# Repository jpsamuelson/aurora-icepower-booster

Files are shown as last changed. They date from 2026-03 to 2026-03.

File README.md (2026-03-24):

# Aurora DSP ICEpower Booster

   

**6-Channel Balanced Audio Interface** — Aurora FreeDSP → ICEpower Amplifier Modules

This board sits between an **Aurora FreeDSP DSP processor** and six **ICEpower Class-D amplifier modules**. It receives 6 balanced audio signals from the DSP, applies adjustable gain (0–11.3 dB), protects the signals, and outputs them as balanced XLR signals.

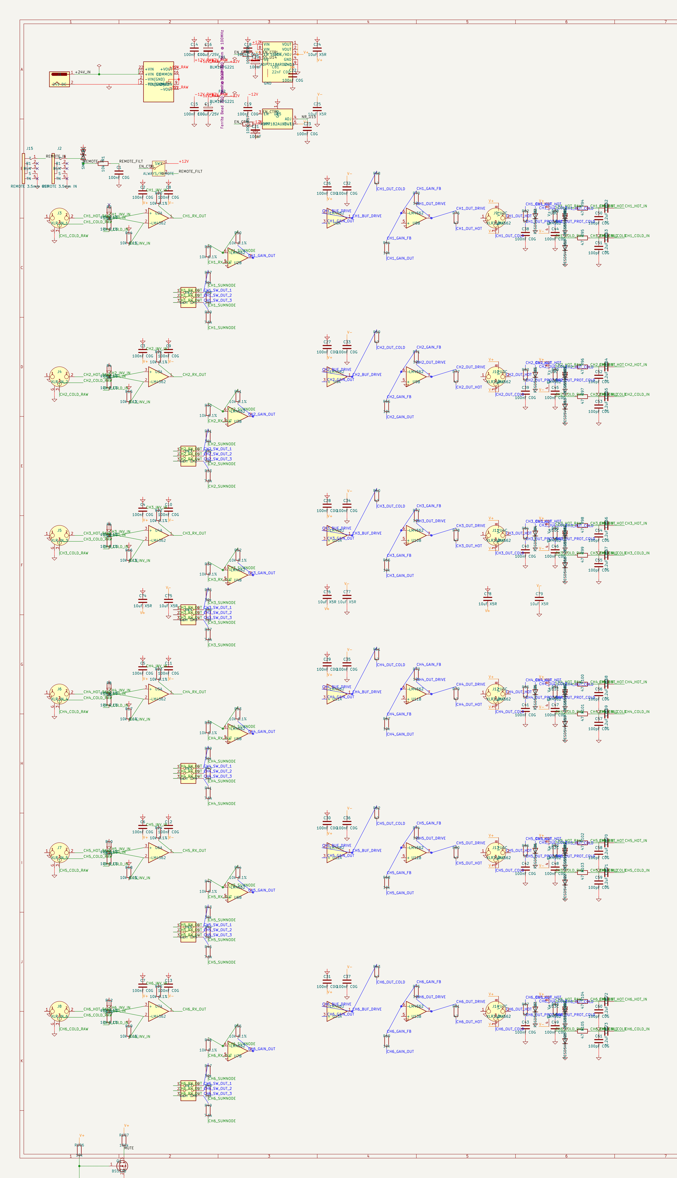
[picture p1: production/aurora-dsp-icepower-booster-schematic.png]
Schematic


---

## Features

- **6 identical channels** — balanced XLR input & output
- **LM4562 low-noise dual op-amps** — THD+N 0.00003%, 2.7 nV/√Hz
- **0–11.3 dB gain** in 8 steps via 3-bit DIP switch per channel
- **100 ms power-on muting** — BSS138 MOSFET chain prevents pop noise
- **Remote enable** via 3.5mm jack (Aurora FreeDSP compatible)
- **Full ESD protection** — PESD5V0S1BL on all signal I/O, SMBJ15CA on remote
- **Isolated power supply** — TRACO TEL5-2422 DC/DC → ADP7118/ADP7182 LDOs (±11V)
- **JLCPCB-ready** — 2-layer FR-4, all components LCSC-available

---

## Specifications

| Parameter | Value |
|---|---|
| Channels | 6 (identical) |
| Input | 6× XLR Female, Pin 2 = Hot, Pin 3 = Cold, Pin 1 = GND |
| Output | 6× XLR Male, Pin 2 = Hot, Pin 3 = Cold, Pin 1 = GND |
| Power Supply | 24V DC (Barrel Jack) |
| Op-Amp Supply | ±11V (low-noise LDO) |
| Gain Range | 0 dB to +11.3 dB (8 steps via DIP switch) |
| Input Impedance | ~10 kΩ balanced |
| Output Impedance | ~47Ω (series R) |
| Input CMRR | ~62 dB (4× 10kΩ 0.1% metal film) |
| SNR Target | > 100 dB |
| THD+N Target | < 0.01% @ 1 kHz |
| Remote Interface | KH-PJ-320EA-5P-SMT 3.5mm jack (Aurora FreeDSP Custom Out) |
| Manufacturing | JLCPCB, 2-Layer, FR-4, HASL, 145.6 × 200 mm |

---

## System Overview

```mermaid
graph LR
    DSP["Aurora FreeDSP\n(6× XLR Out)"]
    BOARD["Aurora DSP\nICEpower Booster"]
    AMP1["ICEpower #1"]
    AMP2["ICEpower #2"]
    AMP3["ICEpower #3"]
    AMP4["ICEpower #4"]
    AMP5["ICEpower #5"]
    AMP6["ICEpower #6"]
    PSU["24V DC\nPower Supply"]
    REMOTE["FreeDSP\nRemote Out"]

    DSP -->|"CH1 XLR Balanced"| BOARD
    DSP -->|"CH2 XLR Balanced"| BOARD
    DSP -->|"CH3 XLR Balanced"| BOARD
    DSP -->|"CH4 XLR Balanced"| BOARD
    DSP -->|"CH5 XLR Balanced"| BOARD
    DSP -->|"CH6 XLR Balanced"| BOARD
    PSU -->|"24V"| BOARD
    REMOTE -->|"3.5mm Enable"| BOARD
    BOARD -->|"CH1 +Gain"| AMP1
    BOARD -->|"CH2 +Gain"| AMP2
    BOARD -->|"CH3 +Gain"| AMP3
    BOARD -->|"CH4 +Gain"| AMP4
    BOARD -->|"CH5 +Gain"| AMP5
    BOARD -->|"CH6 +Gain"| AMP6
```

---

## Signal Chain Overview

All 6 channels are **identical**. Each channel consists of 5 stages:

```mermaid
flowchart LR
    XIN["XLR IN\nJ3–J8"]
    ESD1["ESD Protection\nInput"]
    EMI["EMI Filter\n47Ω + 100pF"]
    DC["DC Blocking\n2.2µF C0G"]
    DIFF["Diff Receiver\nLM4562 Unit A"]
    GAIN["Gain Stage\nLM4562 Unit B"]
    MUTE["Muting\nBSS138"]
    DRV["Balanced Driver\nLM4562 (2nd IC)"]
    ZOB["Zobel\n10Ω + 100nF"]
    ESD2["ESD Protection\nOutput"]
    XOUT["XLR OUT\nJ9–J14"]

    XIN --> ESD1 --> EMI --> DC --> DIFF --> GAIN --> MUTE --> DRV --> ZOB --> ESD2 --> XOUT
```

| Stage | Function | Key Components |
|---|---|---|
| 1. ESD & EMI Filter | Overvoltage protection + RF filtering | PESD5V0S1BL, 47Ω + 100pF, 2.2µF C0G DC blocking |
| 2. Diff Receiver | Balanced → single-ended, CMRR ~62 dB | LM4562 Unit A, 4× 10kΩ 0.1% |
| 3. Gain Stage | Inverting amp, 0–11.3 dB adjustable | LM4562 Unit B, DIP switch + 3 parallel R |
| 4. Muting | Power-on pop suppression, τ = 100 ms | BSS138 N-MOSFET, RC timing |
| 5. Balanced Driver | Single-ended → balanced output | LM4562 (buffer + inverter), 47Ω series R, Zobel network |

**→ [Full signal chain documentation with schematics and formulas](docs/signal-chain.md)**

---

## Gain Configuration

| SW Pos 1 (30kΩ) | SW Pos 2 (15kΩ) | SW Pos 3 (7.5kΩ) | Gain (dB) |
|:---:|:---:|:---:|---:|
| OFF | OFF | OFF | 0.0 dB |
| OFF | OFF | ON | +2.5 dB |
| OFF | ON | OFF | +4.4 dB |
| OFF | ON | ON | +6.0 dB |
| ON | OFF | OFF | +7.4 dB |
| ON | OFF | ON | +8.5 dB |
| ON | ON | OFF | +9.5 dB |
| ON | ON | ON | **+11.3 dB** |

$$G = \frac{R_f}{R_{in,eff}} \quad\text{with}\quad R_{in,eff} = R_{base} \parallel R_{pos1} \parallel R_{pos2} \parallel R_{pos3}$$

**→ [Full gain configuration details](docs/gain-configuration.md)**

---

## PCB Layout

| Parameter | Value |
|---|---|
| Board Size | 145.6 × 200 mm |
| Layers | 2 (F.Cu + B.Cu) |
| Footprints | 269 |
| Nets | 135 in 5 net classes |
| Routing | Freerouting v2.0.1 — 1543 segments + 476 vias |
| GND Zones | F.Cu (solid connect) + B.Cu (thermal relief) |
| DRC | 0 Errors, 0 Unconnected, 198 Warnings (cosmetic) |

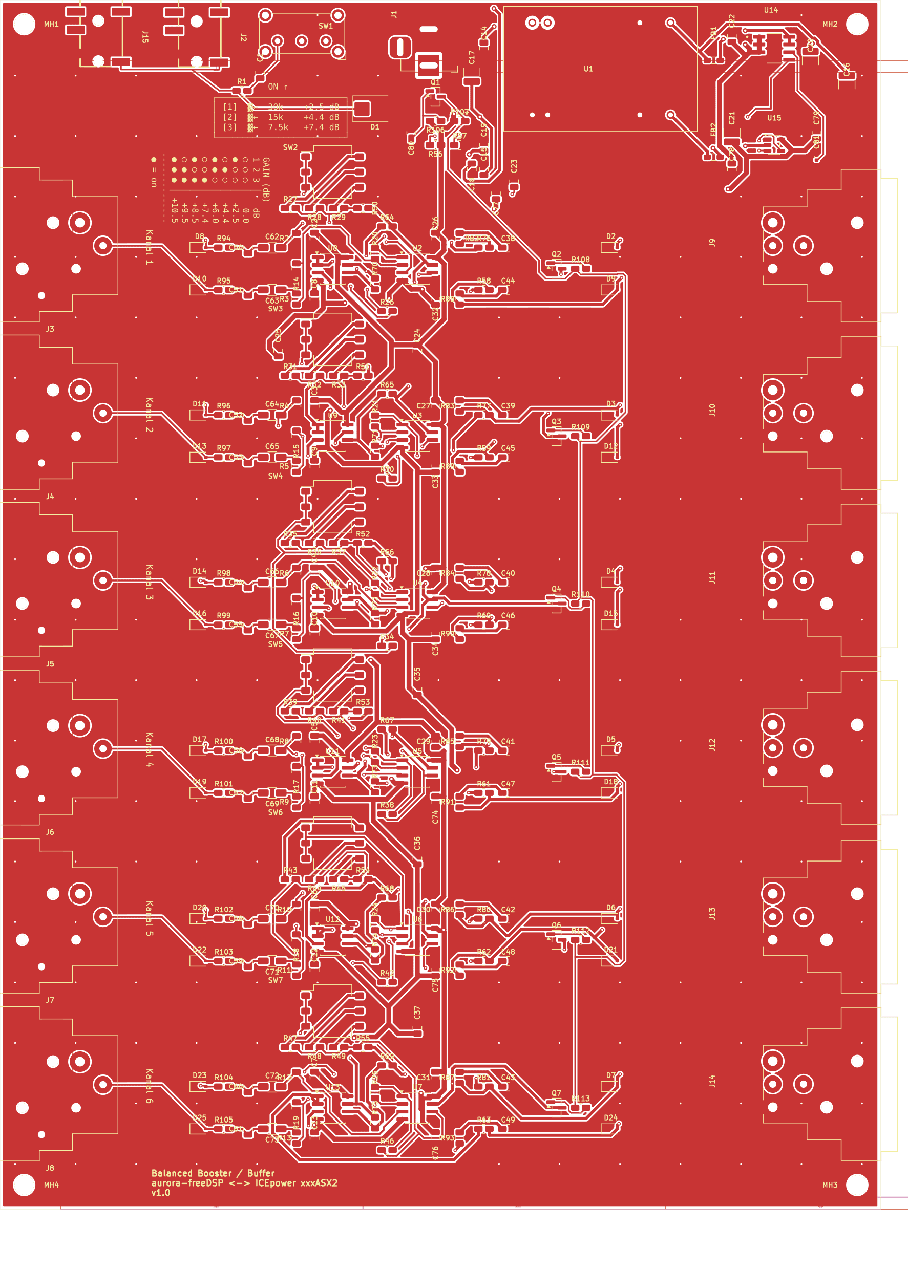
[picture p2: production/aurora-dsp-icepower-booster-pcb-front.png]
PCB Front


| Net Class | Nets | Track Width | Clearance |
|---|---|---|---|
| Default | 62 | 0.25 mm | 0.2 mm |
| Audio_Input | 30 | 0.3 mm | 0.25 mm |
| Audio_Output | 36 | 0.5 mm | 0.2 mm |
| Audio_Power | 0 | 0.8 mm | 0.2 mm |
| Power | 7 | 0.5 mm | 0.2 mm |

**→ [PCB layout details & DRC breakdown](docs/pcb-layout.md)**

---

## Manufacturing

Production files are ready in the `production/` directory:

- **Gerber + Drill** — `production/gerber/` (JLCPCB format, Protel extensions, tented vias)
- **BOM + Placement** — `production/assembly/` (JLCPCB SMT assembly format)

---

## Validation

| Method | Checks | Result |
|---|---|---|
| **Method 1** — OrcadPCB2 netlist, component-centric | 85/85 | ✅ |
| **Method 2** — KiCad-native netlist, net-centric (pintype/pinfunction) | 177/177 | ✅ |

> All component references, net names, and pin assignments in the documentation were extracted directly from the verified KiCad netlist and are sufficient to fully rebuild the schematic without the `.kicad_sch` file.

---

## Documentation

| Document | Description |
|---|---|
| **[Signal Chain](docs/signal-chain.md)** | Detailed 5-stage signal path with Mermaid diagrams, formulas, and per-stage component tables |
| **[Power Supply](docs/power-supply.md)** | DC/DC converter, LDOs, ferrite beads, decoupling architecture |
| **[Muting & Remote Control](docs/muting-and-remote.md)** | Remote enable logic, muting timing, SPDT switch modes |
| **[Gain Configuration](docs/gain-configuration.md)** | DIP switch table, gain formula, per-channel resistor mapping |
| **[Component Reference](docs/component-reference.md)** | Complete BOM with all 242 symbols: R, C, D, J, SW, Q, U, FB |
| **[Schematic Rebuild Guide](docs/schematic-rebuild-guide.md)** | Step-by-step wiring instructions + full 6-channel component mapping |
| **[PCB Layout](docs/pcb-layout.md)** | Net classes, DRC status, routing details |
| **[Research: Balanced Audio ICs](docs/research/balanced-audio-ic-comparison.md)** | THAT1240, DRV135, SSM2143, LM4562 comparison & JLCPCB availability |
| **[Research: THT Precision Components](docs/research/tht-precision-components.md)** | 0.1% resistors, C0G capacitors, THT sourcing guide |

---

## Project Structure

This project is **self-contained** — all footprints and 3D models are included locally.

```
├── aurora-dsp-icepower-booster.kicad_pro   # Project
├── aurora-dsp-icepower-booster.kicad_sch   # Schematic
├── aurora-dsp-icepower-booster.kicad_pcb   # PCB Layout
├── aurora-dsp-icepower-booster.kicad_sym   # Local symbols
├── aurora-dsp-icepower-booster.kicad_dru   # Custom design rules
├── footprints.pretty/                      # 21 footprints (local)
│   └── 3dshapes/                           # 19 STEP 3D models
├── production/
│   ├── gerber/                             # Manufacturing data
│   └── assembly/                           # BOM + placement data
├── docs/                                   # Detailed documentation
│   ├── signal-chain.md
│   ├── power-supply.md
│   ├── muting-and-remote.md
│   ├── gain-configuration.md
│   ├── component-reference.md
│   ├── schematic-rebuild-guide.md
│   ├── pcb-layout.md
│   └── research/
│       ├── balanced-audio-ic-comparison.md
│       └── tht-precision-components.md
└── scripts/                                # Build & validation scripts
```

---

*Schematic: KiCad 9 — `aurora-dsp-icepower-booster.kicad_sch`*
*Manufacturing: JLCPCB 2-Layer FR-4 HASL — Gerber files in `production/gerber/`*

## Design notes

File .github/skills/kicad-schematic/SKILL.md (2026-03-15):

---
name: kicad-schematic
description: "KiCad 9 schematic & PCB manipulation via Python scripts and kicad-cli. USE FOR: editing .kicad_sch files, adding/moving/wiring components, lib_symbols cache management, pin position calculation, ERC/netlist validation, S-expression format manipulation, quality gate checks. TRIGGERS: kicad, schematic, symbol, footprint, wire, net, ERC, DRC, pcb layout, routing, S-expression, lib_symbols, pin position."
argument-hint: "Describe what schematic change or validation you need"
---

# KiCad Schematic & PCB Manipulation

## When to Use

- Editing `.kicad_sch` or `.kicad_pcb` files
- Adding, modifying, or wiring components
- Managing lib_symbols cache entries
- Calculating pin positions for wire routing
- Running ERC/DRC/netlist validation
- Quality gate checks before fabrication
- Any S-expression file manipulation

## Critical Rules (NEVER VIOLATE)

### 1. Terminal — Kein Inline-Python

zsh im Copilot-Terminal korrumpiert heredocs und inline Python.

- **IMMER** `.py`-Datei schreiben → `python3 datei.py` ausführen
- **NIE** `python3 -c "..."` oder `cat << 'EOF'` verwenden
- **NIE** mehrzeiligen Python-Code im Terminal ausführen

### 2. S-Expression — Klammer-Balance

Nach JEDER Dateiänderung muss die Klammer-Balance geprüft werden:

```python
depth = 0
for ch in content:
    if ch == '(': depth += 1
    elif ch == ')': depth -= 1
assert depth == 0, f"Klammer-Balance: {depth}"
```

### 3. lib_symbols Cache — Sub-Symbol-Naming

Beim Hinzufügen neuer Symbole zur `lib_symbols`-Sektion:

- **Hauptsymbol**: MIT Library-Prefix → `(symbol "Connector_Audio:AudioJack2" ...)`
- **Sub-Symbole**: OHNE Library-Prefix → `(symbol "AudioJack2_0_1" ...)`
- **NIEMALS**: `(symbol "Connector_Audio:AudioJack2_0_1" ...)` — crasht kicad-cli!

### 4. Regex — Keine Cross-Symbol-Suche

`.search(r'lib_id "X".*?Reference.*?J14', text, DOTALL)` matcht über Symbol-Grenzen hinweg.
**Immer** Balanced-Paren-Block zuerst extrahieren, dann darin suchen.
Siehe [S-Expression Reference](./references/s-expression-format.md).

### 5. Validierung — Dreistufig nach jeder Änderung

1. Klammer-Balance prüfen (Python)
2. `kicad-cli sch export netlist` (testet Parser)
3. `kicad-cli sch erc --severity-all` (Baseline-Vergleich)

## Workflow: Schematic-Änderung

```
1. Backup erstellen (.bak_pre_<aktion>)
2. Änderung via Python-Skript
3. Klammer-Balance prüfen
4. kicad-cli Netlist-Export testen
5. kicad-cli ERC ausführen (Baseline: 115 Errors)
6. Netz-Verbindungen im Netlist verifizieren
7. Ergebnis zusammenfassen
```

### Backup-Konvention

```bash
cp aurora-dsp-icepower-booster.kicad_sch aurora-dsp-icepower-booster.kicad_sch.bak_pre_<aktion>
```

## Workflow: Neues Symbol in Schematic einfügen

1. Symbol aus KiCad System-Library extrahieren:
   ```
   /Applications/KiCad/KiCad.app/Contents/SharedSupport/symbols/<Library>.kicad_sym
   ```
2. Hauptsymbol-Block mit Balanced-Paren-Extraktion lesen
3. Sub-Symbol-Naming korrigieren (Library-Prefix entfernen)
4. In lib_symbols-Sektion der .kicad_sch einfügen
5. Symbol-Instanz mit korrekten Properties einfügen
6. Wires und Labels hinzufügen
7. Validierung durchführen

Details: [S-Expression Format Reference](./references/s-expression-format.md)

## Workflow: Wire-Routing

1. Pin-Positionen berechnen (siehe [Pin-Kalkulation](./references/pin-calculation.md))
2. Wire-Segmente als S-Expression erzeugen
3. Labels an Endpunkten platzieren
4. Junctions an Kreuzungspunkten einfügen
5. Validierung via Netlist

## Workflow: Validierung / Quality Gate

Nutze [validate_schematic.py](./scripts/validate_schematic.py) als Basis:

```bash
python3 .github/skills/kicad-schematic/scripts/validate_schematic.py
```

Prüft automatisch:

- Klammer-Balance
- kicad-cli Netlist-Export
- kicad-cli ERC (Baseline-Vergleich)
- Netz-Verbindungen (konfigurierbar)
- Footprint-Existenz
- lib_symbols-Cache-Integrität

## Pin-Naming nach Bibliothek

| Library | Pin-Format | Beispiele |
| --- | --- | --- |
| Device:R, Device:C | Nummern | "1", "2" |
| Connector_Audio:AudioJack2 | Buchstaben | "T" (Tip), "S" (Sleeve) |
| Connector_Audio:XLR3 | Mixed | "1", "2", "3", "G" |
| Connector:Barrel_Jack | Nummern | "1", "2" |
| Amplifier_Operational:LM4562 | Nummern | "1"-"8" |

**Regex für Pin-Matching**: Immer `[^"]+` statt `\d+` verwenden!

## MCP Server — Wann nutzen, wann nicht

| Geeignet | Nicht geeignet |
| --- | --- |
| `open_project`, `get_project_info` | Bulk-Verdrahtung (>10 Wires) |
| `search_symbols`, `search_footprints`  | Multi-Unit-Symbole (extends-Bug) |
| `get_board_info`, `get_component_list` | Zuverlässiges Wire-Routing |
| `export_gerber`, `export_bom` | Schaltpläne >50 Bauteile |
| `sync_schematic_to_board` | Rotation von Bauteilen |

Für alles Komplexe: Python-Skripte + kicad-cli.

## Dateipfade

| Was | Pfad |
| --- | --- |
| Projekt | `/Users/roroor/Documents/Workspace/CAD/Electric/aurora-dsp-icepower-booster/` |
| kicad-cli | `/Applications/KiCad/KiCad.app/Contents/MacOS/kicad-cli` |
| Symbol-Libraries | `/Applications/KiCad/KiCad.app/Contents/SharedSupport/symbols/` |
| Footprint-Libraries | `/Applications/KiCad/KiCad.app/Contents/SharedSupport/footprints/` |
| Custom Symbols | `aurora-dsp-icepower-booster.kicad_sym` |

## ERC Baseline

- **0 Errors** (runterreduziert von 115→66→0)
- **805 Warnings** — Aufschlüsselung:
  - 799 endpoint_off_grid (kosmetisch, MCP-Server 1mm-Raster vs. KiCad 1.27mm — Grid-Snap nicht sicher möglich wegen 25 2D-Kollisionen)
  - 6 label_multiple_wires (SUMNODE T-Kreuzungen — Labels für Netz-Konnektivität nötig, nicht entfernbar)
- **52 echte Warnungen eliminiert** (890→805): 39 isolierte Label-Stubs gelöscht, 6 ???-Stubs mit korrektem XLR-Pin verbunden, 1 Footprint korrigiert
- Neue Änderungen dürfen die Error-Zahl NICHT erhöhen
- Behobene Kategorien: missing_power_pin (12→0), pin_not_connected (19→0), label_dangling (12→0), pin_to_pin (6→0), wire_dangling (66→0), multiple_net_names (6→0), lib_symbol_mismatch (194→0), footprint_link_issues (18→0), unconnected_wire_endpoint (45→0)
- multiple_net_names Fix: CHx_HOT_RAW → CHx_OUT_COLD umbenannt (12 Labels)
- lib_symbols Fix: Device:R, Device:C, Device:D Cache von KiCad 9 Library aktualisiert
- Footprint Fix: XLR-F/M → Neutrik NC3FBH2/NC3MBH, DIP Switch → korrekter Name, TEL5-2422 → Package_DIP:DIP-24_W15.24mm
- Stub Fix: 39 isolierte V+/V-/GND/OUT_COLD Label-Stubs gelöscht (komplett isoliert, keine Konnektivitätsänderung), 6 XLR-Cold-Stubs mit Pin 2 der XLR-Eingangsbuchsen verbunden (MCP-Server Y-Vorzeichen-Fehler korrigiert)
- Neue Netze pro Kanal: INV_IN, SW_OUT_1/2/3, BUF_DRIVE, GAIN_FB, OUT_DRIVE, OUT_PROT_HOT/COLD, EMI_HOT/COLD

## Audio-PCB-Design-Regeln

Vollständige Regeln in [copilot-instructions.md](../../../.github/copilot-instructions.md).
Kurzfassung:

- Ungeteilte GND-Fläche auf B.Cu
- Audio-Traces auf Top-Layer, keine Vias im Signalpfad
- Kein X7R/X5R im Audio-Signalpfad (Mikrofonie!)
- Entkopplung: 100nF C0G direkt am IC + 10µF dahinter
- Schaltregler ≥ 20mm von Audio-Eingangsstufe
- Guard-Traces um empfindliche Audio-Eingänge

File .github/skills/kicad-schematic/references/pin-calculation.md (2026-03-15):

# Pin-Position-Berechnung

## Grundformel

Für ein Symbol an Position `(sx, sy)` mit Rotation `θ` (in Grad):

```
Pin lokal:     (px, py)        ← aus lib_symbols Cache
Rotiert:       (rx, ry) = rotate_ccw(px, py, θ)
Schematisch:   (sx + rx, sy - ry)    ← KiCad Y-Achse invertiert!
```

## Rotation (Counter-Clockwise)

```python
import math

def pin_schematic_position(symbol_x, symbol_y, symbol_rot_deg, pin_local_x, pin_local_y):
    """Berechnet die Schematic-Position eines Pins."""
    theta = math.radians(symbol_rot_deg)
    # CCW-Rotation
    rx = pin_local_x * math.cos(theta) - pin_local_y * math.sin(theta)
    ry = pin_local_x * math.sin(theta) + pin_local_y * math.cos(theta)
    # KiCad: Y-Achse invertiert
    sch_x = symbol_x + rx
    sch_y = symbol_y - ry
    return round(sch_x, 2), round(sch_y, 2)
```

## Schnell-Referenz für Standard-Rotationen

| Symbol-Rotation | Transformation (px, py) → (rx, ry) | Schematic |
|---|---|---|
| 0° | (px, py) → (px, py) | (sx + px, sy - py) |
| 90°  | (px, py) → (-py, px) | (sx - py, sy - px) |
| 180° | (px, py) → (-px, -py) | (sx - px, sy + py) |
| 270° | (px, py) → (py, -px) | (sx + py, sy + px) |

## Beispiel: AudioJack2 bei (40.16, 82.46) @ 180°

```
Pin T lokal: (5.08, 0)
  → rot 180°: (-5.08, 0)
  → schematic: (40.16 + (-5.08), 82.46 - 0) = (35.08, 82.46)

Pin S lokal: (5.08, 2.54)
  → rot 180°: (-5.08, -2.54)
  → schematic: (40.16 + (-5.08), 82.46 - (-2.54)) = (35.08, 85.0)
```

## Pin-Positionen aus lib_symbols lesen

```python
import re

def get_pin_positions(cache_block, symbol_name):
    """Liest Pin-Positionen aus einem lib_symbols Cache-Block."""
    pins = {}
    # Finde Sub-Symbol mit den Pins (typisch: _0_1)
    for m in re.finditer(r'\(pin \w+ \w+ \(at ([\d.]+) ([\d.]+) (\d+)\).*?\(number "([^"]+)"\)', cache_block, re.DOTALL):
        px, py = float(m.group(1)), float(m.group(2))
        pin_angle = int(m.group(3))
        pin_number = m.group(4)
        pins[pin_number] = (px, py, pin_angle)
    return pins
```

## Wire-Endpunkt = Pin-Schematic-Position

Ein Wire muss **exakt** an der berechneten Pin-Schematic-Position beginnen/enden.
Toleranz: ±0.01mm (KiCad-internes Raster).

**WICHTIG**: MCP-erstellte Wires verbinden Pins nur zuverlässig, wenn mindestens ein **Net-Label** im Wire-Chain vorhanden ist. Ohne Label erkennt KiCad die Pin-Verbindung möglicherweise nicht!

```python
# Wire von Pin zu Label (bevorzugt — Label sorgt für zuverlässige Netz-Erkennung)
wire = f'(wire (pts (xy {pin_x} {pin_y}) (xy {label_x} {label_y})) (stroke (width 0) (type default)) (uuid "{uuid}"))'
label = f'(label "{net_name}" (at {label_x} {label_y} 0) (fields_autoplaced yes) (effects (font (size 1.27 1.27)) (justify left bottom)) (uuid "{label_uuid}"))'
```

## Pin-Richtung (für Wire-Routing)

Der `pin_angle` (0°, 90°, 180°, 270°) gibt die Richtung an, in die der Pin zeigt.
Wire sollte in die **entgegengesetzte** Richtung verlaufen:

| Pin-Winkel | Pin zeigt nach | Wire geht nach |
|---|---|---|
| 0° | Rechts | Links vom Pin  |
| 90° | Oben | Unten vom Pin  |
| 180° | Links | Rechts vom Pin |
| 270° | Unten | Oben vom Pin |

Bei 180°-Pin (zeigt nach links): Wire geht nach rechts → höhere X-Koordinaten.

## Häufig verwendete Symbol-Positionen

### LM4562 (SOIC-8, keine Rotation)

**ACHTUNG**: Die Pin-Positionen stammen aus dem lib_symbols-Cache des Schaltplans.
Immer mit `get_lib_pins()` verifizieren — sie können von KiCad-Version zu Version variieren!

| Pin | Nummer | Lokal (x,y) | Bei (80, 110) @ 0° |
|-----|---|---|---|
| Out A | 1 | (7.62, 0) | (87.62, 110) |
| -In A | 2 | (-7.62, -2.54) | (72.38, 112.54) |
| +In A | 3 | (-7.62, 2.54) | (72.38, 107.46) |
| V- | 4 | (-2.54, -7.62) | (77.46, 117.62) |
| +In B | 5 | (-7.62, 2.54) | (72.38, 107.46) |
| -In B | 6 | (-7.62, -2.54) | (72.38, 112.54) |
| Out B | 7 | (7.62, 0) | (87.62, 110) |
| V+ | 8 | (-2.54, 7.62) | (77.46, 102.38) |

*Pins 5-7 gelten für Unit 2 an eigener (at)-Position.*
*Pins 4+8 gelten für Unit 3 (Power) an eigener (at)-Position.*

### Barrel_Jack (keine Rotation)
| Pin | Lokal (x,y) |
|-----|---|
| 1 (Center/+) | (5.08, 0) |
| 2 (Barrel/GND) | (5.08, 5.08) |

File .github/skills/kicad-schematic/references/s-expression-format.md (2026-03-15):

# S-Expression Format Reference

## KiCad .kicad_sch Dateistruktur

```
(kicad_sch (version ...) (generator ...) (generator_version ...)
  (uuid "...")
  (paper "A1")
  (lib_symbols
    (symbol "Library:SymbolName" ...)     ← Cache aller verwendeten Symbole
    (symbol "Library:AnotherSymbol" ...)
  )
  (wire (pts ...) ...)                     ← Wires
  (label "NetName" (at X Y A) ...)         ← Net-Labels
  (junction (at X Y) ...)                  ← Junctions
  (symbol (lib_id "Library:Symbol")        ← Symbol-Instanzen
    (at X Y Rotation) 
    (property "Reference" "R1" ...)
    (property "Value" "10k" ...)
    (property "Footprint" "..." ...)
    ...
  )
  (sheet_instances ...)                     ← Optional
)
```

## Symbol-Block extrahieren (Balanced-Paren-Methode)

**IMMER diese Methode verwenden**, nie Regex über die ganze Datei:

```python
def extract_block(text, start_idx):
    """Extrahiert den balancierten Klammer-Block ab start_idx."""
    depth = 0
    for i in range(start_idx, len(text)):
        if text[i] == '(':
            depth += 1
        elif text[i] == ')':
            depth -= 1
            if depth == 0:
                return text[start_idx:i+1]
    return None
```

### Symbol finden und Block extrahieren

```python
import re

def find_symbol_by_reference(sch_text, reference):
    """Findet den Symbol-Block für eine bestimmte Reference (z.B. 'J14')."""
    # Alle Symbol-Starts finden
    for m in re.finditer(r'\(symbol \(lib_id "([^"]+)"\)\s*\(at', sch_text):
        block_start = m.start()
        block = extract_block(sch_text, block_start)
        if block and f'"Reference" "{reference}"' in block:
            return m.group(1), block  # (lib_id, full_block)
    return None, None
```

## lib_symbols Cache — Korrekte Struktur

```
(symbol "Connector_Audio:AudioJack2"       ← MIT Library-Prefix
  (exclude_from_sim no)
  (in_bom yes) (on_board yes)
  (property "Reference" "J" ...)
  (property "Value" "AudioJack2" ...)
  (property "Footprint" "" ...)
  (symbol "AudioJack2_0_1"                 ← OHNE Library-Prefix!
    (polyline ...)
    (pin passive line (at 5.08 0 180) 
      (length 2.54)
      (name "~" ...) (number "T" ...))     ← Pin T
    (pin passive line (at 5.08 2.54 180) 
      (length 2.54)  
      (name "~" ...) (number "S" ...))     ← Pin S
  )
  (symbol "AudioJack2_1_1"                 ← OHNE Library-Prefix!
    ...
  )
)
```

### Sub-Symbol-Naming-Regeln
- Format: `{SymbolName}_{unit}_{variant}`
- unit: 0-basiert (0 = graphisches, 1+ = Units)
- variant: 1 (Standard)
- **Kein Library-Prefix** bei Sub-Symbolen
- Vergleich mit funktionierenden Einträgen: `XLR3_Ground_0_1`, `Barrel_Jack_0_1`

### Symbol aus System-Library extrahieren

```python
def extract_from_system_library(library_name, symbol_name):
    """Liest ein Symbol aus der KiCad-Systembibliothek."""
    lib_path = f"/Applications/KiCad/KiCad.app/Contents/SharedSupport/symbols/{library_name}.kicad_sym"
    with open(lib_path) as f:
        lib_text = f.read()
    
    # Hauptsymbol finden
    idx = lib_text.find(f'(symbol "{symbol_name}"')
    if idx < 0:
        return None
    
    block = extract_block(lib_text, idx)
    
    # Für lib_symbols Cache: Library-Prefix zum Hauptsymbol hinzufügen
    # aber NOT zu Sub-Symbolen
    prefixed = block.replace(
        f'(symbol "{symbol_name}"',
        f'(symbol "{library_name}:{symbol_name}"',
        1  # Nur das erste Vorkommen (Hauptsymbol)
    )
    return prefixed
```

## S-Expression Templates

### Wire
```
(wire (pts (xy {x1} {y1}) (xy {x2} {y2})) (stroke (width 0) (type default)) (uuid "{uuid}"))
```

### Label
```
(label "{net_name}" (at {x} {y} {angle}) (fields_autoplaced yes) (effects (font (size 1.27 1.27)) (justify left)) (uuid "{uuid}"))
```

### Junction
```
(junction (at {x} {y}) (diameter 0) (color 0 0 0 0) (uuid "{uuid}"))
```

### GND Power Symbol
```
(symbol (lib_id "power:GND") (at {x} {y} 0) (unit 1) (exclude_from_sim no) (in_bom yes) (on_board yes) (dnp no) (uuid "{uuid}") (property "Reference" "#PWR0{n}" (at {x} {y+1.27} 0) (effects (font (size 1.27 1.27)) hide)) (property "Value" "GND" (at {x} {y+1.016} 0) (effects (font (size 1.27 1.27)) hide)))
```

### Symbol-Instanz
```
(symbol (lib_id "{library}:{symbol}") (at {x} {y} {rotation}) (unit 1) (exclude_from_sim no) (in_bom yes) (on_board yes) (dnp no) (uuid "{uuid}") (property "Reference" "{ref}" (at {rx} {ry} 0) (effects (font (size 1.27 1.27)))) (property "Value" "{value}" (at {vx} {vy} 0) (effects (font (size 1.27 1.27)))) (property "Footprint" "{footprint}" (at {x} {y} 0) (effects (font (size 1.27 1.27)) hide)) (property "Datasheet" "~" (at {x} {y} 0) (effects (font (size 1.27 1.27)) hide)))
```

### Property-Offset-Konventionen
- Reference: (x, y - 2.54) relativ zum Symbol-Zentrum
- Value: (x, y + 2.54) relativ zum Symbol-Zentrum
- Bei Rotation 90°: Offsets rotieren mit

## Einfüge-Position in der Datei

Neue Elemente vor der letzten schließenden Klammer einfügen:

```python
def insert_before_end(sch_text, new_element):
    """Fügt Element vor der letzten ')' der Datei ein."""
    last_paren = sch_text.rfind(')')
    return sch_text[:last_paren] + ' ' + new_element + ')'
```

Für lib_symbols Cache:

```python
def insert_in_lib_symbols(sch_text, new_symbol_def):
    """Fügt Symbol-Definition in die lib_symbols-Sektion ein."""
    # Ende der lib_symbols-Sektion finden
    lib_start = sch_text.find('(lib_symbols')
    if lib_start < 0:
        return None
    block_end_idx = find_balanced_end(sch_text, lib_start)
    # Vor der schließenden Klammer von lib_symbols einfügen
    return sch_text[:block_end_idx] + ' ' + new_symbol_def + sch_text[block_end_idx:]
```

## Häufige Fehlerquellen

### Greedy Regex (GEFÄHRLICH)
```python
# FALSCH — matcht über Symbol-Grenzen:
re.search(r'lib_id "([^"]+)".*?Reference.*?J14', text, re.DOTALL)

# RICHTIG — erst Block extrahieren:
lib_id, block = find_symbol_by_reference(text, "J14")
```

### Pin-Nummer als reine Zahl
```python
# FALSCH — matcht keine Buchstaben-Pins:
re.findall(r'pin "(\d+)"', block)

# RICHTIG:
re.findall(r'pin "([^"]+)"', block)
```

### Einfach-Zeilen-Format
Die .kicad_sch Datei kann ein einzeiliges S-Expression-Format haben (kein `\n`).
- `replace_string_in_file` ist unzuverlässig für solche Dateien
- Immer Python-Skripte für Manipulation verwenden
- `grep` / `sed` funktionieren nicht zuverlässig

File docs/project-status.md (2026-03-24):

# Project Status

> This file contains volatile project data (counts, coordinates, DRC results).
> Updated separately from the stable design rules in `.github/copilot-instructions.md`.

---

## Schematic Status

- **242 symbols**: 104 R, 64+4 C, 24 D (TVS), 15 U, 13 J, 6 SW
- **143 nets**, schematic exports cleanly
- **ERC**: 0 errors (reduced from 115→66→0), 890 warnings (838 off-grid, acceptable)
- All fixes (F1-F10) verified and passed

---

## PCB Routing Status (Commit bf62bd0)

- **0 Errors, 0 Unconnected, 198 Warnings** (all acceptable)
- 1543 trace segments + 476 vias via Freerouting v2.0.1
- 2 GND zones: F.Cu (solid connect) + B.Cu (thermal)
- 269 footprints, 135 nets in 5 classes

### DRC Breakdown (198 Warnings)

- 138× holes_co_located, 27× silk_edge_clearance, 11× silk_overlap
- 10× silk_over_copper, 9× hole_to_hole, 3× via_dangling

### Net Classes

| Class | Nets | Track  | Clearance |
| --- | ---- | --- | --- |
| Default | 62 | 0.25mm | 0.2mm |
| Audio_Input  | 30 | 0.3mm  | 0.25mm |
| Audio_Output | 36 | 0.5mm  | 0.2mm |
| Audio_Power  | 0 | 0.8mm  | 0.2mm |
| Power | 7 | 0.5mm  | 0.2mm |

---

## Next Steps

1. Remove dangling vias (3 total)
2. Export Gerber + drill files
3. Export BOM + placement data
4. Visual inspection in KiCad

---

## Reference Data

### Wire Dangling Fix Reference

- Wire-to-pin connections work reliably ONLY with at least one net label
- Fix: add `(label "NET_NAME" (at x y 0) ...)` at every dangling endpoint

### Channel Net Names (11 nets × 6 channels = 66)

CHn_INV_IN, CHn_SW_OUT_1/2/3, CHn_BUF_DRIVE, CHn_GAIN_FB, CHn_OUT_DRIVE, CHn_OUT_PROT_HOT, CHn_OUT_PROT_COLD, CHn_EMI_HOT, CHn_EMI_COLD

### Key Coordinates

- Channels: CY = 110 + (ch-1) × 80, for ch=1..6
- Input protection: X_PROT = 280
- Output Zobel HOT: X=265, COLD: X=280

### S-Expression Templates

```
Symbol: (symbol (lib_id "LIB") (at X Y A) (unit 1) (in_bom yes) (on_board yes) (dnp no) (uuid "UUID") (property "Reference" ...) ...)
Wire:   (wire (pts (xy X1 Y1) (xy X2 Y2)) (stroke (width 0) (type default)) (uuid "UUID"))
Label:  (label "NAME" (at X Y A) (fields_autoplaced yes) (effects ...) (uuid "UUID"))
```

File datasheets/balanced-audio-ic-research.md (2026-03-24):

# Balanced Audio Line Receiver & Driver ICs — Research Report

**Projekt:** Aurora DSP IcePower Booster  
**Datum:** 2026-03-12  
**Zweck:** Vergleich dedizierter Balanced-Audio-ICs vs. diskrete LM4562-Lösung

---

## 1. THAT Corporation — InGenius Receivers & OutSmarts Drivers

### 1.1 THAT1240 — Balanced Line Receiver (InGenius)

| Parameter | Wert |
|---|---|
| **Funktion** | Balanced → Single-Ended, 1 Kanal |
| **Topologie** | InGenius™ — patentierte Kombination aus Current-Feedback + Servo |
| **Gain** | Unity (0 dB) |
| **Package** | DIP-8 (THAT1240P08), SOIC-8 (THAT1240S08) |
| **CMRR** | >90 dB DC bis 20 kHz (typ.) |
| **CMRR bei Quellenimpedanz-Mismatch** | >60 dB auch bei 10% Source-Mismatch! |
| **THD+N** | 0.0004% typ. @ 1 kHz |
| **Noise** | -103 dBu (A-weighted) |
| **Bandwidth** | ~4 MHz |
| **Slew Rate** | ~8 V/µs |
| **Max. Input Level** | +26 dBu @ ±18V Supply |
| **Supply** | ±5V bis ±18V |
| **Quiescent Current** | ~4.5 mA |
| **Preis (Mouser/DigiKey)** | ~$3.50–$5.00 |
| **LCSC/JLCPCB** | ❌ **NICHT VERFÜGBAR** |

**Besonderheit:** Der entscheidende Vorteil der InGenius-Topologie ist, dass der CMRR auch bei unbalancierten Quellenimpedanzen hoch bleibt. Ein Standard-Differenzverstärker (z.B. INA134, SSM2143) verliert seinen CMRR proportional zum Impedanz-Mismatch an den Eingängen — bei realen Verkabelungsszenarien oft dramatisch. InGenius umgeht dies durch einen Servo-Loop, der die Eingangsimpedanz dynamisch anpasst.

### 1.2 THAT1246 — Balanced Line Receiver (InGenius, +6 dB)

| Parameter | Wert |
|---|---|
| **Funktion** | Balanced → SE, 1 Kanal, **Gain = 2 (+6 dB)** |
| **Topologie** | InGenius™ (identisch zu THAT1240) |
| **Package** | DIP-8, SOIC-8 |
| **Alle Specs** | Wie THAT1240, aber G = 2 |
| **LCSC/JLCPCB** | ❌ **NICHT VERFÜGBAR** |

Der THAT1246 wird bevorzugt, wenn der Receiver den -6 dB Pegelverlust der professionellen Balanced-Leitung (±halber Pegel) kompensieren soll, was bei G=2 exakt Unity-Gain über den gesamten Signalpfad ergibt.

### 1.3 THAT1200 — Balanced Line Receiver (Vorgänger)

| Parameter | Wert |
|---|---|
| **Funktion** | Balanced → SE, 1 Kanal |
| **Topologie** | Standard-Differenzverstärker mit getrimmed Resistoren |
| **CMRR** | ~70 dB typ. (deutlich schlechter als 1240-Serie) |
| **Package** | DIP-8, SOIC-8 |
| **Status** | Superseded by THAT1240 series |
| **LCSC/JLCPCB** | ❌ **NICHT VERFÜGBAR** |

**Bewertung:** Veraltet, kein Grund die 1200er-Serie zu verwenden. Die 1240er ist in jeder Hinsicht überlegen.

### 1.4 THAT1606 — Balanced Line Driver (OutSmarts)

| Parameter | Wert |
|---|---|
| **Funktion** | Single-Ended → Balanced, 1 Kanal |
| **Topologie** | OutSmarts™ — kreuzgekoppelt mit Servo-Feedback |
| **Gain** | Unity (0 dB) |
| **Package** | SOIC-8 |
| **THD+N** | 0.0003% typ. @ 1 kHz |
| **Output Balance** | >60 dB auch bei unbalancierter Last |
| **Noise** | -107 dBu (A-weighted) |
| **Max. Output** | +24 dBu @ ±18V Supply |
| **Slew Rate** | ~15 V/µs |
| **Supply** | ±5V bis ±18V |
| **Quiescent Current** | ~6.5 mA |
| **Preis (Mouser/DigiKey)** | ~$4.00–$6.00 |
| **LCSC/JLCPCB** | ❌ **NICHT VERFÜGBAR** |

**Besonderheit:** Die OutSmarts-Topologie hält die Ausgangsbalance auch bei unbalancierten Lasten aufrecht (z.B. wenn nur ein Pin belastet wird). Ein Standard Cross-Coupled Driver (wie DRV134) verliert hier Balance. Zusätzlich ermöglicht OutSmarts eine "elektronische Impedanzbalancierung", die die Gleichtaktunterdrückung am Empfänger verbessert.

### 1.5 THAT1646 — Balanced Line Driver (OutSmarts, +6 dB)

| Parameter | Wert |
|---|---|
| **Funktion** | SE → Balanced, 1 Kanal, **Gain = 2 (+6 dB)** |
| **Topologie** | OutSmarts™ (identisch zu THAT1606) |
| **Package** | SOIC-8 |
| **Alle Specs** | Wie THAT1606, aber G = 2 |
| **LCSC/JLCPCB** | ❌ **NICHT VERFÜGBAR** |

---

## 2. TI/Burr-Brown — DRV134/DRV135 Line Drivers

### 2.1 DRV134 — Audio Balanced Line Driver (PDIP-8 / SOIC-16)

| Parameter | Wert |
|---|---|
| **Funktion** | SE → Balanced, 1 Kanal |
| **Topologie** | Cross-coupled mit Precision-Resistoren |
| **Package** | PDIP-8 (DRV134PA), SOIC-16 (DRV134UA) |
| **THD+N** | 0.0005% typ. @ 1 kHz |
| **Slew Rate** | 15 V/µs |
| **Max. Output** | 17 Vrms into 600 Ω |
| **Supply** | ±4.5V bis ±18V (9–36V) |
| **Quiescent Current** | 5.2 mA |
| **Preis (TI 1ku)** | ~$2.28–$2.74 |
| **Status** | **ACTIVE** — Improved replacement for SSM2142 |

**LCSC-Verfügbarkeit:**

| Part Number | Package | Bestand | Preis (1 Stk) |
|---|---|---|---|
| DRV134PA | PDIP-8 | 0 (nachbestellbar) | $6.29 |
| DRV134UA/1K | SOIC-16 | 5 Stk | $5.95 |

⚠️ **Sehr geringer LCSC-Bestand. SOIC-16 ist für Audio-PCB ungünstig (groß). PDIP-8 nicht SMT-tauglich für JLCPCB Assembly.**

### 2.2 DRV135 — Audio Balanced Line Driver (SOIC-8)

| Parameter | Wert |
|---|---|
| **Funktion** | SE → Balanced, 1 Kanal |
| **Topologie** | Identisch zu DRV134 |
| **Package** | **SOIC-8** (platzsparend!) |
| **Alle Specs** | Identisch zu DRV134 |
| **Status** | **ACTIVE** |

**LCSC-Verfügbarkeit:**

| Part Number | Package | Bestand | Preis (1 Stk) |
|---|---|---|---|
| DRV135UA | SOIC-8 | 0 (nachbestellbar) | $3.46 |
| DRV135UA/2K5 | SOIC-8 | **3.865 Stk** ✅ | **$2.78** |

✅ **DRV135UA/2K5 ist der beste Kandidat unter den dedizierten Line-Drivern für JLCPCB Assembly!** Guter Bestand, SOIC-8 Package, vernünftiger Preis.

### 2.3 INA1634 (TI)

| Parameter | Wert |
|---|---|
| **Status** | ❌ **Existiert nicht** (TI-Webseite gibt 404) |

**Hinweis:** Die existierenden TI-Differential-Receiver für Audio sind:

- **INA134** — Differential Line Receiver, G = 1, SOIC-8/DIP-8 (Companion zu DRV134)
- **INA137** — Differential Line Receiver, G = 1/2, SOIC-8/DIP-8

Diese haben ~80 dB CMRR, aber leiden wie alle Standard-Differenzverstärker unter CMRR-Degradierung bei Quellenimpedanz-Mismatch.

---

## 3. Analog Devices — SSM2142/SSM2143

### 3.1 SSM2142 — Balanced Line Driver

| Parameter | Wert |
|---|---|
| **Funktion** | SE → Balanced, 1 Kanal |
| **Status** | ⛔ **OBSOLETE** |
| **Package** | DIP-8 (nur!) |
| **THD** | 0.006% typ., 20 Hz–20 kHz, 10V RMS in 600 Ω |
| **CMRR** | 80 dB |
| **Slew Rate** | 15 V/µs |
| **Max. Output** | 10V RMS into 600 Ω |
| **Supply** | ±15V (fix, kein weiter Bereich) |

**LCSC-Verfügbarkeit:**

| Part Number | Bestand | Preis |
|---|---|---|
| SSM2142PZ | 0 | $149.83 (!) |
| SSM2142SZ (3rd party) | 95 | $78.52 |

⛔ **NICHT VERWENDEN. Obsolete, absurd teuer, nur DIP-8, schlechtere Specs als DRV134/135.**

### 3.2 SSM2143 — Differential Line Receiver

| Parameter | Wert |
|---|---|
| **Funktion** | Balanced → SE, 1 Kanal |
| **Status** | ⛔ **OBSOLETE** |
| **Package** | SOIC-8 (SSM2143S/SZ), PDIP-8 (SSM2143P) |
| **CMRR** | 90 dB @ DC/60 Hz, 85 dB @ 20 kHz |
| **THD** | 0.0006% typ. @ 1 kHz |
| **Slew Rate** | 10 V/µs |
| **Bandwidth** | 7 MHz (G = 1/2) |
| **Gain** | G = 1/2 (oder G = 2 durch Pin-Swap) |
| **Max. Input** | +28 dBu @ G = 1/2 |
| **Supply** | ±5V bis ±18V |
| **Replacement** | AD8273 (von ADI empfohlen) |

**LCSC-Verfügbarkeit:**

| Part Number | Bestand | Preis |
|---|---|---|
| SSM2143S | Discontinued | — |
| SSM2143P | Discontinued | — |
| SSM2143SZ | 0 (SOIC-8) | $8.83 |
| SSM2143S-REEL | Discontinued | — |

⚠️ **Obsolete und schlecht verfügbar. Der SSM2143 war ein sehr guter IC, aber nicht mehr empfehlenswert für neue Designs.**

---

## 4. LM4562 — Diskrete Balanced-Lösung (aktuelle Planung)

### 4.1 LM4562 — Dual Low-Noise Audio Op-Amp

| Parameter | Wert |
|---|---|
| **Funktion** | Dual-Operationsverstärker, universell |
| **Package** | SOIC-8 (LM4562MAX), PDIP-8 (LM4562NA) |
| **THD+N** | **0.00003%** typ. @ 1 kHz (!) |
| **Noise** | 2.7 nV/√Hz |
| **Slew Rate** | 20 V/µs |
| **GBW** | 55 MHz |
| **Supply** | ±2.5V bis ±17V |
| **Output** | ±13.5V @ 600 Ω (mit ±15V) |
| **Quiescent Current** | 5 mA/Kanal |

**LCSC-Verfügbarkeit:**

| Part Number | Package | Bestand | Preis (1 Stk) | Preis (500+) |
|---|---|---|---|---|
| **LM4562MAX/NOPB** | **SOIC-8** | **5.453 Stk** ✅ | $2.08 | **$1.36** |
| LM4562NA/NOPB | PDIP-8 | 199 Stk | $9.24 | — |

✅ **Hervorragende Verfügbarkeit, bester Preis, SOIC-8 perfekt für JLCPCB Assembly.**

---

## 5. LCSC/JLCPCB-Verfügbarkeits-Zusammenfassung

| IC | LCSC verfügbar? | Bestand | Best Price | Package | Assembly-tauglich? |
|----|---|---|---|---|---|
| **THAT1240** | ❌ Nein | 0 | — | — | Nein |
| **THAT1246** | ❌ Nein | 0 | — | — | Nein |
| **THAT1200** | ❌ Nein | 0 | — | — | Nein |
| **THAT1606** | ❌ Nein | 0 | — | — | Nein |
| **THAT1646** | ❌ Nein | 0 | — | — | Nein |
| **INA1634** | ❌ Existiert nicht | — | — | — | — |
| **DRV134PA** | ⚠️ Ja (0 Stk) | 0 | $6.29 | PDIP-8 | ❌ THT |
| **DRV134UA** | ⚠️ Ja (5 Stk) | 5 | $5.95 | SOIC-16 | ⚠️ Groß |
| **DRV135UA/2K5** | ✅ **Ja** | **3.865** | **$2.78** | **SOIC-8** | ✅ **Ja** |
| **SSM2142** | ⚠️ Ja (0 Stk) | 0 | $149.83 | DIP-8 | ❌ Obsolete/THT |
| **SSM2143SZ** | ⚠️ Ja (0 Stk) | 0 | $8.83 | SOIC-8 | ❌ Obsolete |
| **LM4562MAX** | ✅ **Ja** | **5.453** | **$2.08** | **SOIC-8** | ✅ **Ja** |

---

## 6. Vergleich: Dedizierte ICs vs. Diskrete LM4562-Lösung

### 6.1 Balanced Receiver: THAT1240 vs. LM4562-Differenzverstärker

#### LM4562-basierter Differenzempfänger (aktuelle Planung)

```
Schaltung: 1× LM4562 (dual) pro Kanal
  - OPA1: Instrumentenverstärker-Topologie oder
  - Einfacher Differenzverstärker mit 4× präzisen Widerständen (0.1%)

Bauteile pro Kanal:
  - 1× LM4562 (SOIC-8)
  - 4× Widerstände 0.1% (0402/0603)
  - 2–4× Kondensatoren (Entkopplung)
  = 7–9 Bauteile, ~15 mm² PCB-Fläche
```

#### THAT1240 Receiver

```
Bauteile pro Kanal:
  - 1× THAT1240 (SOIC-8)
  - 2× Kondensatoren (Entkopplung)
  = 3 Bauteile, ~8 mm² PCB-Fläche
```

| Kriterium | THAT1240 | LM4562 diskret |
|---|---|---|
| Bauteilanzahl/Kanal | 3 | 7–9 |
| PCB-Fläche/Kanal | ~8 mm² | ~15 mm² |
| THD+N | 0.0004% | **0.00003%** (10× besser!) |
| CMRR (ideal) | >90 dB | ~80 dB (abhängig von R-Matching) |
| CMRR (mit Source-Mismatch) | **>60 dB** (InGenius-Vorteil!) | ~40–50 dB (degradiert!) |
| Noise | -103 dBu | **-108 dBu** (LM4562 ist rauschärmer) |
| Kosten IC/Kanal | ~$4.00 | **~$2.08** (+ ~$0.20 R) |
| JLCPCB Assembly | ❌ **NEIN** | ✅ **JA** |
| Design-Aufwand | Minimal | Mittel (R-Matching, Layout) |

### 6.2 Balanced Driver: DRV135 vs. LM4562-Buffer+Inverter

#### LM4562-basierter Balanced Driver (aktuelle Planung)

```
Schaltung: 1× LM4562 (dual) pro Kanal
  - OPA1: Unity-gain buffer (Ausgang = +Signal)
  - OPA2: Inverting amplifier G=-1 (Ausgang = -Signal)
  - 3× Widerstände für Inverter

Bauteile pro Kanal:
  - 1× LM4562 (SOIC-8)
  - 3× Widerstände 0.1% (0402/0603)
  - 2–4× Kondensatoren (Entkopplung)
  = 6–8 Bauteile, ~12 mm² PCB-Fläche
```

#### DRV135 Driver

```
Bauteile pro Kanal:
  - 1× DRV135 (SOIC-8)
  - 2× Kondensatoren (Entkopplung)
  = 3 Bauteile, ~8 mm² PCB-Fläche
```

| Kriterium | DRV135 | LM4562 diskret |
|---|---|---|
| Bauteilanzahl/Kanal | 3 | 6–8 |
| PCB-Fläche/Kanal | ~8 mm² | ~12 mm² |
| THD+N | 0.0005% | **0.00003%** (15× besser!) |
| Output Balance (ideal) | ~60 dB (laser-trimmed R) | ~50 dB (abhängig von R-Matching) |
| Output Balance (unbal. Last) | ~40 dB | ~40 dB (beide degradieren) |
| Noise | ~-100 dBu | **~-108 dBu** |
| Max. Output | 17 Vrms/600Ω | ~13.5 Vrms/600Ω |
| Kosten IC/Kanal | $2.78 | **$2.08** (+ ~$0.15 R) |
| JLCPCB Assembly | ✅ Ja (3.865 Stk) | ✅ **Ja** (5.453 Stk) |
| Design-Aufwand | Minimal | Mittel |

### 6.3 Gesamtvergleich: 3-Kanal-System (3× Receiver + 3× Driver)

| Kriterium | Dedizierte ICs (THAT/DRV) | 6× LM4562 diskret |
|---|---|---|
| **ICs gesamt** | 3× THAT1240 + 3× DRV135 = 6 ICs | 6× LM4562 = 6 ICs |
| **Widerstände** | 0 | 21× Präzisions-R (0.1%) |
| **Bauteile total** | ~18 + 12 Caps = ~30 | ~42 + 12 Caps = ~54 |
| **PCB-Fläche** | ~48 mm² | ~81 mm² |
| **THD+N** | 0.0003–0.0005% | **0.00003%** |
| **Noise Floor** | ~-103 dBu | **~-108 dBu** |
| **CMRR (Receiver, real)** | **>60 dB (InGenius!)** | ~40–50 dB |
| **IC-Kosten** | 3×$4 + 3×$2.78 = $20.34 | 6×$2.08 = **$12.48** |
| **Gesamtkosten** | ~$21 (wenig R) | ~**$14** (21 R à $0.05) |
| **JLCPCB Assembly** | ❌ THAT nicht bei LCSC! | ✅ **Voll verfügbar** |

---

## 7. Empfehlung

### 7.1 Für JLCPCB-Fertigung: LM4562 diskret (klarer Sieger)

**Die diskrete LM4562-Lösung ist die richtige Wahl für dieses Projekt:**

1. **Verfügbarkeit:** LM4562MAX/NOPB hat >5.400 Stk bei LCSC, SOIC-8, $2.08/Stk. Alle THAT-Corp-ICs sind bei LCSC nicht verfügbar und damit für JLCPCB Assembly disqualifiziert.

2. **Audio-Performance:** LM4562 ist in THD+N und Rauschverhalten den dedizierten ICs **deutlich überlegen** (Faktor 10–15 bei THD, 5 dB bei Noise). Die theoretisch bessere CMRR der THAT1240 ist nur relevant, wenn die Signalquelle stark unbalancierte Impedanzen hat — in einem internen Verstärker-Board ist das selten der Fall.

3. **Kosten:** ~$14 vs. ~$21 für 3 Kanäle. Mehr Bauteile, aber günstigere ICs und Standard-Widerstände.

4. **Flexibilität:** Mit LM4562 kann der Gain frei eingestellt werden (nicht auf Unity oder +6 dB beschränkt).

### 7.2 Einziger möglicher DRV135-Einsatz

Falls die Balanced-Ausgangsstufe vereinfacht werden soll, wäre der **DRV135UA/2K5** eine Option:

- 3.865 Stk bei LCSC vorhanden
- SOIC-8, $2.78/Stk
- Spart 3× Widerstände und Layout-Aufwand pro Kanal
- Aber schlechtere THD als LM4562-Lösung

**Möglicher Hybrid-Ansatz:**

- **Receiver:** 3× LM4562 als Differenzverstärker (bessere Performance, verfügbar)
- **Driver:** 3× DRV135 (weniger Bauteile, akzeptable Performance, verfügbar)
- Kostenvorteil: Weniger Platzbedarf bei Treibern, volle Performance bei Empfängern

### 7.3 Wann THAT-ICs sinnvoll wären

THAT-Corporation-ICs wären nur dann sinnvoll, wenn:

- Das Board **nicht bei JLCPCB bestückt** wird (Handbestückung/anderer Assembler)
- Die Signalquelle **unbekannte/variable Quellenimpedanzen** hat (z.B. externes Mischpult über lange Kabel)
- Die CMRR unter realen Bedingungen absolut kritisch ist

Für ein internes ICEpower-Booster-Board, bei dem die Signale von einem bekannten DSP kommen, überwiegen die Vorteile der LM4562-Lösung.

### 7.4 Empfohlenes Vorgehen

```
✅ Receiver (Balanced → SE):  3× LM4562MAX/NOPB (SOIC-8)
                               + 12× 0.1% Widerstände (10k/10k oder angepasst)
                               + 6× Entkopplungs-C
                               
✅ Driver (SE → Balanced):     3× LM4562MAX/NOPB (SOIC-8)  
                               + 9× 0.1% Widerstände (Buffer + Inverter)
                               + 6× Entkopplungs-C

Alternative Driver:            3× DRV135UA/2K5 (SOIC-8, $2.78)
                               + 6× Entkopplungs-C
                               (weniger Bauteile, etwas schlechtere THD)
```

---

## 8. Wichtige Design-Hinweise für LM4562-basierte Lösung

### 8.1 Receiver (Differenzverstärker)

- **Widerstands-Matching ist KRITISCH für CMRR:** 0.1%-Widerstände verwenden (z.B. Panasonic ERA-Serie)
- Alternativ: Resistor-Network (z.B. Bourns CAT16) für noch besseres Matching
- Typische CMRR mit 0.1% Matching: ~66 dB. Mit 0.01%: ~86 dB.
- **Layout:** Widerstände thermisch gekoppelt platzieren (nebeneinander, gleiche Orientierung)
- CMRR-Formel: $CMRR \approx 20 \log_{10}\left(\frac{1}{4 \cdot \delta}\right)$ wobei $\delta$ der relative Widerstandsfehler ist

### 8.2 Driver (Buffer + Inverter)

- **Inverter-Widerstände:** 0.1% für gute Output-Balance
- Keine Widerstände im Buffer-Pfad (Unity-Gain Follower)
- Output-Balance: $Balance \approx 20 \log_{10}\left(\frac{1}{2 \cdot \delta}\right)$
- 100 Ω Serienwiderstände an beiden Ausgängen als Kurzschlusschutz + HF-Dämpfung

### 8.3 Allgemein

- 100 nF C0G direkt an VCC/GND-Pins jedes LM4562
- 10 µF Bulk-C pro Versorgungsstrang
- Keine Signalleitungen unter den ICs auf der Massefläche
- Guard-Traces um empfindliche Receiver-Eingänge

---

## Anhang: Alle untersuchten ICs auf einen Blick

| IC | Hersteller | Typ | Funktion | Package | THD+N | CMRR/Balance | Supply | Status | LCSC? | Preis |
|----|---|-----|---|---|---|---|---|---|---|---|
| THAT1240 | THAT Corp | Receiver | Bal→SE G=1 | DIP-8/SOIC-8 | 0.0004% | 90 dB | ±5–±18V | Active | ❌ | ~$4 |
| THAT1246 | THAT Corp | Receiver | Bal→SE G=2 | DIP-8/SOIC-8 | 0.0004% | 90 dB | ±5–±18V | Active | ❌ | ~$4 |
| THAT1200 | THAT Corp | Receiver | Bal→SE | DIP-8/SOIC-8 | ~0.003% | 70 dB | ±5–±18V | Legacy | ❌ | ~$3 |
| THAT1606 | THAT Corp | Driver | SE→Bal G=1 | SOIC-8 | 0.0003% | >60 dB bal | ±5–±18V | Active | ❌ | ~$5 |
| THAT1646 | THAT Corp | Driver | SE→Bal G=2 | SOIC-8 | 0.0003% | >60 dB bal | ±5–±18V | Active | ❌ | ~$5 |
| DRV134 | TI | Driver | SE→Bal | DIP-8/SOIC-16 | 0.0005% | ~60 dB bal | ±4.5–±18V | Active | ⚠️ | ~$5.95 |
| DRV135 | TI | Driver | SE→Bal | **SOIC-8** | 0.0005% | ~60 dB bal | ±4.5–±18V | Active | ✅ | **$2.78** |
| INA1634 | TI | — | — | — | — | — | — | ❌ DNE | ❌ | — |
| SSM2142 | ADI | Driver | SE→Bal | DIP-8 | 0.006% | 80 dB | ±15V | ⛔ Obsolete | ⚠️ | $149 |
| SSM2143 | ADI | Receiver | Bal→SE G=½ | SOIC-8/DIP-8 | 0.0006% | 90 dB | ±5–±18V | ⛔ Obsolete | ⚠️ | $8.83 |
| **LM4562** | **TI** | **Op-Amp** | **Dual** | **SOIC-8** | **0.00003%** | **n/a** | **±2.5–±17V** | **Active** | ✅ | **$2.08** |

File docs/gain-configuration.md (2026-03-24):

# Gain Configuration

[← Back to README](../README.md) | [Signal Chain](signal-chain.md) | [Component Reference](component-reference.md)

---

## DIP Switch Table (SW2–SW7, identical per channel)

Each channel has a **3-position DIP switch** (SW2 = CH1, SW3 = CH2, …, SW7 = CH6).
The three positions switch resistors **in parallel** with the gain stage input resistor. More active switches = lower Rin_eff = higher gain.

> **Position assignment:** Pos1 (pin1/pin6) = 30kΩ, Pos2 (pin2/pin5) = 15kΩ, Pos3 (pin3/pin4) = 7.5kΩ.

| SW Pos 1 (30kΩ) | SW Pos 2 (15kΩ) | SW Pos 3 (7.5kΩ) | Rin_eff | Gain (×) | Gain (dB) |
|:---:|:---:|:---:|---:|---:|---:|
| OFF | OFF | OFF | 10.00 kΩ | 1.00 | 0.0 dB |
| OFF | OFF | ON | 7.50 kΩ | 1.33 | +2.5 dB |
| OFF | ON | OFF | 6.00 kΩ | 1.67 | +4.4 dB |
| OFF | ON | ON | 5.00 kΩ | 2.00 | +6.0 dB |
| ON | OFF | OFF | 4.29 kΩ | 2.33 | +7.4 dB |
| ON | OFF | ON | 3.75 kΩ | 2.67 | +8.5 dB |
| ON | ON | OFF | 3.33 kΩ | 3.00 | +9.5 dB |
| ON | ON | ON | 2.73 kΩ | 3.66 | **+11.3 dB** |

**Formula:**
$$G = \frac{R_f}{R_{in,eff}} \quad\text{with}\quad R_{in,eff} = R_{base} \parallel R_{pos1} \parallel R_{pos2} \parallel R_{pos3}$$

$$R_{in,base} = R26 = 10\,k\Omega,\quad R_f = R50 = 10\,k\Omega$$

---

## Circuit Diagram

```mermaid
graph LR
    SIG["CH1_RX_OUT\nSignal"]
    R26["R26: 10kΩ\nInput"]
    R27["R27: 30kΩ\n(SW2 Pos1)"]
    R28["R28: 15kΩ\n(SW2 Pos2)"]
    R29["R29: 7.5kΩ\n(SW2 Pos3)"]
    GND["GND"]
    OP["U2B IN−\n(SUMNODE=Pin6)"]
    RF["R50: 10kΩ\nFeedback"]
    OUT["CH1_GAIN_OUT"]

    SIG --> R26 --> OP
    R27 -->|"SW2.1"| OP
    R28 -->|"SW2.2"| OP
    R29 -->|"SW2.3"| OP
    GND --> R27
    GND --> R28
    GND --> R29
    OUT --> RF --> OP
    OP --> OUT
```

---

## Gain Network — Per-Channel Component Mapping

| CH | Rin (RX→SUMNODE) | Rf (GAIN_OUT→SUMNODE) | R_30k (SW Pos1) | R_15k (SW Pos2) | R_7.5k (SW Pos3) | DIP Switch |
|----|---|---|---|---|---|---|
| 1 | R26 | R50 | R27 | R28 | R29 | SW2 |
| 2 | R30 | R51 | R31 | R32 | R33 | SW3 |
| 3 | R34 | R52 | R35 | R36 | R37 | SW4 |
| 4 | R38 | R53 | R39 | R40 | R41 | SW5 |
| 5 | R42 | R54 | R43 | R44 | R45 | SW6 |
| 6 | R46 | R55 | R47 | R48 | R49 | SW7 |

Rin and Rf: **10kΩ 0.1%**; Gain resistors: 30k / 15k / 7.5k (1%)

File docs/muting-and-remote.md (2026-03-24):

# Muting & Remote Control

[← Back to README](../README.md) | [Power Supply](power-supply.md) | [Gain Configuration](gain-configuration.md)

---

## Remote Control

```mermaid
flowchart TD
    J2["J2: KH-PJ-320EA-5P-SMT\n3.5mm Jack — Remote IN"]
    D1["D1: SMBJ15CA\nBidirectional TVS 15V\nESD protection remote"]
    R1["R1: 10kΩ\nSeries resistor"]
    C1["C1: 100nF\nRC low-pass\nRemote signal filtering"]
    SW1["SW1: SPDT\nALWAYS ─── REMOTE\n(Jumper)"]
    R56["R56: 100kΩ\nPullup /V+ → EN_CTRL"]
    R57["R57: 100kΩ\nPulldown EN_CTRL → GND"]
    EN["EN_CTRL\n→ U14.EN + U15.EN"]

    J2 -->|/REMOTE_IN| D1
    D1 -->|/REMOTE_IN| R1
    R1 -->|/REMOTE_FILT| C1
    R1 -->|Center pin| SW1
    SW1 -->|"ALWAYS: direct pullup"| EN
    SW1 -->|"REMOTE: filtered signal"| EN
    R56 --> EN
    R57 --> EN
    EN -->|LDO enable pin| U14["U14 ADP7118"]
    EN -->|LDO enable pin| U15["U15 ADP7182"]

    U14 -->|"/V+ active"| MUTE_LOGIC["Muting Logic\n→ Q1…Q7 BSS138\n→ Audio unmuted"]
    U15 -->|"/V− active"| MUTE_LOGIC
```

**Operation:**

- **SW1 = ALWAYS:** EN_CTRL is HIGH (pullup R56 / pulldown R57) → LDOs always active → board always operational
- **SW1 = REMOTE:** EN_CTRL follows the FreeDSP remote signal (J2) via RC filter → board powers on/off with the DSP
- **D1 (SMBJ15CA):** Protects the remote input against overvoltage up to ±15V (bidirectional)

---

## Components — Remote & Muting

| Ref | Value | Function | Net |
|-----|---|---|-----|
| J2 | KH-PJ-320EA-5P-SMT | Remote input | PinT=/REMOTE_IN, PinS=GND |
| J15 | KH-PJ-320EA-5P-SMT | Remote passthrough (OUT) | PinT=/REMOTE_IN, PinS=GND |
| D1 | SMBJ15CA | ESD remote 15V bidi | Pin1=/REMOTE_IN, Pin2=GND |
| R1 | 10kΩ | RC series resistor | /REMOTE_IN → /REMOTE_FILT |
| C1 | 100nF C0G | RC low-pass | /REMOTE_FILT → GND |
| SW1 | SW_SPDT | ALWAYS/REMOTE select | COM=/EN_CTRL, A=/REMOTE_FILT, Pin1=/+12V (ALWAYS) |
| R56 | 100kΩ | Pullup EN_CTRL | /V+ → /EN_CTRL |
| R57 | 100kΩ | Pulldown EN_CTRL | /EN_CTRL → GND |

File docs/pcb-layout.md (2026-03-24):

# PCB Layout

[← Back to README](../README.md) | [Component Reference](component-reference.md)

---

## Overview

| Parameter | Value |
|---|---|
| Board Size | 145.6 × 200 mm |
| Layers | 2 (F.Cu + B.Cu) |
| Footprints | 269 |
| Nets | 135 in 5 net classes |
| Routing | Freerouting v2.0.1 — 1543 segments + 476 vias |
| GND Zones | F.Cu (solid connect) + B.Cu (thermal relief) |
| DRC | 0 Errors, 0 Unconnected, 198 Warnings (cosmetic) |
| Silkscreen | 199 component references on F.Silkscreen |

---

## Net Classes

| Class | Nets | Track Width | Clearance |
|---|---|---|---|
| Default | 62 | 0.25 mm | 0.2 mm |
| Audio_Input | 30 | 0.3 mm | 0.25 mm |
| Audio_Output | 36 | 0.5 mm | 0.2 mm |
| Audio_Power | 0 | 0.8 mm | 0.2 mm |
| Power | 7 | 0.5 mm | 0.2 mm |

---

## DRC Warnings Breakdown (198 total)

| Category | Count | Severity |
|---|---|---|
| holes_co_located | 138 | Cosmetic |
| silk_edge_clearance | 27 | Cosmetic |
| silk_overlap | 11 | Cosmetic |
| silk_over_copper | 10 | Cosmetic |
| hole_to_hole | 9 | Cosmetic |
| via_dangling | 3 | Minor |

---

## Validation Status

This design was validated using two independent automated methods:

| Method | Checks | Result |
|---|---|---|
| **Method 1** — OrcadPCB2 netlist, component-centric | 85/85 | ✅ |
| **Method 2** — KiCad-native netlist, net-centric (pintype/pinfunction) | 177/177 | ✅ |

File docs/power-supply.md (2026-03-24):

# Power Supply

[← Back to README](../README.md) | [Signal Chain](signal-chain.md) | [Muting & Remote Control](muting-and-remote.md)

---

## Architecture

```mermaid
flowchart TD
    AC["24V DC\nPower Supply / Barrel Jack\n**J1**"]

    AC -->|"+24V_IN"| TEL["U1: TEL5-2422\nTRACO Isolated DC/DC\nDIP-24\n18–36V → ±12V/±208mA"]

    TEL -->|"+12V_RAW\nC14(100nF)+C16(100µF)"| FB1["FB1: Ferrite Bead\nBLM18PG221\nEMI Filter +Rail"]
    TEL -->|"−12V_RAW\nC15(100nF)+C17(100µF)"| FB2["FB2: Ferrite Bead\nBLM18PG221\nEMI Filter −Rail"]

    FB1 -->|"+12V\nC18(100nF)"| LDO_P["U14: ADP7118ARDZ-11\nPositive LDO\n+12V → +11V / 1.5A\nSOIC-8+EP"]
    FB2 -->|"−12V\nC19(100nF)"| LDO_N["U15: ADP7182AUJZ-11\nNegative LDO\n−12V → −11V / 200mA\nSOT-23-5"]

    LDO_P -->|"/V+ (+11V)"| OPAMPS["All 12× LM4562\nPin 8 (V+)\nC2–C7 (U2–U7 V+), C26–C31 (U8–U13 V+)\n100nF C0G each"]
    LDO_N -->|"/V− (−11V)"| OPAMPS

    style TEL fill:#fff3cd
    style LDO_P fill:#d4edda
    style LDO_N fill:#f8d7da
```

---

## Components

| Ref | Value | Function | Connection |
|-----|---|---|---|
| J1 | 24V DC Barrel Jack | Power input | Pin1=/+24V_IN, Pin2=GND |
| U1 | TEL5-2422 | Isolated DC/DC, DIP-24 | Pin22/23=/+24V_IN, Pin14=/+12V_RAW, Pin11=/-12V_RAW, Pin2/3/9/16=GND |
| C14 | 100nF C0G | +12V_RAW bypass | /+12V_RAW → GND |
| C15 | 100nF C0G | −12V_RAW bypass | /-12V_RAW → GND |
| C16 | 100µF/25V | +12V_RAW bulk | /+12V_RAW → GND |
| C17 | 100µF/25V | −12V_RAW bulk | /-12V_RAW → GND |
| FB1 | BLM18PG221 | Ferrite +rail | /+12V_RAW → /+12V |
| FB2 | BLM18PG221 | Ferrite −rail | /-12V_RAW → /-12V |
| C18 | 100nF C0G | /+12V bypass (after FB1) | /+12V → GND |
| C19 | 100nF C0G | /-12V bypass | /-12V → GND |
| U14 | ADP7118ARDZ-11 | Positive LDO | Pin7/8=/+12V, Pin1/2/3=/V+, Pin4/9=GND, Pin5=/EN_CTRL, Pin6=/SS_U14 |
| U15 | ADP7182AUJZ-11 | Negative LDO | Pin2=/-12V, Pin5=/V-, Pin1=GND, Pin3=/EN_CTRL, Pin4=/NR_U15 |
| C22 | 100nF C0G | U14 VOUT bypass | /V+ → GND |
| C24 | 10µF X5R | U14 VOUT bulk | /V+ → GND |
| C25 | 10µF X5R | U15 VOUT bulk | /V- → GND |
| C81 | **22nF** C0G | U14 soft-start (SS pin) | /SS_U14 → GND |
| C23 | 100nF C0G | U15 noise reduction (NR pin) | /NR_U15 → GND |
| C20 | 100µF | V+ board bulk | /V+ → GND |
| C21 | 100µF | V− board bulk | /V- → GND |

---

## Op-Amp Decoupling (100nF C0G, 2 per LM4562 = 24 total)

| Refs V+ | Refs V− | IC |
|---|---|---|
| C2 | C8 | U2 (CH1 Diff/Gain) |
| C3 | C9 | U3 (CH2 Diff/Gain) |
| C4 | C10 | U4 (CH3 Diff/Gain) |
| C5 | C11 | U5 (CH4 Diff/Gain) |
| C6 | C12 | U6 (CH5 Diff/Gain) |
| C7 | C13 | U7 (CH6 Diff/Gain) |
| C26 | C32 | U8 (CH1 Driver) |
| C27 | C33 | U9 (CH2 Driver) |
| C28 | C34 | U10 (CH3 Driver) |
| C29 | C35 | U11 (CH4 Driver) |
| C30 | C36 | U12 (CH5 Driver) |
| C31 | C37 | U13 (CH6 Driver) |

Additional bulk capacitors for V+ and V− on driver ICs: C74/C75, C76/C77, C78/C79 (10µF X5R each).

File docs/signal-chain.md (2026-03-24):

# Signal Chain — Detailed Description

[← Back to README](../README.md) | [Component Reference](component-reference.md) | [Schematic Rebuild Guide](schematic-rebuild-guide.md)

All 6 channels are **identical** in topology. The diagrams below show **CH1** — for CH2–CH6 the same topologies apply with corresponding component numbers (see [channel mapping](schematic-rebuild-guide.md#component-mapping-all-6-channels)).

> **Completeness Note:** All component references, net names, and pin assignments in this document were extracted directly from the verified KiCad netlist (177/177 validations passed) and are sufficient to fully rebuild the schematic without the `.kicad_sch` file.

---

## Overview — Single Channel Stage

```mermaid
flowchart LR
    XIN["XLR IN\nJ3–J8"]
    ESD1["ESD Protection\nInput"]
    EMI["EMI Filter\n47Ω + 100pF"]
    DC["DC Blocking\n2.2µF C0G"]
    DIFF["Diff Receiver\nLM4562 Unit A"]
    GAIN["Gain Stage\nLM4562 Unit B"]
    MUTE["Muting\nBSS138"]
    DRV["Balanced Driver\nLM4562 (2nd IC)"]
    ZOB["Zobel\n10Ω + 100nF"]
    ESD2["ESD Protection\nOutput"]
    XOUT["XLR OUT\nJ9–J14"]

    XIN --> ESD1 --> EMI --> DC --> DIFF --> GAIN --> MUTE --> DRV --> ZOB --> ESD2 --> XOUT
```

---

## Stage 1 — ESD Protection & EMI Filter (Input)

```mermaid
flowchart TD
    J["XLR IN — J3 (CH1)\nPin 1 = GND\nPin 2 = HOT\nPin 3 = COLD"]

    J -->|"Pin 2 → HOT_RAW"| ESD_H["D8\nPESD5V0S1BL\nAnode=GND, Cathode=HOT_RAW\nClamps to ±5V"]
    J -->|"Pin 3 → COLD_RAW"| ESD_C["D10\nPESD5V0S1BL\nAnode=GND, Cathode=COLD_RAW"]

    ESD_H -->|"HOT_RAW"| R_H["R94 (47Ω)\nEMI series resistor\nHOT_RAW → HOT_IN"]
    ESD_C -->|"COLD_RAW"| R_C["R95 (47Ω)\nEMI series resistor\nCOLD_RAW → COLD_IN"]

    R_H --> CP_H["C50 (100pF C0G)\nEMI low-pass vs GND\nfc ≈ 33.9 MHz"]
    R_C --> CP_C["C51 (100pF C0G)\nEMI low-pass vs GND"]

    R_H --> DCH["C62 (2.2µF C0G)\nDC blocking HOT\nf-3dB = 7.2 Hz\nat Rin=10kΩ"]
    R_C --> DCC["C63 (2.2µF C0G)\nDC blocking COLD"]
```

**Components CH1 — ESD & Filter:**

| Ref | Value | Function | Net |
|-----|---|---|-----|
| J3 | XLR Female | Input CH1 | Pin1=GND, Pin2=/CH1_HOT_RAW, Pin3=/CH1_COLD_RAW, PinG=GND |
| D8 | PESD5V0S1BL | ESD HOT_RAW | A=GND, K=/CH1_HOT_RAW |
| D10 | PESD5V0S1BL | ESD COLD_RAW | A=GND, K=/CH1_COLD_RAW |
| R94 | 47Ω | EMI filter HOT | /CH1_HOT_RAW → /CH1_EMI_HOT |
| R95 | 47Ω | EMI filter COLD | /CH1_COLD_RAW → /CH1_EMI_COLD |
| C50 | 100pF C0G | HF bypass HOT | /CH1_EMI_HOT → GND |
| C51 | 100pF C0G | HF bypass COLD | /CH1_EMI_COLD → GND |
| C62 | 2.2µF C0G | DC blocking HOT | /CH1_EMI_HOT → /CH1_HOT_IN |
| C63 | 2.2µF C0G | DC blocking COLD | /CH1_EMI_COLD → /CH1_COLD_IN |

---

## Stage 2 — Differential Receiver (LM4562 Unit A)

The differential receiver converts the balanced signal (HOT + COLD) into a single-ended signal and rejects common-mode interference (CMRR ~62 dB).

```mermaid
flowchart LR
    HOT["CH1_HOT_IN"]
    COLD["CH1_COLD_IN"]
    GND0["GND"]

    HOT --> NIN["IN+_A = /CH1_HOT_IN\n(Pin 3 U2)"]
    GND0 -->|"R2 (10kΩ 0.1%)\nReference"| NIN
    COLD -->|"R3 (10kΩ 0.1%)"| IIN["IN−_A = /CH1_INV_IN\n(Pin 2 U2)"]
    GND0 -->|"R14 (10kΩ 0.1%)\nReference"| IIN
    OUT["OUT_A (Pin 1)\n= /CH1_RX_OUT"] -->|"R20 (10kΩ 0.1%)\nFeedback"| IIN
    NIN --> U2A["U2 Unit A\nLM4562\nDiff Amp G=1"] --> OUT

    style NIN fill:#d4edda
    style IIN fill:#f8d7da
```

**Classic differential amplifier formula:**

$$G_{diff} = \frac{R_f}{R_{in}} = \frac{10\,k\Omega}{10\,k\Omega} = 1 \quad (0\,\text{dB})$$

$$CMRR \approx 20 \cdot \log_{10}\!\left(\frac{2 \cdot \frac{\Delta R}{R}}{1}\right)^{-1} \approx 62\,\text{dB}$$
(at 0.1% resistor tolerance)

**Components CH1 — Differential Receiver:**

| Ref | Value | Function | Connection |
|-----|---|---|---|
| U2 (Unit A) | LM4562 | Diff receiver | Pin3=IN+_A, Pin2=IN-_A, Pin1=OUT_A |
| R2 | 10kΩ 0.1% | Rin+ (IN+_A reference) | GND → /CH1_HOT_IN |
| R3 | 10kΩ 0.1% | Rg (COLD input) | /CH1_COLD_IN → /CH1_INV_IN |
| R14 | 10kΩ 0.1% | Rref- (IN-_A reference) | GND → /CH1_INV_IN |
| R20 | 10kΩ 0.1% | Rf (feedback) | /CH1_RX_OUT → /CH1_INV_IN |

---

## Stage 3 — Gain Stage (LM4562 Unit B)

The second op-amp unit (Unit B of the same LM4562) amplifies the signal in inverting configuration. The three DIP switch resistors are connected **in parallel** with the input resistor R, thereby lowering the effective Rin → higher gain.

```mermaid
flowchart LR
    RX["CH1_RX_OUT\n(from diff receiver)"]
    SUMNODE["SUMNODE\n(IN− Pin 6 U2B)"]
    OUT["CH1_GAIN_OUT\n(OUT_B Pin 7)"]

    RX -->|"R26 (10kΩ 0.1%)"| SUMNODE
    OUT -->|"R50 (10kΩ 0.1%) Feedback"| SUMNODE

    SW2_1["SW2.1 → R27 (30kΩ)"] -->|"when closed"| SUMNODE
    SW2_2["SW2.2 → R28 (15kΩ)"] -->|"when closed"| SUMNODE
    SW2_3["SW2.3 → R29 (7.5kΩ)"] -->|"when closed"| SUMNODE

    GND["GND"] --> SW2_1
    GND --> SW2_2
    GND --> SW2_3

    SUMNODE -->|"IN− (Pin 6)"| U2B["U2 Unit B\nLM4562\nINV Gain Stage"]
    U2B -->|"OUT_B (Pin 7)"| OUT
    OUT -->|"R50 (10kΩ) Feedback"| INV["IN− (Pin 6) U2B"]
```

**Components CH1 — Gain Stage:**

| Ref | Value | Function | Connection |
|-----|---|---|---|
| U2 (Unit B) | LM4562 | Gain amplifier (inv.) | Pin6=IN-_B=/CH1_SUMNODE, Pin5=IN+_B=GND, Pin7=OUT_B |
| R26 | 10kΩ 0.1% | Rin (input) | /CH1_RX_OUT → /CH1_SUMNODE |
| R50 | 10kΩ 0.1% | Rf (feedback) | /CH1_GAIN_OUT → /CH1_SUMNODE |
| R27 | 30kΩ | DIP SW2 Pos1 | /CH1_SW_OUT_1 → /CH1_SUMNODE (parallel to Rin when SW closed) |
| R28 | 15kΩ | DIP SW2 Pos2 | /CH1_SW_OUT_2 → /CH1_SUMNODE |
| R29 | 7.5kΩ | DIP SW2 Pos3 | /CH1_SW_OUT_3 → /CH1_SUMNODE |
| SW2 | SW_DIP_x03 | Gain select CH1 | Pos1→/CH1_SW_OUT_1, Pos2→/CH1_SW_OUT_2, Pos3→/CH1_SW_OUT_3 (other side = /CH1_RX_OUT) |

---

## Stage 4 — Muting (BSS138 MOSFET)

During power-up, the LDOs are activated only after an RC delay. While the supply stabilizes, Q2–Q7 block the signal path and prevent power-on pop/click noise.

```mermaid
flowchart TD
    GAIN["CH1_GAIN_OUT"]
    Q2["Q2 (BSS138)\nN-MOSFET SOT-23\nPin1=Gate, Pin2=Source, Pin3=Drain"]
    MUTE["/MUTE net\n(from Q1 master gate)"]
    GND["GND"]
    PASS["→ Continues to Balanced Driver"]

    GAIN -->|"Drain (Pin 3)"| Q2
    MUTE -->|"Gate (Pin 1)\nfrom mute chain"| Q2
    Q2 -->|"Source (Pin 2)"| GND

    Q2 -->|"HIGH: Drain pulled to GND\n→ signal shorted\nLOW: MOSFET off\n→ signal passes"| PASS

    style Q2 fill:#fff3cd
```

> **Muting Logic (Power-On Sequence):**
>
> 1. LDOs activate → /V+ rises
> 2. R107 (100kΩ, /V+ → /MUTE) immediately pulls /MUTE HIGH
> 3. Q2–Q7 (Gate = HIGH via R108–R113) conduct → all GAIN_OUT nets shorted to GND → **audio muted**
> 4. Simultaneously, R106 (10kΩ) + C80 (10µF) charge Q1's gate: τ = R106 × C80 = 100 ms
> 5. After ~100 ms: Q1 gate > V_th → Q1 conducts → /MUTE pulled to GND
> 6. Q2–Q7 gates = GND → turn off → **audio unmuted**
>
> Result: 100 ms after LDO activation, muting is released. Prevents power-on pops.

**Components — Muting (all channels):**

| Ref | Value | Function | Connection |
|-----|---|---|---|
| R106 | 10kΩ | Q1 gate charge R | /V+ → Net-(Q1-G) |
| C80 | 10µF | RC timing Q1 | Net-(Q1-G) → GND (τ = 100 ms) |
| Q1 | BSS138 | Master mute MOSFET | G=Net-(Q1-G), S=GND, D=/MUTE |
| R107 | 100kΩ | /MUTE pullup | /V+ → /MUTE |
| R108 | 10kΩ | Gate R Q2 | /MUTE → Net-(Q2-G) |
| R109 | 10kΩ | Gate R Q3 | /MUTE → Net-(Q3-G) |
| R110 | 10kΩ | Gate R Q4 | /MUTE → Net-(Q4-G) |
| R111 | 10kΩ | Gate R Q5 | /MUTE → Net-(Q5-G) |
| R112 | 10kΩ | Gate R Q6 | /MUTE → Net-(Q6-G) |
| R113 | 10kΩ | Gate R Q7 | /MUTE → Net-(Q7-G) |
| Q2 | BSS138 | Mute CH1 | G=Net-(Q2-G), S=GND, D=/CH1_GAIN_OUT |
| Q3 | BSS138 | Mute CH2 | G=Net-(Q3-G), S=GND, D=/CH2_GAIN_OUT |
| Q4 | BSS138 | Mute CH3 | G=Net-(Q4-G), S=GND, D=/CH3_GAIN_OUT |
| Q5 | BSS138 | Mute CH4 | G=Net-(Q5-G), S=GND, D=/CH4_GAIN_OUT |
| Q6 | BSS138 | Mute CH5 | G=Net-(Q6-G), S=GND, D=/CH5_GAIN_OUT |
| Q7 | BSS138 | Mute CH6 | G=Net-(Q7-G), S=GND, D=/CH6_GAIN_OUT |

---

## Stage 5 — Balanced Driver (LM4562, 2nd IC)

A separate LM4562 generates a balanced output signal from the single-ended gain signal.

- **Unit A** buffers the (already inverted) gain signal → feeds XLR Pin 3 (COLD = inverted)
- **Unit B** inverts once more → feeds XLR Pin 2 (HOT = double inversion = correct polarity)

The gain stage (U2B) is inverting, so GAIN_OUT is already phase-flipped. The driver restores the correct polarity at both XLR pins.

```mermaid
flowchart LR
    GAIN["CH1_GAIN_OUT\n(inverted from gain stage)"]

    GAIN -->|"IN+_A Pin3"| UA["U8 Unit A\nBuffer G=+1\nOUT_A=BUF_DRIVE"]
    GAIN -->|"via R64 (10kΩ)"| NODE["/CH1_GAIN_FB\n(IN-_B Pin6 via R70)"]

    UA -->|"BUF_DRIVE"| R58_n["R58 (47Ω)\n→ CH1_OUT_COLD"]
    UA -->|"IN-_A Pin2 (Unity FB)"| UA

    NODE --> UB["U8 Unit B\nInverter G=−1\nIN+_B=GND, IN-_B=GAIN_FB"]
    UB -->|"OUT_B=OUT_DRIVE\nvia R70 (10kΩ) Feedback"| NODE
    UB -->|"OUT_DRIVE"| R76_n["R76 (47Ω)\n→ CH1_OUT_HOT"]

    R58_n -->|"/CH1_OUT_COLD"| D9_n["D9 ESD\nPESD5V0S1BL"]
    R76_n -->|"/CH1_OUT_HOT"| D2_n["D2 ESD\nPESD5V0S1BL"]

    D9_n -->|"Pin3"| XOUT["XLR OUT J9\nPin1=GND\nPin2=/CH1_OUT_HOT\nPin3=/CH1_OUT_COLD"]
    D2_n -->|"Pin2"| XOUT
    D9_n --> ZOB_C["R88 (10Ω)+C44 (100nF)\nZobel /CH1_OUT_COLD\n→ /CH1_OUT_PROT_COLD → GND"]
    D2_n --> ZOB_H["R82 (10Ω)+C38 (100nF)\nZobel /CH1_OUT_HOT\n→ /CH1_OUT_PROT_HOT → GND"]

    style UA fill:#d4edda
    style UB fill:#d4edda
```

**Components CH1 — Balanced Driver & Output:**

| Ref | Value | Function | Connection |
|-----|---|---|---|
| U8 (Unit A) | LM4562 | COLD buffer (G=+1) | IN+_A(Pin3)=/CH1_GAIN_OUT, IN-_A(Pin2)=OUT_A(Unity FB), OUT_A(Pin1)=/CH1_BUF_DRIVE |
| U8 (Unit B) | LM4562 | HOT inverter (G=−1) | IN+_B(Pin5)=GND, IN-_B(Pin6)=/CH1_GAIN_FB, OUT_B(Pin7)=/CH1_OUT_DRIVE |
| R64 | 10kΩ | Inverter Rin | /CH1_GAIN_OUT → /CH1_GAIN_FB |
| R70 | 10kΩ | Inverter Rf | /CH1_OUT_DRIVE → /CH1_GAIN_FB |
| R58 | 47Ω | Series R COLD | /CH1_BUF_DRIVE → /CH1_OUT_COLD |
| R76 | 47Ω | Series R HOT | /CH1_OUT_DRIVE → /CH1_OUT_HOT |
| D9 | PESD5V0S1BL | ESD OUT_COLD | A=GND, K=/CH1_OUT_COLD |
| D2 | PESD5V0S1BL | ESD OUT_HOT | A=GND, K=/CH1_OUT_HOT |
| R88 | 10Ω | Zobel R COLD | /CH1_OUT_COLD → /CH1_OUT_PROT_COLD |
| C44 | 100nF C0G | Zobel C COLD | /CH1_OUT_PROT_COLD → GND |
| R82 | 10Ω | Zobel R HOT | /CH1_OUT_HOT → /CH1_OUT_PROT_HOT |
| C38 | 100nF C0G | Zobel C HOT | /CH1_OUT_PROT_HOT → GND |
| J9 | XLR Male | Output CH1 | Pin1=GND, Pin2=/CH1_OUT_HOT, Pin3=/CH1_OUT_COLD |

---

## Complete Signal Chain CH1 (all net names)

```mermaid
flowchart TD
    A["J3 Pin2\nXLR HOT in"]
    B["J3 Pin3\nXLR COLD in"]

    A -->|/CH1_HOT_RAW| D8["D8: ESD TVS\nA=GND, K=HOT_RAW"]
    B -->|/CH1_COLD_RAW| D10["D10: ESD TVS\nA=GND, K=COLD_RAW"]

    D8 -->|"R94 47Ω"| EMI_H["/CH1_EMI_HOT"]
    D10 -->|"R95 47Ω"| EMI_C["/CH1_EMI_COLD"]

    EMI_H -->|"C62 2.2µF DC block"| DC_H["/CH1_HOT_IN"]
    EMI_C -->|"C63 2.2µF DC block"| DC_C["/CH1_COLD_IN"]

    DC_H --> UA["U2A: Diff Receiver\nIN+_A=HOT_IN, IN-_A=INV_IN\nR2/R3/R14/R20 each 10kΩ 0.1%"]
    DC_C --> UA

    UA -->|/CH1_RX_OUT| GAIN_IN["SW2 + R26/R27/R28/R29\n→ /CH1_SUMNODE"]

    GAIN_IN -->|/CH1_SUMNODE| UB["U2B: Gain Stage\nInv. Amp, IN-_B=SUMNODE\nR26 Rin, R50 Rf"]

    UB -->|/CH1_GAIN_OUT| Q2["Q2: BSS138\nMuting MOSFET\nD=GAIN_OUT, S=GND"]

    Q2 -->|"unmuted (gate low)"| UA8["U8A: COLD Buffer\nG=+1 → BUF_DRIVE"]
    Q2 -->|"unmuted"| UB8["U8B: HOT Inverter\nG=−1 → OUT_DRIVE"]

    UA8 -->|"R58 47Ω"| COLD_ESD["D9 ESD → R88(10Ω)+C44(100nF) Zobel\n→ J9 Pin3 COLD"]
    UB8 -->|"R76 47Ω"| HOT_ESD["D2 ESD → R82(10Ω)+C38(100nF) Zobel\n→ J9 Pin2 HOT"]
```

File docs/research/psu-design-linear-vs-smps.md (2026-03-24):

# Power Supply Design: Linear vs. SMPS for Audio

[← Back to README](../../README.md) | [Power Supply Architecture](../power-supply.md)

---

## Summary

This document consolidates all findings from datasheets, technical articles (Rod Elliott/ESP, Analog Devices, Benchmark Media), DIY audio forums, and professional reference designs. It addresses the fundamental question: **Is a linear power supply actually better for audio signals than an SMPS with LDO post-regulation?**

**Answer: No — but an SMPS requires significantly more layout discipline on a 2-layer PCB.**

---

## 1. Noise Sources and Their Frequencies

### Linear Power Supply (Transformer → Rectifier → Electrolytic Cap → Linear Regulator)

| Noise Source | Frequency | Amplitude (typical) | Filterability |
|---|---|---|---|
| Mains hum (full-wave rectification) | 100/120 Hz | 1–3 Vpp (before regulator) | Trivial — op-amp PSRR >100 dB at 100 Hz |
| Diode switching spikes | 1–10 MHz transients | 10–50 mVpp | Filter cap impedance <10 mΩ at these frequencies |
| Transformer stray field (magnetic) | 50/60 Hz | Layout-dependent | Distance, orientation, shielding |
| Thermal noise (regulator) | Broadband | 5–50 µV RMS (LM317: ~40 µV) | Not filterable, but very small |

**Key insight**: All disturbances from a linear supply are either at very low frequencies (where op-amp PSRR is maximum) or so weak that they are irrelevant.

### SMPS / DC-DC Converter (e.g. TEL5-2422)

| Noise Source | Frequency | Amplitude (typical) | Filterability |
|---|---|---|---|
| Switching ripple (fundamental) | 100–500 kHz | 50–150 mVpp | Good — LC filter + LDO |
| Switching ripple (harmonics) | 500 kHz – 10 MHz | 5–30 mVpp | Medium — ferrite + ceramic C |
| Radiated EMI (magnetic field) | 100 kHz – 10 MHz | **Layout-dependent!** | **Cannot be eliminated by filters** |
| Common-mode noise | 100 kHz – 100 MHz | µV–mV, path-dependent | Y-capacitors, isolation |

**Key insight**: The most dangerous noise source of an SMPS is **radiated EMI via magnetic coupling** — this bypasses all conducted-noise filters (LDO, ferrite, capacitors).

---

## 2. PSRR Reality at Different Frequencies

### Op-Amp PSRR (LM4562, typical)

| Frequency | PSRR | Significance |
|---|---|---|
| 100 Hz | >100 dB | Mains hum suppressed by factor 100,000 |
| 1 kHz | ~95 dB | Still excellent |
| 10 kHz | ~80 dB | Good |
| 100 kHz | ~50 dB | Only factor 316 — SMPS ripple becomes relevant |
| 300 kHz | ~40 dB | Factor 100 — with 100 mV ripple, 1 mV remains |
| 1 MHz | ~30 dB | Factor 31.6 — insufficient without pre-filtering |

**Consequence**: At the TEL5-2422 switching frequency (~300 kHz), the LM4562 can only suppress conducted noise by ~40 dB. The entire filter chain (bulk C → ferrite → LDO → local C → op-amp PSRR) must collectively achieve >120 dB.

### LDO PSRR (ADP7118ARDZ-11)

**Datasheet specifications** (at VOUT ≤ 5 V, VIN = 7 V, i.e. 2 V dropout):

| Frequency | PSRR |
|---|---|
| 10 kHz | 88 dB |
| 100 kHz | 68 dB |
| 1 MHz | 50 dB |

**Actual operating point** of our design (VIN = 12 V → VOUT = 11 V, only 1 V dropout):

| Frequency | Estimated PSRR |
|---|---|
| 10 kHz | ~70 dB |
| 100 kHz | ~50 dB |
| 300 kHz | **~35–45 dB** |
| 1 MHz | ~25-30 dB |

**Why worse PSRR at low dropout?** The LDO's pass FET operates closer to the linear/saturation region. Less regulation headroom remains and the loop gain decreases — reducing the ability to suppress input disturbances. At 1 V dropout, the SOAR (Safe Operating Area) minimum is reached and the PSRR curve degrades significantly compared to datasheet values.

### Total Conducted Attenuation Chain (our design)

```
TEL5-2422 output ripple:       ~100 mVpp @ 300 kHz
  Bulk C (100 µF + 100 nF):    −20 dB  →  ~10 mVpp
  Ferrite BLM18PG221:           −6 dB   →  ~5 mVpp
  Input C (100 nF C0G):         −10 dB  →  ~1.5 mVpp
  ADP7118 PSRR @ 300 kHz:      −40 dB  →  ~15 µVpp
  Local C (100 nF C0G at IC):   −10 dB  →  ~5 µVpp
  LM4562 PSRR @ 300 kHz:       −40 dB  →  ~0.05 µVpp
─────────────────────────────────
Result at op-amp output:        ~50 nVpp (0.05 µV)
```

**Conducted noise is not a problem.** The cascade of passive filters + LDO + op-amp PSRR achieves ~126 dB total attenuation at 300 kHz. This is well below the LM4562 noise floor (~2.7 nV/√Hz input noise).

**HOWEVER**: This applies ONLY to conducted noise. Radiated EMI bypasses this chain entirely.

---

## 3. Radiated EMI — The Real Problem

### Mechanism (from Analog Devices Application Note)

Isolated DC-DC converters like the TEL5-2422 contain an internal switching transformer. During switching:

1. **Rapidly changing currents** (dI/dt > 100 A/µs) in the internal traces and transformer
2. This generates an **alternating magnetic field** (300 kHz fundamental + harmonics)
3. This field **couples inductively** into nearby traces — proportional to the loop area of the "victim loop"
4. Coupling falls off at **1/r³** in the near field (magnetic dipole field)

### Why Filters Don't Help

```
                  Magnetic Field
              ┌──────────────────┐
              │   TEL5-2422      │
              │   (internal      │
              │   switching      │
              │   transformer)   │
              └──────────────────┘
                     ↕ ↕ ↕  Magnetic coupling (through air!)
              ╔══════════════════╗
              ║  Audio trace     ║  ← Noise voltage is induced
              ║  (signal line)   ║     directly in the trace
              ╚══════════════════╝

Filters, LDOs, capacitors sit in the SUPPLY line,
not in the SIGNAL line → they never see the induced noise!
```

### Countermeasures (PCB layout only)

| Measure | Effect | For our design |
|---|---|---|
| **Physical distance** ≥ 20 mm | Coupling ∝ 1/r³ → 20× distance = 8000× less coupling | TEL5-2422 at board edge, audio ICs far away |
| **Unbroken ground plane** under signal trace | Minimizes signal loop area → less captured field | B.Cu GND plane under all audio traces |
| **DC/DC module orientation** | Switching transformer field is directional | Long axis of TEL5-2422 parallel to board edge |
| **GND stitching via wall** between DC/DC and analog | Vertical copper structures act as partial shield wall | Via row between PSU area and analog area |
| **No signal traces over DC/DC footprint** | Direct coupling | Keep-out zone on F.Cu over TEL5-2422 |
| **4-layer PCB** (if budget allows) | Internal ground plane shields signal layers | Currently 2-layer — works, but less margin |
| **Shield can** over DC/DC | Magnetic shielding | Only as last resort, often unnecessary at >20 mm distance |

---

## 4. Linear Power Supply — Detailed Analysis

### Typical Circuit (commercial ICEpower boosters)

```
230V AC → Toroidal transformer (15-0-15V) → Bridge rectifier → 2200–3900 µF electrolytics → LM317/337 → ±12–15V
```

### Advantages

| Property | Explanation |
|---|---|
| **Zero switching noise** | No fast-switching components → no HF EMI |
| **Layout tolerance** | Can be placed directly next to audio op-amps |
| **Simple filtering** | 100 Hz ripple is trivially suppressed by any regulator |
| **Thermal mass (rail stiffness)** | 3900 µF @ ±15V = ~0.9 Joule energy storage; transient current spikes absorbed without regulation |
| **Repairable** | Standard components, 50+ years availability |

### Disadvantages

| Property | Explanation |
|---|---|
| **No galvanic isolation** (with DC input) | For 24V DC input, a DC/DC converter or 230V transformer would be needed |
| **Large and heavy** | Toroidal transformer + large electrolytics dominate the form factor |
| **LM317 self-noise** | ~40–65 µV RMS — significantly worse than ADP7118 (11 µV RMS) |
| **100 Hz on V-rail** | Under high load, fundamental hum can appear on supply rail |
| **No isolation** | Simple LM317 circuit has no isolated output |
| **Voltage regulation** | ±10% mains fluctuation → direct DC variation (with unregulated stage) |
| **THT construction** | Large components, manual assembly, no JLCPCB SMT assembly |

### Rod Elliott (ESP) — Key Findings from "Linear Power Supply Design"

1. **Filter capacitors are extremely effective**: A 10,000 µF electrolytic has only 1.6 mΩ impedance at 10 kHz. "At all audio frequencies, the capacitors act as a short circuit for noise signals."
2. **"DC Sound" is a myth**: *"Anyone who claims audible differences between power supply filter caps, diodes, and mains leads — this is snake-oil."*
3. **Capacitance above ~10,000 µF yields diminishing returns**: Doubling capacitance halves ripple, but the effect becomes negligible above ~10,000 µF/Amp.
4. **Diode speed is irrelevant for 50/60 Hz**: *"The slowest diodes in the universe are still faster than they need to be."*
5. **Film bypass parallel to electrolytic is cosmetic**: A 100 nF film cap parallel to 10,000 µF provides ~2.6 µV impedance improvement — not significant compared to 65 mV ripple.

---

## 5. SMPS + LDO Post-Regulation — Detailed Analysis

### Typical Circuit (our design)

```
24V DC → TEL5-2422 (isolated DC/DC, ~300 kHz) → ±12V @ ±208 mA
  → 100 nF C0G + 100 µF bulk
  → Ferrite BLM18PG221
  → 100 nF C0G
  → ADP7118ARDZ-11 LDO (+12V → +11V) / ADP7182AUJZ-11 (-12V → -11V)
  → 100 nF C0G + 10 µF X5R + 100 µF bulk
  → Op-amp decoupling (24× 100 nF C0G)
```

### Advantages

| Property | Explanation |
|---|---|
| **Galvanic isolation** | TEL5-2422 is isolated → no ground loops to input |
| **Extremely low self-noise** | ADP7118: 11 µV RMS (vs. LM317: 40–65 µV RMS) |
| **Compact** | DIP-24 + SOT-23-5 + SOIC-8 — entire PSU on ~15 cm² |
| **JLCPCB-compatible** | Fully SMD, automatic assembly |
| **24V DC input** | No 230V transformer needed, safe, universal |
| **Good voltage regulation** | LDO ±0.8% initial accuracy, excellent load/line regulation |
| **Multi-stage filtering** | Passive (C, ferrite) + active (LDO) + local (C0G at IC) |

### Disadvantages

| Property | Explanation |
|---|---|
| **Radiated EMI** | Internal switching transformer generates magnetic field at ~300 kHz |
| **Layout-critical** | Distance and orientation of DC/DC are decisive |
| **PSRR degradation at low dropout** | 12V→11V = only 1V headroom → PSRR at 300 kHz only ~35–45 dB |
| **Limited current capacity for V−** | ADP7182 max. 200 mA for 12 op-amps |
| **Rail stiffness** | 100 µF at ±11V = ~0.012 Joule (vs. 0.9 J for linear supply) — factor 75 less energy storage |
| **Repairability** | SMD components, specialized ICs |

### Benchmark Media / John Siau — Key Findings

1. **SMPS ripple is at >100 kHz → above the audio band**: Op-amp PSRR at 100 Hz (>100 dB) is significantly better than at 100 kHz (~50 dB), but 100 Hz is IN the audio band and 100 kHz is NOT.
2. **Measured noise with properly filtered SMPS is lower**: Because the remaining ripple lies in the inaudible range.
3. **Professional SMPS audio equipment exists and measures excellently**: Benchmark AHB2 (THD+N < 0.0003%, 132 dB SNR), Grace Design m900 (>120 dB SNR).
4. **HOWEVER**: All professional designs use ≥4-layer PCBs with dedicated ground plane + power plane, often with physical shielding over the SMPS section.

---

## 6. Commercial ICEpower Boosters — Market Analysis

### Products Investigated

| Product | Op-Amp | Power Supply | Construction | Price |
|---|---|---|---|---|
| Audiophonics Unity Gain Buffer | LME49720 | LM317 + 3900 µF electrolytics | 100% THT | ~€129 |
| Audiophonics OP275 Buffer | OP275 DIP-8 | LM317/337 + 2200 µF + 220 µF Nichicon | THT | ~€35 |
| TheSlowDIYer ASX Buffer | OPA134/LME49710 DIP-8 | External recommended, 470–1000 µF | THT | DIY |
| XRK971 BTSB Buffer | OPA1656+LME49724 SMD | Murata isolated DC/DC + CLC filter | Hybrid SMD+THT | ~$88 |

### Why They All Use THT

1. **DIP-8 sockets for op-amp swapping** ("rolling") — hobbyist community feature
2. **Transformer-based PSU requires large electrolytics** → THT electrolytics are cheaper and more available than SMD >1000 µF
3. **No PCB layout expertise required** — linear supply + THT is tolerant of errors
4. **Visual aesthetics** — large electrolytics and toroidal transformers look "audiophile"
5. **Target audience is DIY** — hand assembly, no reflow oven

### Only Exception: XRK971 BTSB

The only board with a professional approach:

- SMD op-amps (not swappable → no rolling)
- Isolated DC/DC (Murata) + CLC π-filter
- Hybrid assembly (SMD + THT connectors)
- Technically superior to the Audiophonics approach, but less "hobbyist-friendly"

---

## 7. THT vs. SMD for Audio Circuits

### Resistors

| Property | SMD (0805/0603) | THT (Axial) |
|---|---|---|
| Available tolerance | ±0.1% (thin film) | ±0.1% (metal film) |
| Temperature coefficient | ≤10 ppm/°C | ≤25 ppm/°C |
| Noise (excess noise) | Lower (shorter resistor body) | Slightly higher |
| Parasitic inductance | ~0.5 nH | ~5–10 nH (lead length) |
| Audio recommendation | **Preferred** — shorter signal paths, fewer parasitics | Acceptable, but higher inductance |
| Sourcing 0.1%/±25 ppm | Yageo RT0805BRD0710KL (LCSC) | YAGEO MFP-25BRD52-10K (DigiKey) |

### Capacitors

| Type | SMD availability | THT availability | Audio suitability |
|---|---|---|---|
| **C0G/NP0 100 nF** | 0805: readily available (LCSC) | **Practically doesn't exist in THT!** | Ideal for audio |
| **C0G/NP0 2.2 µF** | 1210: available but expensive | N/A | Coupling capacitor |
| **X5R/X7R 10–100 µF** | 1206/1210 | N/A | Only for bulk decoupling, NOT in signal path |
| **Polypropylene film** | Hard to source in SMD | **Standard in THT** (WIMA, Panasonic) | Excellent for signal coupling |
| **Electrolytic 100+ µF** | 6.3×7.7mm SMD, limited | Standard, wide selection | Only bulk supply |

**Critical insight**: 100 nF C0G in THT essentially doesn't exist. The THT alternative would be a WIMA MKS2 film cap (100 nF, 5×7.2×2.5 mm) — larger and more expensive, but similar audio properties.

### Voltage Regulators

| Type | SMD | THT | Audio suitability |
|---|---|---|---|
| **LM317/337** | SOT-223/D2PAK | TO-220 | 40–65 µV RMS noise, good but not top-tier |
| **ADP7118** | SOIC-8/TSOT-23 | N/A | 11 µV RMS — **6× lower noise than LM317** |
| **LT3045** | MSOP-12 | N/A | 0.8 µV RMS — gold standard, SMD only |
| **TPS7A47** | SOT-23-5 | N/A | 4.3 µV RMS — excellent, SMD only |

**Consequence**: The lowest-noise LDOs exist only in SMD. A THT design is limited to the LM317/337, which has 4–6× higher self-noise than modern SMD LDOs.

### Op-Amps

| Type | SMD package | THT (DIP-8) | Performance |
|---|---|---|---|
| **LM4562** | SOIC-8 ✅ | DIP-8 ✅ | 2.7 nV/√Hz, 55 V/µs — best choice |
| **OPA1612** | SOIC-8 ✅ | DIP-8 ❌ | 1.1 nV/√Hz — better, but SMD only |
| **NE5532** | SOIC-8/DIP-8 | DIP-8 ✅ | 5 nV/√Hz — classic, good |
| **OPA2134** | SOIC-8/DIP-8 | DIP-8 ✅ | 8 nV/√Hz — "audiophile", but worse specs |

---

## 8. Design Decision Matrix

### When to Choose a Linear Power Supply

- ✅ 230V AC mains connection available
- ✅ THT hand assembly desired or required
- ✅ Space and weight are not a concern
- ✅ Maximum layout tolerance desired (beginner PCB)
- ✅ No JLCPCB assembly planned
- ✅ Op-amp socket swapping desired

### When to Choose SMPS + LDO

- ✅ DC input (12V/24V/48V)
- ✅ Galvanic isolation required
- ✅ Compact form factor desired
- ✅ Professional SMD assembly (JLCPCB)
- ✅ Lowest self-noise target (<15 µV RMS)
- ✅ Layout experience available (distance, orientation, stitching)
- ✅ No 230V transformer desired (safety, cost)

### Our Design: DC/DC + LDO — Assessment

| Criterion | Rating | Note |
|---|---|---|
| Conducted noise | ✅ Excellent | ~126 dB total attenuation at 300 kHz |
| Radiated EMI | ⚠️ Layout-dependent | TEL5-2422 must be ≥20 mm from audio inputs |
| LDO self-noise | ✅ Very good | ADP7118: 11 µV RMS |
| PSRR at switching frequency | ⚠️ Limited | ~35–45 dB at 1V dropout @ 300 kHz |
| Rail stiffness | ⚠️ Low | 100 µF = 0.012 J (75× less than 3900 µF electrolytic) |
| Galvanic isolation | ✅ | TEL5-2422 provides isolation |
| Compactness | ✅ | Entire PSU on ~15 cm² |
| JLCPCB-compatible | ✅ | Fully auto-assemblable |

---

## 9. Critical PCB Layout Rules for DC/DC Converters Near Audio

These rules apply **in addition to** the general PCB layout rules in the Copilot Instructions document:

1. **DC/DC converter ≥ 20 mm from nearest sensitive audio input** (XLR-In → differential receiver input)
2. **Unbroken GND plane (B.Cu) under all audio traces** — no interruptions, no via holes in critical areas
3. **Keep DC/DC return currents on one side of the board** — switching current return paths must not flow through the analog area
4. **Orient TEL5-2422 with long axis parallel to board edge**, away from analog area — the internal transformer field couples directionally
5. **GND via stitching wall** between DC/DC and analog area — at least one via every 3 mm
6. **No signal traces over the TEL5-2422 footprint** (F.Cu) — direct inductive coupling
7. **Consider copper keep-out zone** on F.Cu over and immediately beside the DC/DC module (2–3 mm margin)
8. **Input filter capacitors directly at TEL5-2422** (<3 mm) — reduces the "hot loop" area
9. **Bulk capacitors (100 µF) between DC/DC output and LDO input** — energy storage for transient demands

---

## 10. Power Budget Analysis — Transient Handling

### Input Voltage: 24V DC

The TEL5-2422 accepts **18–36 V input**. A 24V DC supply sits perfectly in the center of this range. All analysis in this document assumes 24V DC input. No design changes required.

### Current Budget Per Rail

| Item | V+ Rail | V− Rail |
|---|---|---|
| 12× LM4562 quiescent current (5 mA each) | 60 mA | 60 mA |
| Class-AB bias shift under signal (~2–3 mA/package) | +24–36 mA | +24–36 mA |
| Signal current into load (47Ω → 10+ kΩ ICEpower input) | <6 mA (all 24 outputs) | <6 mA |
| **Estimated peak** | **~100 mA** | **~100 mA** |

### Why the Load Current Is Negligible

ICEpower module inputs are typically 10–20 kΩ balanced. Even at ±10 V peak through a 47Ω series resistor: $I_{signal} = \frac{10\text{ V}}{47\text{ Ω} + 10\text{ kΩ}} \approx 1\text{ mA}$ per output. With 24 outputs total: ~5 mA signal current. The dominant current draw comes from LM4562 quiescent current and Class-AB output stage bias shift — not from driving the load.

### Transient Defense Hierarchy

Audio transients (drum hits, impulses) are **not** served by the LDO or DC/DC — they are served by the **local decoupling capacitors**:

| Transient Duration | Served By | Capacitance |
|---|---|---|
| < 1 µs | 100 nF C0G at IC pin (24× total, 2 per LM4562) | 2.4 µF aggregate |
| 1–100 µs | 10 µF X5R bulk (C24/C25 + C74–C79 = 8 caps) | 80 µF aggregate |
| > 100 µs | 100 µF board bulk (C20/C21) | 200 µF aggregate |
| Steady-state (ms) | LDO regulates to refill capacitors | Continuous |

**Voltage droop example**: 50 mA pulse for 1 ms into 100 µF board bulk: $\Delta V = \frac{I \cdot t}{C} = \frac{0.05 \times 0.001}{0.0001} = 0.5\text{ V}$. This is significant, but the closer 10 µF caps absorb the majority before the pulse reaches board-level bulk caps. The multi-tier decoupling structure ensures that fast transients see low ESR/ESL capacitors first.

### ADP7182 (−11V LDO) — Replacement Needed?

**No.** 200 mA provides ~2× headroom over the realistic ~100 mA peak. The apparent asymmetry vs. the ADP7118 (1.5 A positive rail) is misleading — the TEL5-2422 limits **both** rails to 208 mA anyway, so the ADP7118's 1.5 A capacity is irrelevant. Both rails are TEL5-limited.

| Parameter | ADP7118 (V+) | ADP7182 (V−) | Bottleneck |
|---|---|---|---|
| LDO max current | 1.5 A | 200 mA | TEL5-2422 (208 mA) |
| Effective max (TEL5 limited) | 208 mA | 200 mA | ADP7182 at 200 mA |
| Quiescent load | ~62 mA | ~62 mA | — |
| Estimated peak | ~100 mA | ~100 mA | — |
| Headroom | 108 mA (52%) | 100 mA (50%) | Adequate on both |

### TEL5-2422 — Sufficient for Transients?

**Yes.** At realistic ~100 mA peak, the TEL5-2422 operates at <50% capacity.

**Dropout risk at high load**: The TEL5-2422 has ±5% load regulation (datasheet). At 200 mA worst case: $V_{out,min} = 12\text{ V} \times 0.95 = 11.4\text{ V}$. The ADP7182 dropout at 200 mA is ~0.3 V, requiring ≥11.3 V input → margin is only 0.1 V. **However**, we never reach 200 mA. At the realistic 100 mA peak, the TEL5 output stays at ~11.7–11.8 V, and ADP7182 dropout at 100 mA is <0.2 V → **~0.6 V headroom — comfortable.**

An upgrade to TEL 10-2422 (10 W, ~416 mA per rail) would only be justified if:

- Significantly more op-amps were added, or
- Low-impedance loads (<600 Ω) were driven directly

### Summary

| Question | Answer | Rationale |
|---|---|---|
| 24V supply — changes anything? | **No** | TEL5-2422 operates optimally at 24V (18–36V range) |
| Replace ADP7182? | **No** | 200 mA is ~2× the realistic peak. Both rails are TEL5-limited at 208 mA anyway |
| TEL5-2422 sufficient? | **Yes** | 208 mA at ~100 mA peak. Dropout only critical at theoretical max, not at real load |
| What handles transients? | **Local decoupling caps** | 24× 100nF C0G + 8× 10µF X5R + 2× 100µF — not the LDO or DC/DC |

---

## 11. Sources and References

| Source | Content | Status |
|---|---|---|
| Rod Elliott, ESP — "Linear Power Supply Design" | Comprehensive analysis of linear supplies, myths, capacitor sizing | ✅ Fully read |
| Rod Elliott, ESP — "Switchmode Power Supply Primer" | SMPS topologies, fundamentals, EMI issues | ✅ Fully read |
| Analog Devices — "Switching Regulator Noise Reduction with an LC Filter" (Frederik Dostal) | Hot-loop EMI, input-side filtering, inductive coupling | ✅ Fully read |
| ADP7118 Datasheet (Rev.H) | PSRR: 88dB@10kHz, 68dB@100kHz, 50dB@1MHz (at VOUT≤5V, VIN=7V) | ✅ Specifications extracted |
| ADP7182 Datasheet | Negative LDO, 200 mA, SOT-23-5 | ✅ Specifications from schematic |
| TEL5-2422 Datasheet | Isolated DC/DC, DIP-24, ±12V, ±208 mA | 📄 Local in datasheets/ |
| Benchmark Media — "Audio Myth: Switching Power Supplies Are Noisy" | SMPS defense from professional audio perspective | ❌ Website unreachable |
| Neurochrome — "Switching vs Linear Power Supplies" | Professional audio PSU comparisons | ❌ Website unreachable |
| Audiophonics — Buffer board product pages | Commercial THT buffers with LM317 PSU | ✅ Analyzed |
| DIYaudio Forum — ICEpower buffer discussions | Community designs, XRK971 BTSB | ✅ Partially analyzed |

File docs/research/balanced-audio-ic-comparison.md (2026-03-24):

# Balanced Audio Line Receiver & Driver ICs — Research Report

**Project:** Aurora DSP ICEpower Booster
**Date:** 2026-03-12
**Purpose:** Comparison of dedicated balanced audio ICs vs. discrete LM4562 solution

---

## 1. THAT Corporation — InGenius Receivers & OutSmarts Drivers

### 1.1 THAT1240 — Balanced Line Receiver (InGenius)

| Parameter | Value |
|---|---|
| **Function** | Balanced → Single-Ended, 1 channel |
| **Topology** | InGenius™ — patented combination of current feedback + servo |
| **Gain** | Unity (0 dB) |
| **Package** | DIP-8 (THAT1240P08), SOIC-8 (THAT1240S08) |
| **CMRR** | >90 dB DC to 20 kHz (typ.) |
| **CMRR with source impedance mismatch** | >60 dB even at 10% source mismatch! |
| **THD+N** | 0.0004% typ. @ 1 kHz |
| **Noise** | -103 dBu (A-weighted) |
| **Bandwidth** | ~4 MHz |
| **Slew Rate** | ~8 V/µs |
| **Max Input Level** | +26 dBu @ ±18V supply |
| **Supply** | ±5V to ±18V |
| **Quiescent Current** | ~4.5 mA |
| **Price (Mouser/DigiKey)** | ~$3.50–$5.00 |
| **LCSC/JLCPCB** | ❌ **NOT AVAILABLE** |

**Key feature:** The decisive advantage of the InGenius topology is that CMRR remains high even with unbalanced source impedances. A standard differential amplifier (e.g., INA134, SSM2143) loses its CMRR proportionally to the impedance mismatch at the inputs — often dramatically in real-world cabling scenarios. InGenius circumvents this through a servo loop that dynamically adapts the input impedance.

### 1.2 THAT1246 — Balanced Line Receiver (InGenius, +6 dB)

| Parameter | Value |
|---|---|
| **Function** | Balanced → SE, 1 channel, **Gain = 2 (+6 dB)** |
| **Topology** | InGenius™ (identical to THAT1240) |
| **Package** | DIP-8, SOIC-8 |
| **All specs** | Same as THAT1240, but G = 2 |
| **LCSC/JLCPCB** | ❌ **NOT AVAILABLE** |

The THAT1246 is preferred when the receiver needs to compensate for the -6 dB level loss of the professional balanced line (±half level), which at G=2 yields exactly unity gain across the entire signal path.

### 1.3 THAT1200 — Balanced Line Receiver (predecessor)

| Parameter | Value |
|---|---|
| **Function** | Balanced → SE, 1 channel |
| **Topology** | Standard differential amplifier with trimmed resistors |
| **CMRR** | ~70 dB typ. (significantly worse than 1240 series) |
| **Package** | DIP-8, SOIC-8 |
| **Status** | Superseded by THAT1240 series |
| **LCSC/JLCPCB** | ❌ **NOT AVAILABLE** |

**Assessment:** Obsolete, no reason to use the 1200 series. The 1240 is superior in every regard.

### 1.4 THAT1606 — Balanced Line Driver (OutSmarts)

| Parameter | Value |
|---|---|
| **Function** | Single-Ended → Balanced, 1 channel |
| **Topology** | OutSmarts™ — cross-coupled with servo feedback |
| **Gain** | Unity (0 dB) |
| **Package** | SOIC-8 |
| **THD+N** | 0.0003% typ. @ 1 kHz |
| **Output Balance** | >60 dB even with unbalanced load |
| **Noise** | -107 dBu (A-weighted) |
| **Max Output** | +24 dBu @ ±18V supply |
| **Slew Rate** | ~15 V/µs |
| **Supply** | ±5V to ±18V |
| **Quiescent Current** | ~6.5 mA |
| **Price (Mouser/DigiKey)** | ~$4.00–$6.00 |
| **LCSC/JLCPCB** | ❌ **NOT AVAILABLE** |

**Key feature:** The OutSmarts topology maintains output balance even with unbalanced loads (e.g., when only one pin is loaded). A standard cross-coupled driver (like DRV134) loses balance here. Additionally, OutSmarts enables "electronic impedance balancing" that improves common-mode rejection at the receiver.

### 1.5 THAT1646 — Balanced Line Driver (OutSmarts, +6 dB)

| Parameter | Value |
|---|---|
| **Function** | SE → Balanced, 1 channel, **Gain = 2 (+6 dB)** |
| **Topology** | OutSmarts™ (identical to THAT1606) |
| **Package** | SOIC-8 |
| **All specs** | Same as THAT1606, but G = 2 |
| **LCSC/JLCPCB** | ❌ **NOT AVAILABLE** |

---

## 2. TI/Burr-Brown — DRV134/DRV135 Line Drivers

### 2.1 DRV134 — Audio Balanced Line Driver (PDIP-8 / SOIC-16)

| Parameter | Value |
|---|---|
| **Function** | SE → Balanced, 1 channel |
| **Topology** | Cross-coupled with precision resistors |
| **Package** | PDIP-8 (DRV134PA), SOIC-16 (DRV134UA) |
| **THD+N** | 0.0005% typ. @ 1 kHz |
| **Slew Rate** | 15 V/µs |
| **Max Output** | 17 Vrms into 600Ω |
| **Supply** | ±4.5V to ±18V (9–36V) |
| **Quiescent Current** | 5.2 mA |
| **Price (TI 1ku)** | ~$2.28–$2.74 |
| **Status** | **ACTIVE** — Improved replacement for SSM2142 |

**LCSC Availability:**

| Part Number | Package | Stock | Price (1 pc) |
|---|---|---|---|
| DRV134PA | PDIP-8 | 0 (back-order) | $6.29 |
| DRV134UA/1K | SOIC-16 | 5 pcs | $5.95 |

⚠️ **Very low LCSC stock. SOIC-16 is inconvenient for audio PCBs (large). PDIP-8 not SMT-compatible for JLCPCB assembly.**

### 2.2 DRV135 — Audio Balanced Line Driver (SOIC-8)

| Parameter | Value |
|---|---|
| **Function** | SE → Balanced, 1 channel |
| **Topology** | Identical to DRV134 |
| **Package** | **SOIC-8** (space-efficient!) |
| **All specs** | Identical to DRV134 |
| **Status** | **ACTIVE** |

**LCSC Availability:**

| Part Number | Package | Stock | Price (1 pc) |
|---|---|---|---|
| DRV135UA | SOIC-8 | 0 (back-order) | $3.46 |
| DRV135UA/2K5 | SOIC-8 | **3,865 pcs** ✅ | **$2.78** |

✅ **DRV135UA/2K5 is the best candidate among dedicated line drivers for JLCPCB assembly!** Good stock, SOIC-8 package, reasonable price.

### 2.3 INA1634 (TI)

| Parameter | Value |
|---|---|
| **Status** | ❌ **Does not exist** (TI website returns 404) |

**Note:** The existing TI differential receivers for audio are:

- **INA134** — Differential Line Receiver, G = 1, SOIC-8/DIP-8 (companion to DRV134)
- **INA137** — Differential Line Receiver, G = 1/2, SOIC-8/DIP-8

These have ~80 dB CMRR but suffer like all standard differential amplifiers from CMRR degradation with source impedance mismatch.

---

## 3. Analog Devices — SSM2142/SSM2143

### 3.1 SSM2142 — Balanced Line Driver

| Parameter | Value |
|---|---|
| **Function** | SE → Balanced, 1 channel |
| **Status** | ⛔ **OBSOLETE** |
| **Package** | DIP-8 (only!) |
| **THD** | 0.006% typ., 20 Hz–20 kHz, 10V RMS into 600Ω |
| **CMRR** | 80 dB |
| **Slew Rate** | 15 V/µs |
| **Max Output** | 10V RMS into 600Ω |
| **Supply** | ±15V (fixed, no wide range) |

**LCSC Availability:**

| Part Number | Stock | Price |
|---|---|---|
| SSM2142PZ | 0 | $149.83 (!) |
| SSM2142SZ (3rd party) | 95 | $78.52 |

⛔ **DO NOT USE. Obsolete, absurdly expensive, DIP-8 only, worse specs than DRV134/135.**

### 3.2 SSM2143 — Differential Line Receiver

| Parameter | Value |
|---|---|
| **Function** | Balanced → SE, 1 channel |
| **Status** | ⛔ **OBSOLETE** |
| **Package** | SOIC-8 (SSM2143S/SZ), PDIP-8 (SSM2143P) |
| **CMRR** | 90 dB @ DC/60 Hz, 85 dB @ 20 kHz |
| **THD** | 0.0006% typ. @ 1 kHz |
| **Slew Rate** | 10 V/µs |
| **Bandwidth** | 7 MHz (G = 1/2) |
| **Gain** | G = 1/2 (or G = 2 via pin swap) |
| **Max Input** | +28 dBu @ G = 1/2 |
| **Supply** | ±5V to ±18V |
| **Replacement** | AD8273 (recommended by ADI) |

**LCSC Availability:**

| Part Number | Stock | Price |
|---|---|---|
| SSM2143S | Discontinued | — |
| SSM2143P | Discontinued | — |
| SSM2143SZ | 0 (SOIC-8) | $8.83 |
| SSM2143S-REEL | Discontinued | — |

⚠️ **Obsolete and poorly available. The SSM2143 was a very good IC, but no longer recommended for new designs.**

---

## 4. LM4562 — Discrete Balanced Solution (current design)

### 4.1 LM4562 — Dual Low-Noise Audio Op-Amp

| Parameter | Value |
|---|---|
| **Function** | Dual operational amplifier, general purpose |
| **Package** | SOIC-8 (LM4562MAX), PDIP-8 (LM4562NA) |
| **THD+N** | **0.00003%** typ. @ 1 kHz (!) |
| **Noise** | 2.7 nV/√Hz |
| **Slew Rate** | 20 V/µs |
| **GBW** | 55 MHz |
| **Supply** | ±2.5V to ±17V |
| **Output** | ±13.5V @ 600Ω (with ±15V) |
| **Quiescent Current** | 5 mA/channel |

**LCSC Availability:**

| Part Number | Package | Stock | Price (1 pc) | Price (500+) |
|---|---|---|---|---|
| **LM4562MAX/NOPB** | **SOIC-8** | **5,453 pcs** ✅ | $2.08 | **$1.36** |
| LM4562NA/NOPB | PDIP-8 | 199 pcs | $9.24 | — |

✅ **Excellent availability, best price, SOIC-8 perfect for JLCPCB assembly.**

---

## 5. LCSC/JLCPCB Availability Summary

| IC | LCSC available? | Stock | Best Price | Package | Assembly-ready? |
|----|---|---|---|---|---|
| **THAT1240** | ❌ No | 0 | — | — | No |
| **THAT1246** | ❌ No | 0 | — | — | No |
| **THAT1200** | ❌ No | 0 | — | — | No |
| **THAT1606** | ❌ No | 0 | — | — | No |
| **THAT1646** | ❌ No | 0 | — | — | No |
| **INA1634** | ❌ Does not exist | — | — | — | — |
| **DRV134PA** | ⚠️ Yes (0 pcs) | 0 | $6.29 | PDIP-8 | ❌ THT |
| **DRV134UA** | ⚠️ Yes (5 pcs) | 5 | $5.95 | SOIC-16 | ⚠️ Large |
| **DRV135UA/2K5** | ✅ **Yes** | **3,865** | **$2.78** | **SOIC-8** | ✅ **Yes** |
| **SSM2142** | ⚠️ Yes (0 pcs) | 0 | $149.83 | DIP-8 | ❌ Obsolete/THT |
| **SSM2143SZ** | ⚠️ Yes (0 pcs) | 0 | $8.83 | SOIC-8 | ❌ Obsolete |
| **LM4562MAX** | ✅ **Yes** | **5,453** | **$2.08** | **SOIC-8** | ✅ **Yes** |

---

## 6. Comparison: Dedicated ICs vs. Discrete LM4562 Solution

### 6.1 Balanced Receiver: THAT1240 vs. LM4562 Differential Amplifier

#### LM4562-based Differential Receiver (current design)

```
Circuit: 1× LM4562 (dual) per channel
  - OPA1: Instrumentation amplifier topology or
  - Simple differential amplifier with 4× precision resistors (0.1%)

Components per channel:
  - 1× LM4562 (SOIC-8)
  - 4× resistors 0.1% (0402/0603)
  - 2–4× capacitors (decoupling)
  = 7–9 components, ~15 mm² PCB area
```

#### THAT1240 Receiver

```
Components per channel:
  - 1× THAT1240 (SOIC-8)
  - 2× capacitors (decoupling)
  = 3 components, ~8 mm² PCB area
```

| Criterion | THAT1240 | LM4562 discrete |
|---|---|---|
| Component count/channel | 3 | 7–9 |
| PCB area/channel | ~8 mm² | ~15 mm² |
| THD+N | 0.0004% | **0.00003%** (10× better!) |
| CMRR (ideal) | >90 dB | ~80 dB (depends on R matching) |
| CMRR (with source mismatch) | **>60 dB** (InGenius advantage!) | ~40–50 dB (degrades!) |
| Noise | -103 dBu | **-108 dBu** (LM4562 is quieter) |
| IC cost/channel | ~$4.00 | **~$2.08** (+ ~$0.20 R) |
| JLCPCB Assembly | ❌ **NO** | ✅ **YES** |
| Design effort | Minimal | Medium (R matching, layout) |

### 6.2 Balanced Driver: DRV135 vs. LM4562 Buffer+Inverter

#### LM4562-based Balanced Driver (current design)

```
Circuit: 1× LM4562 (dual) per channel
  - OPA1: Unity-gain buffer (output = +signal)
  - OPA2: Inverting amplifier G=-1 (output = -signal)
  - 3× resistors for inverter

Components per channel:
  - 1× LM4562 (SOIC-8)
  - 3× resistors 0.1% (0402/0603)
  - 2–4× capacitors (decoupling)
  = 6–8 components, ~12 mm² PCB area
```

#### DRV135 Driver

```
Components per channel:
  - 1× DRV135 (SOIC-8)
  - 2× capacitors (decoupling)
  = 3 components, ~8 mm² PCB area
```

| Criterion | DRV135 | LM4562 discrete |
|---|---|---|
| Component count/channel | 3 | 6–8 |
| PCB area/channel | ~8 mm² | ~12 mm² |
| THD+N | 0.0005% | **0.00003%** (15× better!) |
| Output balance (ideal) | ~60 dB (laser-trimmed R) | ~50 dB (depends on R matching) |
| Output balance (unbal. load) | ~40 dB | ~40 dB (both degrade) |
| Noise | ~-100 dBu | **~-108 dBu** |
| Max output | 17 Vrms/600Ω | ~13.5 Vrms/600Ω |
| IC cost/channel | $2.78 | **$2.08** (+ ~$0.15 R) |
| JLCPCB Assembly | ✅ Yes (3,865 pcs) | ✅ **Yes** (5,453 pcs) |
| Design effort | Minimal | Medium |

### 6.3 Overall Comparison: 3-Channel System (3× Receiver + 3× Driver)

| Criterion | Dedicated ICs (THAT/DRV) | 6× LM4562 discrete |
|---|---|---|
| **Total ICs** | 3× THAT1240 + 3× DRV135 = 6 ICs | 6× LM4562 = 6 ICs |
| **Resistors** | 0 | 21× precision R (0.1%) |
| **Total components** | ~18 + 12 caps = ~30 | ~42 + 12 caps = ~54 |
| **PCB area** | ~48 mm² | ~81 mm² |
| **THD+N** | 0.0003–0.0005% | **0.00003%** |
| **Noise floor** | ~-103 dBu | **~-108 dBu** |
| **CMRR (receiver, real)** | **>60 dB (InGenius!)** | ~40–50 dB |
| **IC cost** | 3×$4 + 3×$2.78 = $20.34 | 6×$2.08 = **$12.48** |
| **Total cost** | ~$21 (few R) | ~**$14** (21 R @ $0.05) |
| **JLCPCB Assembly** | ❌ THAT not on LCSC! | ✅ **Fully available** |

---

## 7. Recommendation

### 7.1 For JLCPCB Manufacturing: LM4562 Discrete (clear winner)

**The discrete LM4562 solution is the right choice for this project:**

1. **Availability:** LM4562MAX/NOPB has >5,400 pcs at LCSC, SOIC-8, $2.08/pc. All THAT Corp ICs are not available at LCSC and are therefore disqualified for JLCPCB assembly.

2. **Audio Performance:** LM4562 is **significantly superior** to the dedicated ICs in THD+N and noise performance (factor 10–15 in THD, 5 dB in noise). The theoretically better CMRR of the THAT1240 is only relevant when the signal source has strongly unbalanced impedances — rarely the case in an internal amplifier board.

3. **Cost:** ~$14 vs. ~$21 for 3 channels. More components, but cheaper ICs and standard resistors.

4. **Flexibility:** With LM4562, gain can be freely adjusted (not limited to unity or +6 dB).

### 7.2 Only Possible DRV135 Use Case

If the balanced output stage should be simplified, the **DRV135UA/2K5** would be an option:

- 3,865 pcs available at LCSC
- SOIC-8, $2.78/pc
- Saves 3× resistors and layout effort per channel
- But worse THD than LM4562 solution

**Possible hybrid approach:**

- **Receiver:** 3× LM4562 as differential amplifier (better performance, available)
- **Driver:** 3× DRV135 (fewer components, acceptable performance, available)
- Cost advantage: Less PCB area for drivers, full performance for receivers

### 7.3 When THAT ICs Would Make Sense

THAT Corporation ICs would only be justified when:

- The board is **not assembled at JLCPCB** (hand assembly / different assembler)
- The signal source has **unknown/variable source impedances** (e.g., external mixer over long cables)
- CMRR under real-world conditions is absolutely critical

For an internal ICEpower booster board where signals come from a known DSP, the advantages of the LM4562 solution outweigh.

### 7.4 Recommended Approach

```
✅ Receiver (Balanced → SE):  3× LM4562MAX/NOPB (SOIC-8)
                               + 12× 0.1% resistors (10k/10k or adjusted)
                               + 6× decoupling caps

✅ Driver (SE → Balanced):     3× LM4562MAX/NOPB (SOIC-8)
                               + 9× 0.1% resistors (buffer + inverter)
                               + 6× decoupling caps

Alternative Driver:            3× DRV135UA/2K5 (SOIC-8, $2.78)
                               + 6× decoupling caps
                               (fewer components, slightly worse THD)
```

---

## 8. Design Notes for LM4562-Based Solution

### 8.1 Receiver (Differential Amplifier)

- **Resistor matching is CRITICAL for CMRR:** Use 0.1% resistors (e.g., Panasonic ERA series)
- Alternatively: Resistor networks (e.g., Bourns CAT16) for even better matching
- Typical CMRR with 0.1% matching: ~66 dB. With 0.01%: ~86 dB.
- **Layout:** Place resistors thermally coupled (adjacent, same orientation)
- CMRR formula: $CMRR \approx 20 \log_{10}\left(\frac{1}{4 \cdot \delta}\right)$ where $\delta$ is the relative resistor error

### 8.2 Driver (Buffer + Inverter)

- **Inverter resistors:** 0.1% for good output balance
- No resistors in the buffer path (unity-gain follower)
- Output balance: $Balance \approx 20 \log_{10}\left(\frac{1}{2 \cdot \delta}\right)$
- 100Ω series resistors at both outputs for short-circuit protection + HF damping

### 8.3 General

- 100nF C0G directly at VCC/GND pins of each LM4562
- 10µF bulk cap per supply rail
- No signal traces under ICs on the ground plane
- Guard traces around sensitive receiver inputs

---

## Appendix: All Investigated ICs at a Glance

| IC | Manufacturer | Type | Function | Package | THD+N | CMRR/Balance | Supply | Status | LCSC? | Price |
|----|---|-----|---|---|---|---|---|---|---|---|
| THAT1240 | THAT Corp | Receiver | Bal→SE G=1 | DIP-8/SOIC-8 | 0.0004% | 90 dB | ±5–±18V | Active | ❌ | ~$4 |
| THAT1246 | THAT Corp | Receiver | Bal→SE G=2 | DIP-8/SOIC-8 | 0.0004% | 90 dB | ±5–±18V | Active | ❌ | ~$4 |
| THAT1200 | THAT Corp | Receiver | Bal→SE | DIP-8/SOIC-8 | ~0.003% | 70 dB | ±5–±18V | Legacy | ❌ | ~$3 |
| THAT1606 | THAT Corp | Driver | SE→Bal G=1 | SOIC-8 | 0.0003% | >60 dB bal | ±5–±18V | Active | ❌ | ~$5 |
| THAT1646 | THAT Corp | Driver | SE→Bal G=2 | SOIC-8 | 0.0003% | >60 dB bal | ±5–±18V | Active | ❌ | ~$5 |
| DRV134 | TI | Driver | SE→Bal | DIP-8/SOIC-16 | 0.0005% | ~60 dB bal | ±4.5–±18V | Active | ⚠️ | ~$5.95 |
| DRV135 | TI | Driver | SE→Bal | **SOIC-8** | 0.0005% | ~60 dB bal | ±4.5–±18V | Active | ✅ | **$2.78** |
| INA1634 | TI | — | — | — | — | — | — | ❌ DNE | ❌ | — |
| SSM2142 | ADI | Driver | SE→Bal | DIP-8 | 0.006% | 80 dB | ±15V | ⛔ Obsolete | ⚠️ | $149 |
| SSM2143 | ADI | Receiver | Bal→SE G=½ | SOIC-8/DIP-8 | 0.0006% | 90 dB | ±5–±18V | ⛔ Obsolete | ⚠️ | $8.83 |
| **LM4562** | **TI** | **Op-Amp** | **Dual** | **SOIC-8** | **0.00003%** | **n/a** | **±2.5–±17V** | **Active** | ✅ | **$2.08** |

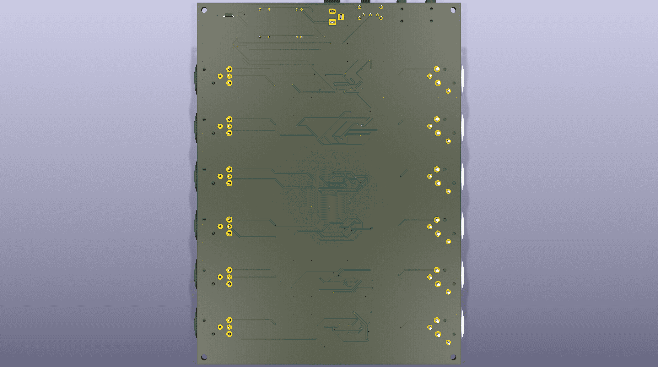
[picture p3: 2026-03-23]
production/aurora-dsp-icepower-booster-3d-bottom.png

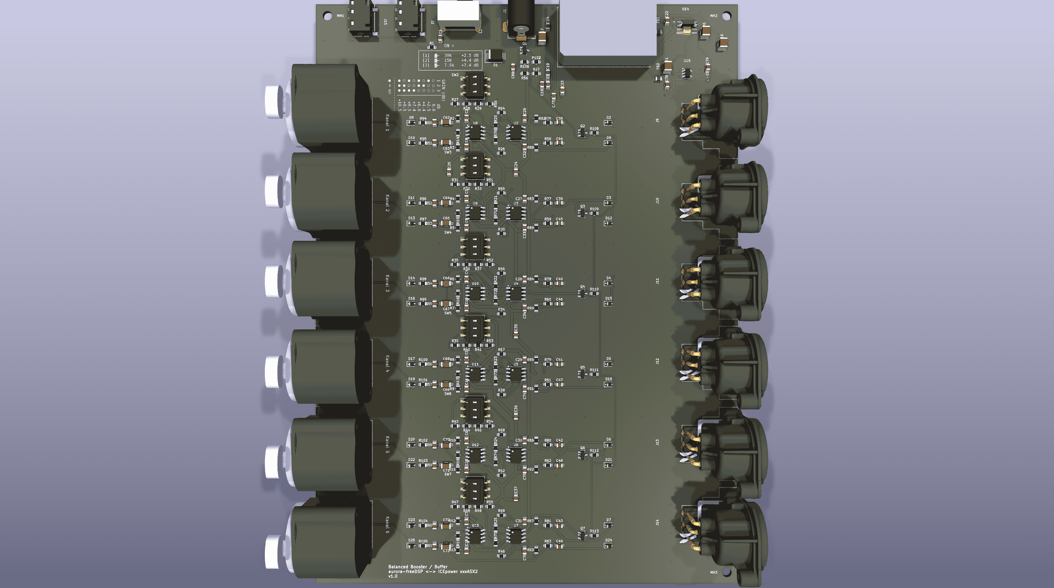
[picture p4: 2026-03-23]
production/aurora-dsp-icepower-booster-3d-top.png

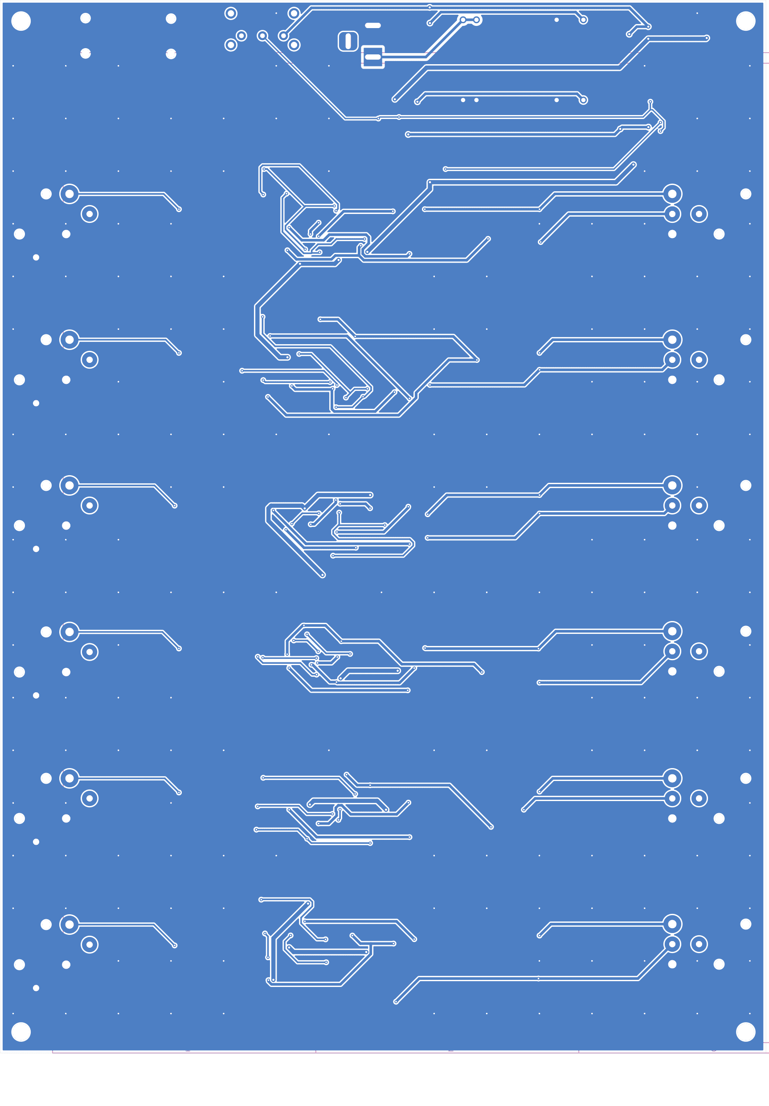
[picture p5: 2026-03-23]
production/aurora-dsp-icepower-booster-pcb-back.png

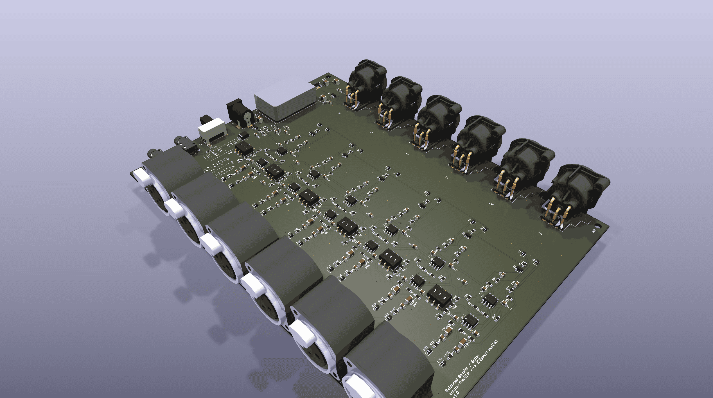
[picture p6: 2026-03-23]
production/aurora-dsp-icepower-booster-3d-iso.png

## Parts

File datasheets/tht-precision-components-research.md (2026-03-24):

# Through-Hole Präzisionsbauteile — Research Report

**Projekt:** Aurora DSP IcePower Booster  
**Datum:** 2026-03-12  
**Zweck:** Beschaffungsrecherche für THT-Präzisionswiderstände (0.1%) und Kondensatoren für Audio-Differenzverstärker (DIY)

---

## Zusammenfassung (TL;DR)

| Kategorie | Empfehlung | Preis (1 Stk.) | Verfügbarkeit |
|---|---|---|---|
| **0.1% 10kΩ Widerstand** | YAGEO MFP-25BRD52-10K | ~$0.60 | ✅ DigiKey 26k+ Stk. |
| **0.1% 10kΩ (Alternative)** | TE YR1B10KCC (Neohm) | ~$0.79 | ✅ DigiKey 77k+ Stk. |
| **0.1% 10kΩ (LCSC)** | Vishay CMF5510K000BEEB | ~$1.40 | ⚠️ LCSC 197 Stk. |
| **100nF C0G THT** | ❌ Existiert praktisch nicht | — | ❌ |
| **100nF Film (Ersatz)** | WIMA MKS2D031001A00JSSD | ~$0.57 | ⚠️ LCSC 12 Stk. |
| **10µF Elko THT** | Nichicon/Panasonic Standard | ~$0.10–0.30 | ✅ Massenverfügbar |
| **100µF Elko THT** | Nichicon/Panasonic Standard | ~$0.10–0.50 | ✅ Massenverfügbar |
| **47Ω 1% Widerstand** | YAGEO MFR-25FRF52-47R | ~$0.10 | ✅ DigiKey 100k+ Stk. |

**Kernaussage:** 0.1% THT-Widerstände sind gut verfügbar und bezahlbar ($0.60–$1.40). 100nF C0G in THT existiert nicht — verwende Polyester-Film (WIMA MKS2) oder SMD C0G auf Adapter.

---

## 1. Through-Hole 0.1% Präzisionswiderstände (Axial)

### 1.1 Übersicht der Serien

| Serie | Hersteller | Toleranz | Tempco | Leistung | Baugröße (D×L) | Preis (1 Stk.) |
|---|---|---|---|---|---|---|
| **CMF55** | Vishay/Dale | 0.1% (B) | ±25 ppm/°C (E) | 500 mW | 2.3×6.1 mm | $0.29–$1.40 |
| **MFP-25** | YAGEO | 0.1% | ±25 ppm/°C | 250 mW | 2.4×6.3 mm | ~$0.60 |
| **RNF14** | Stackpole | 0.1% | ±25 ppm/°C | 250 mW | 2.35×6.35 mm | ~$0.62 |
| **YR (Neohm)** | TE Connectivity | 0.1% | **±15 ppm/°C** | 250 mW | 2.3×6.3 mm | ~$0.79 |
| **MRS25** | Vishay | 0.1% | ±25–50 ppm/°C | 250 mW | 2.3×6.3 mm | ~$0.50–$1.00 |

> **Alle Baugößen sind Standard-1/4W-Axial** — identisch mit billigen Kohleschichtwiderständen. Passen problemlos auf Standard-PCBs mit 2.54mm-Raster (Pitch 7.6–10.2 mm typisch).

### 1.2 Detaillierte Teilenummern & Verfügbarkeit

#### Vishay CMF55 (Der Klassiker)

Die CMF55-Bestellnummer kodiert alle Parameter:
`CMF55` `10K000` `B` `E` `EB`

- **B** = ±0.1% Toleranz (C=0.25%, D=0.5%, F=1%)
- **E** = ±25 ppm/°C TK (H=±50ppm, K=±100ppm)
- **EB** = Verpackungs-/Spec-Code

| Teilenummer | Wert | Tol. | TK | LCSC Stock | LCSC Preis | DigiKey/Mouser |
|---|---|---|-----|---|---|---|
| **CMF5510K000BEEB** | 10kΩ | 0.1% | ±25ppm | **197 Stk.** | **$1.40** (1+) / $0.80 (1k+) | Verfügbar |
| CMF5510K000BHEA | 10kΩ | 0.1% | ±50ppm | 0 (bestellbar) | $0.28 (1+) | — |
| CMF5510K000BEEA | 10kΩ | 0.1% | ±25ppm | 0 (bestellbar) | $0.29 (1+) | — |
| CMF5510K000BERE | 10kΩ | 0.1% | ±25ppm | 0 (bestellbar) | $0.40 (1+) | — |
| CMF5510K000BHBF | 10kΩ | 0.1% | ±50ppm | 0 (bestellbar) | $0.97 (1+) | — |

**Bewertung CMF55:** Gold-Standard für Audio-Precision. Problem: Bei LCSC sehr geringe Lagerbestände für 0.1%-Varianten. Große Mengen müssen bestellt werden (MOQ oft 200–1000 Stk. für Pre/New-Listings).

#### YAGEO MFP-25 (Beste Verfügbarkeit bei 0.1%)

| Teilenummer | Wert | Tol. | TK | DigiKey Stock | DigiKey Preis |
|---|---|---|-----|---|---|
| **MFP-25BRD52-10K** | 10kΩ | 0.1% | ±25ppm | **26.676 Stk.** | **$0.60** (1+) / $0.16 (5k+) |
| **MFP-25BRD52-20K** | 20kΩ | 0.1% | ±25ppm | Hoch (verfügbar) | ~$0.60 |
| **MFP-25BRD52-4K70** | 4.7kΩ | 0.1% | ±25ppm | Hoch (verfügbar) | ~$0.60 |
| **MFP-25BRD52-100R** | 100Ω | 0.1% | ±25ppm | **4.958 Stk.** | **$0.60** (1+) |

**Bewertung YAGEO MFP-25:** ⭐ **KLARE EMPFEHLUNG für DIY.** Hervorragende Verfügbarkeit bei DigiKey, günstiger Preis, alle relevanten Werte verfügbar. Standardgröße 1/4W axial.

#### Stackpole RNF14 (Gute Alternative)

| Teilenummer | Wert | Tol. | TK | DigiKey Stock | DigiKey Preis |
|---|---|---|-----|---|---|
| **RNF14BTE10K0** | 10kΩ | 0.1% | ±25ppm | **20.424 Stk.** | **$0.62** (1+) / $0.16 (5k+) |
| RNF14FTD10K0 | 10kΩ | 1% | ±100ppm | 144.666 Stk. | $0.10 (1+) |

**Bewertung Stackpole RNF14:** Solide Alternative, leicht teurer. Flame-Retardant-Beschichtung und Safety-Zertifizierung — mehr als nötig für DIY, aber solide.

#### TE Connectivity YR (Neohm) — Premium

| Teilenummer | Wert | Tol. | TK | DigiKey Stock | DigiKey Preis |
|---|---|---|-----|---|---|
| **YR1B10KCC** | 10kΩ | 0.1% | **±15ppm** | **77.291 Stk.** | **$0.79** (1+) / $0.25 (1k+) |
| **YR1B20RCC** | 20Ω | 0.1% | ±15ppm | 33.065 Stk. | $0.65 (1+) |
| **YR1B1K0CC** | 1kΩ | 0.1% | ±15ppm | 8.838 Stk. | $0.83 (1+) |
| **YR1B1M0CC** | 1MΩ | 0.1% | ±15ppm | 11.306 Stk. | $0.61 (1+) |

**Bewertung TE YR Neohm:** ⭐ **Bester TK (±15 ppm/°C)** aller verfügbaren Serien. Wenn Temperaturstabilität kritisch ist (z.B. Gain-Setting in Feedback-Netzwerken), ist diese Serie die beste Wahl. Sehr gute Verfügbarkeit. Hinweis: Für 4.7kΩ, 20kΩ, 47Ω müssen Verfügbarkeiten einzeln geprüft werden — nicht alle E96-Werte werden geführt.

### 1.3 Preisvergleich: 0.1% vs. 1% vs. 5%

| Toleranz | Beispiel (10kΩ) | Preis (1 Stk.) | Preis (100+) |
|---|---|---|---|
| 5% Carbon Film | CF14JT10K0 | $0.10 | $0.008 |
| 1% Metal Film | MFR-25FRF52-10K (YAGEO) | $0.10 | $0.013 |
| **0.1% Metal Film** | **MFP-25BRD52-10K (YAGEO)** | **$0.60** | **$0.16** |
| 0.1% + ±15ppm TK | YR1B10KCC (TE Neohm) | $0.79 | $0.25 |

**Ergebnis:** 0.1% kostet 6× mehr als 1%, aber in absoluten Zahlen immer noch sehr günstig ($0.60/Stk.). Für einen Differenzverstärker mit 8–16 Widerständen sind das nur ~$5–$13 Mehrkosten.

### 1.4 Widerstandsnetzwerke (SIP/DIP) — 0.1%

**Ergebnis: Praktisch nicht verfügbar.**

- Standard-SIP/DIP-Netzwerke (Bourns, CTS) gibt es typisch nur in 2% oder 1%
- 0.1%-Netzwerke existieren als Spezialteile (Vishay Bulk Metal Foil, z.B. NOMC-Serie), aber:
  - Extrem teuer ($10–$50+/Stk.)
  - Sehr eingeschränkte Wertekombinationen
  - Lange Lieferzeiten

**Empfehlung:** Einzelwiderstände verwenden. Der Vorteil von Netzwerken (garantiertes Matching) wird bei 0.1%-Einzelwiderständen weitgehend irrelevant — zwei 0.1%-Widerstände aus dem gleichen Reel sind typisch innerhalb von 0.02% gematcht.

> **Tipp für bestes Matching:** 10+ Stück des gleichen Werts bestellen (aus Tape & Reel), mit DMM messen, und die am besten passenden Paare bilden. Bei 0.1%-Nenntoleranz erreicht man so typisch <0.01% Matching.

---

## 2. Through-Hole Kondensatoren

### 2.1 100nF C0G/NP0 — Through-Hole

#### ❌ EXISTIERT PRAKTISCH NICHT IN THT

**Warum?**

- C0G/NP0 hat eine sehr niedrige Dielektrizitätskonstante (~30 vs. ~3000 bei X7R)
- 100nF in C0G erfordert daher **große physische Abmessungen**
- Als SMD erst ab **1206** verfügbar (3.2×1.6 mm) — schon das ist groß für SMD
- THT-Keramikkondensatoren (Disc-Typ) mit C0G existieren nur bis ca. **10nF** (10.000pF)
- Darüber hinaus werden THT-Keramiken typisch als X7R oder Y5V angeboten

**Verfügbarkeit 100nF C0G auf LCSC/DigiKey:**

- Alle gefundenen 100nF C0G sind **SMD** (1206, 1210, 1812, 2220)
- TDK CGA-Serie: 100nF C0G 50V ab 1206, Preis $0.18–$0.49 (SMD)
- Kein einziger THT-C0G-Kondensator mit 100nF gefunden

### 2.2 Alternativen für 100nF Entkopplung (THT)

#### Option A: WIMA MKS2 — Polyester-Filmkondensator ⭐ EMPFEHLUNG

| Teilenummer | Wert | Tol. | Spannung | Pitch | LCSC Stock | Preis |
|---|---|---|---|---|---|---|
| **MKS2D031001A00JSSD** | 100nF | ±5% | 100V | 5 mm | **12 Stk.** | **$0.57** |
| MKS2C031001A00KSSD | 100nF | ±10% | 63V | 5 mm | 18 Stk. | $0.44 |
| MKS2G031001K00JSSD | 100nF | ±5% | 400V | 5 mm | 0 (bestellbar) | $0.57 |

**Eigenschaften:**

- Metallisierter Polyester (PET) — **kein Mikrofonie-Effekt** (im Gegensatz zu X7R-Keramik)
- Baugröße ca. 7.2×2.5×6.5 mm bei 5mm Pitch — kompakt genug für PCB
- Verlustfaktor (tan δ) ca. 0.008–0.01 @ 1 kHz
- Nicht so gut wie C0G (tan δ < 0.001), aber für Entkopplung mehr als ausreichend
- **Audio-Standard** — wird seit Jahrzehnten in Studio-Equipment eingesetzt

**Problem bei LCSC:** Sehr geringe Lagerbestände (12–18 Stk.). Für JLCPCB-Bestückung problematisch. Besser bei Mouser/DigiKey bestellen.

#### Option B: Epcos/TDK B32529 — Polyester-Film

Ähnlich wie WIMA MKS2, oft günstiger. Verfügbarkeit bei LCSC ebenfalls eingeschränkt für THT-Varianten.

#### Option C: WIMA MKP2 — Polypropylen (PP) — Premium-Audio

- Polypropylen hat den **niedrigsten Verlustfaktor** aller Filmtypen (tan δ < 0.0005)
- Ideal für Audio-Signalpfad (Koppelkondensatoren)
- 100nF ist verfügbar, aber größere Baugröße als MKS2
- Preis höher (~$1.00–$2.00)
- **Empfehlung:** Für Entkopplung reicht MKS2 (Polyester). MKP2 (Polypropylen) nur im Signalpfad verwenden.

#### Option D: SMD C0G auf THT-Adapter

Wenn C0G zwingend erforderlich:

- SMD-C0G 100nF in 1206 auf Adapter-Platine (1206-zu-THT)
- Oder: 100nF C0G 1206 direkt auf Unterseite der Hauptplatine löten (Dead-Bug-Stil)
- Pragmatisch, aber nicht elegant

### 2.3 Empfehlung für Entkopplung (3 Stufen, THT)

| Stufe | Funktion | Typ | Empfehlung |
|---|---|-----|---|
| **HF-Entkopplung** | Direkt am IC | Keramik oder Film | WIMA MKS2 100nF (5mm Pitch) |
| **Lokale Entkopplung** | Pro Versorgungsinsel | Elko oder Film | 10µF Elko (Nichicon UKL/Panasonic FC) |
| **Bulk** | Am Versorgungseingang | Elko | 100µF+ Elko (Nichicon/Panasonic) |

> **Hinweis:** Für einen DIY THT-Aufbau ist WIMA MKS2 100nF die pragmatische Lösung. Der Verlustfaktor-Unterschied zu C0G (0.008 vs. 0.001) ist für Entkopplung vollkommen irrelevant — es geht um die Bereitstellung von Ladung, nicht um Signaltreue. Im Audio-**Signal**pfad (Koppelkondensatoren) sollte MKP (Polypropylen) verwendet werden.

### 2.4 Elektrolytkondensatoren (THT) — Bulk-Entkopplung

| Wert | Serie | Preis (LCSC/DigiKey) | Lager | Hinweis |
|---|---|---|---|---|
| 10µF 50V | Nichicon UKL, Panasonic FC | $0.05–$0.15 | ✅ Massenware | Low-ESR für Audio |
| 10µF 50V | Nichicon KA (Audio) | $0.20–$0.50 | ✅ Verfügbar | Audio-Grade, Gold-Standard |
| 100µF 50V | Nichicon UKL, Panasonic FC | $0.10–$0.30 | ✅ Massenware | Standard-Bulk |
| 100µF 25V | Nichicon MUSE (KZ) | $0.50–$2.00 | ✅ DigiKey | Audio-Spezial, bipolar |
| 1000µF 50V | Nichicon/Panasonic | $0.30–$1.00 | ✅ Massenware | Nezteil-Bulk |

**Empfehlung für Audio:**

- **Nichicon KA** (MUSE Standard) oder **Panasonic FC** für lokale Entkopplung
- Für den Signalpfad (Kopplung): lieber **Filmkondensatoren** verwenden
- Elektrolytkondensatoren sind **keine Engpassteile** — massenhaft verfügbar und günstig

---

## 3. 47Ω Serien-Ausgangswiderstände

### 3.1 Verfügbare Optionen

| Teilenummer | Serie | Tol. | TK | Leistung | DigiKey Preis | Stock |
|---|---|---|-----|---|---|---|
| **MFR-25FRF52-47R** | YAGEO MFR | 1% | ±100ppm | 1/4W | **$0.10** | 100k+ |
| RNF14FTD47R0 | Stackpole RNF | 1% | ±100ppm | 1/4W | $0.10 | 100k+ |
| CF14JT47R0 | Stackpole CF | 5% | 0/-400ppm | 1/4W | $0.10 | 100k+ |

**Empfehlung:** YAGEO MFR-25FRF52-47R (1% Metal Film, $0.10). Für 47Ω-Ausgangswiderstände ist 0.1% weder nötig noch sinnvoll — der Wert ist unkritisch (dient nur der HF-Entkopplung/Lastabschluss).

---

## 4. Gotchas & Praktische Hinweise für THT-Präzisionsbauteile (2026)

### 4.1 Verfügbarkeit

- **THT wird zunehmend Nische.** Die meisten neuen Designs sind SMD. THT-Precision-Widerstände sind aber dank Audio-/Messtechnik-Markt weiterhin gut verfügbar.
- **LCSC/JLCPCB:** Sehr eingeschränkte Auswahl bei THT-Precision. JLCPCB-Handbestückung von THT-Teilen kostet extra (~$0.02–$0.05/Lötstelle). Am günstigsten: THT-Teile selbst bestücken.
- **DigiKey/Mouser:** Beste Quelle für THT-Precision. Versand nach DE/EU ~$12–$20, aber für Einzelprojekte lohnend.

### 4.2 PCB-Footprint-Größen

| Bauteil | Körper (D×L) | Empfohlener Pitch | Footprint |
|---|---|---|---|
| 1/4W Axial-Widerstand | 2.4×6.3 mm | 7.62–10.16 mm | Standard THT 0207 |
| WIMA MKS2 100nF | 7.2×2.5×6.5 mm | 5.0 mm | Radial_P5.0mm |
| Elko 10µF (6.3mm) | Ø5×11 mm | 2.0–2.5 mm | Radial_D5.0mm_P2.5mm |
| Elko 100µF (10mm) | Ø6.3–8×11 mm | 2.5–3.5 mm | Radial_D6.3mm_P2.5mm |

### 4.3 Audio-Qualitäts-Hinweise

1. **0.1% Matching ist wichtiger als absolute Genauigkeit** — Bei Differenzverstärkern bestimmt das Widerstandsverhältnis die CMRR. Zwei Widerstände mit 10.005kΩ und 10.008kΩ sind perfekt, solange sie gleich sind.

2. **Tempco-Matching ebenfalls kritisch** — TE Neohm YR (±15 ppm/°C) hat den Vorteil, dass sich alle Widerstände bei Temperaturänderung ungefähr gleich verschieben → CMRR bleibt stabil.

3. **Kein Kohleschicht (Carbon Film) im Signalpfad** — Spannungskoeffizient erzeugt nichtlineare Verzerrung. Nur Metal Film verwenden.

4. **Film vs. Keramik für 100nF:** Für Audio kein Nachteil von Film. Im Gegenteil — Film hat kein Mikrofonie-Problem (X7R-Keramik kann bei Vibration Spannung erzeugen). WIMA MKS2 ist in Studio-Equipment Standard seit 40+ Jahren.

---

## 5. Einkaufsliste — Vorschlag

### Für Differenzverstärker (z.B. THAT1240-Ersatz mit LM4562)

| Menge | Bauteil | Teilenummer | Bezugsquelle | Stückpreis |
|---|---|---|---|---|
| 8× | 10kΩ 0.1% | **MFP-25BRD52-10K** (YAGEO) | DigiKey | $0.60 |
| 4× | 20kΩ 0.1% | **MFP-25BRD52-20K** (YAGEO) | DigiKey | $0.60 |
| 4× | 4.7kΩ 0.1% (wenn benötigt) | **MFP-25BRD52-4K70** (YAGEO) | DigiKey | $0.60 |
| 4× | 47Ω 1% | **MFR-25FRF52-47R** (YAGEO) | DigiKey | $0.10 |
| 8× | 100nF Film | **WIMA MKS2D031001A00JSSD** | Mouser/DigiKey | ~$0.40 |
| 4× | 10µF 50V Elko | Nichicon UKL1H100MDD | DigiKey/LCSC | ~$0.10 |
| 2× | 100µF 50V Elko | Nichicon UKL1H101MED | DigiKey/LCSC | ~$0.25 |
| | | | **Gesamt ca.:** | **~$14–$18** |

### Alternative: Premium-Setup (TE Neohm, bester TK)

| Menge | Bauteil | Teilenummer | Stückpreis |
|---|---|---|---|
| 8× | 10kΩ 0.1% ±15ppm | **YR1B10KCC** (TE) | $0.79 |
| 4× | 20kΩ 0.1% ±15ppm | YR1B20KCC (TE) | ~$0.79 |

Mehrkosten: ~$3–$5 für deutlich bessere Temperaturdrift.

---

## 6. Fazit

### ✅ Widerstände: Kein Problem

- 0.1% THT Axialwiderstände sind **gut verfügbar und bezahlbar** ($0.60–$0.80/Stk.)
- YAGEO MFP-25 ist die pragmatische Empfehlung (Preis/Verfügbarkeit)
- TE YR Neohm ist die Premium-Wahl (bester Tempco)
- Vishay CMF55 ist der Audiophile-Klassiker, aber bei LCSC schwer beschaffbar

### ⚠️ 100nF C0G in THT: Nicht machbar

- C0G-Keramik in THT existiert nur bis ~10nF
- **Film (WIMA MKS2) ist der korrekte Ersatz** und klanglich sogar bevorzugt
- Für Entkopplung ist der Verlustfaktor-Unterschied zu C0G irrelevant

### ✅ Elektrolytkondensatoren: Kein Engpass

- Massenware, trivial beschaffbar

### ✅ 47Ω Ausgangswiderstände: Trivial

- Standard 1% Metal Film, $0.10/Stk., überall verfügbar

### Bezugsquellen-Empfehlung für THT-DIY

1. **DigiKey/Mouser** für Präzisionswiderstände und WIMA-Kondensatoren
2. **LCSC/JLCPCB** nur für Standardteile (Elkos, 1%-Widerstände) — THT-Precision-Auswahl ist dort stark limitiert

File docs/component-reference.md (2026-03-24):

# Component Reference

[← Back to README](../README.md) | [Signal Chain](signal-chain.md) | [Schematic Rebuild Guide](schematic-rebuild-guide.md)

---

## Op-Amps: LM4562 (U2–U13)

12× Dual op-amp SOIC-8. Each LM4562 contains **Unit A** and **Unit B** (1 op-amp each).

| Ref | Unit A Function | Unit B Function | V+ on | V− on |
|-----|---|---|---|---|
| U2 | CH1 Diff Receiver | CH1 Gain Stage | /V+ | /V− |
| U3 | CH2 Diff Receiver | CH2 Gain Stage | /V+ | /V− |
| U4 | CH3 Diff Receiver | CH3 Gain Stage | /V+ | /V− |
| U5 | CH4 Diff Receiver | CH4 Gain Stage | /V+ | /V− |
| U6 | CH5 Diff Receiver | CH5 Gain Stage | /V+ | /V− |
| U7 | CH6 Diff Receiver | CH6 Gain Stage | /V+ | /V− |
| U8 | CH1 HOT Buffer | CH1 COLD Inverter | /V+ | /V− |
| U9 | CH2 HOT Buffer | CH2 COLD Inverter | /V+ | /V− |
| U10 | CH3 HOT Buffer | CH3 COLD Inverter | /V+ | /V− |
| U11 | CH4 HOT Buffer | CH4 COLD Inverter | /V+ | /V− |
| U12 | CH5 HOT Buffer | CH5 COLD Inverter | /V+ | /V− |
| U13 | CH6 HOT Buffer | CH6 COLD Inverter | /V+ | /V− |

**LM4562 SOIC-8 Pinout** (per TI datasheet):

```
        ┌───────────┐
OUT_A ──┤ 1       8 ├── V+
IN−_A ──┤ 2       7 ├── OUT_B
IN+_A ──┤ 3       6 ├── IN−_B
   V− ──┤ 4       5 ├── IN+_B
        └───────────┘
```

> Pin 5 = **IN+_B** (not IN-_B!) and Pin 6 = **IN-_B** — common point of confusion on the LM4562!

---

## Resistors (R)

### Diff Receiver Network (4 resistors per channel, 0.1% metal film)

| CH | Rin+ (GND→IN+_A) | Rg- (COLD→INV) | Rref- (GND→INV) | Rf (RX_OUT→INV) |
|----|---|---|---|---|
| 1 | R2 | R3 | R14 | R20 |
| 2 | R4 | R5 | R15 | R21 |
| 3 | R6 | R7 | R16 | R22 |
| 4 | R8 | R9 | R17 | R23 |
| 5 | R10 | R11 | R18 | R24 |
| 6 | R12 | R13 | R19 | R25 |

All: **10kΩ 0.1% metal film**

### Gain Network (per channel)

| CH | Rin (RX→SUMNODE) | Rf (GAIN_OUT→SUMNODE) | R_30k (SW Pos3) | R_15k (SW Pos2) | R_7.5k (SW Pos1) |
|----|---|---|---|---|---|
| 1 | R26 | R50 | R27 | R28 | R29 |
| 2 | R30 | R51 | R31 | R32 | R33 |
| 3 | R34 | R52 | R35 | R36 | R37 |
| 4 | R38 | R53 | R39 | R40 | R41 |
| 5 | R42 | R54 | R43 | R44 | R45 |
| 6 | R46 | R55 | R47 | R48 | R49 |

Rin and Rf: **10kΩ 0.1%**; Gain resistors: 30k / 15k / 7.5k (1%)

### Driver Stage (per channel)

| CH | Rin Inv (GAIN_OUT→GAIN_FB) | Rf Inv (OUT_DRIVE→GAIN_FB) | R_COLD 47Ω (BUF→COLD) | R_HOT 47Ω (DRIVE→HOT) |
|----|---|---|---|---|
| 1 | R64 | R70 | R58 | R76 |
| 2 | R65 | R71 | R59 | R77 |
| 3 | R66 | R72 | R60 | R78 |
| 4 | R67 | R73 | R61 | R79 |
| 5 | R68 | R74 | R62 | R80 |
| 6 | R69 | R75 | R63 | R81 |

### Zobel Network — Output Series Resistors (10Ω)

| CH | R_Zobel_HOT | R_Zobel_COLD |
|----|---|---|
| 1 | R82 | R88 |
| 2 | R83 | R89 |
| 3 | R84 | R90 |
| 4 | R85 | R91 |
| 5 | R86 | R92 |
| 6 | R87 | R93 |

### EMI Input Filter — Series Resistors (47Ω)

| CH | R_EMI_HOT | R_EMI_COLD |
|----|---|---|
| 1 | R94 | R95 |
| 2 | R96 | R97 |
| 3 | R98 | R99 |
| 4 | R100 | R101 |
| 5 | R102 | R103 |
| 6 | R104 | R105 |

### Other Resistors

| Ref | Value | Function | Connection |
|-----|---|---|---|
| R1 | 10kΩ | Remote RC filter | /REMOTE_IN → /REMOTE_FILT |
| R56 | 100kΩ | Pullup EN_CTRL | /V+ → /EN_CTRL |
| R57 | 100kΩ | Pulldown EN_CTRL | /EN_CTRL → GND |
| R106 | 10kΩ | Q1 gate charge R | /V+ → Net-(Q1-G) |
| R107 | 100kΩ | /MUTE pullup | /V+ → /MUTE |
| R108–R113 | 10kΩ each | Gate Rs Q2–Q7 | /MUTE → Net-(Qx-G) |

---

## Capacitors (C)

### DC Blocking (2.2µF C0G, 2 per channel = 12 total)

| CH | C_HOT | C_COLD |
|----|---|---|
| 1 | C62 | C63 |
| 2 | C64 | C65 |
| 3 | C66 | C67 |
| 4 | C68 | C69 |
| 5 | C70 | C71 |
| 6 | C72 | C73 |

### EMI HF Filter (100pF C0G, 2 per channel = 12 total)

| CH | C_HOT | C_COLD |
|----|---|---|
| 1 | C50 | C51 |
| 2 | C52 | C53 |
| 3 | C54 | C55 |
| 4 | C56 | C57 |
| 5 | C58 | C59 |
| 6 | C60 | C61 |

### Zobel Capacitors (100nF C0G, output filter)

| CH | C_Zobel_HOT | C_Zobel_COLD |
|----|---|---|
| 1 | C38 | C44 |
| 2 | C39 | C45 |
| 3 | C40 | C46 |
| 4 | C41 | C47 |
| 5 | C42 | C48 |
| 6 | C43 | C49 |

### Supply Bulk & Filter

| Ref | Value | Function | Net |
|-----|---|---|-----|
| C1 | 100nF C0G | Remote RC filter | /REMOTE_FILT → GND |
| C14 | 100nF C0G | +12V_RAW bypass | /+12V_RAW → GND |
| C15 | 100nF C0G | −12V_RAW bypass | /-12V_RAW → GND |
| C16 | 100µF/25V | +12V_RAW bulk | /+12V_RAW → GND |
| C17 | 100µF/25V | −12V_RAW bulk | /-12V_RAW → GND |
| C18 | 100nF C0G | /+12V bypass after FB1 | /+12V → GND |
| C19 | 100nF C0G | /-12V bypass after FB2 | /-12V → GND |
| C20 | 100µF | V+ board bulk | /V+ → GND |
| C21 | 100µF | V− board bulk | /V- → GND |
| C22 | 100nF C0G | U14 VOUT bypass | /V+ → GND |
| C23 | 100nF C0G | U15 NR pin | /NR_U15 → GND |
| C24 | 10µF X5R | U14 VOUT bulk | /V+ → GND |
| C25 | 10µF X5R | U15 VOUT bulk | /V- → GND |
| C74–C79 | 10µF X5R | V+/V− bulk driver ICs | alternating /V+ and /V- |
| C80 | 10µF | Q1 gate RC timing | Net-(Q1-G) → GND |
| C81 | 22nF C0G | U14 soft-start | /SS_U14 → GND |

---

## Diodes (D)

### ESD Protection — Signal Lines (24 + 1 = 25 diodes)

**D1 (SMBJ15CA):** Bidirectional TVS 15V at remote input. Pin1=/REMOTE_IN, Pin2=GND.

**D2–D25 (PESD5V0S1BL):** ESD protection on all signal inputs/outputs. A=GND, K=signal net.

Per-channel assignment:

| CH | D_HOT_RAW | D_COLD_RAW | D_OUT_HOT | D_OUT_COLD |
|----|---|---|---|---|
| 1 | D8 | D10 | D2 | D9 |
| 2 | D11 | D13 | D3 | D12 |
| 3 | D14 | D16 | D4 | D15 |
| 4 | D17 | D19 | D5 | D18 |
| 5 | D20 | D22 | D6 | D21 |
| 6 | D23 | D25 | D7 | D24 |

> D_HOT/COLD_RAW: at XLR input (before EMI filter)
> D_OUT_HOT/COLD: at output node (before Zobel, after 47Ω series R)

**PESD5V0S1BL Pinout (SOD-323):**

```
  GND ─── A │SOD-323│ K ─── Signal net
```

---

## Connectors (J)

| Ref | Value | Type | Function | Pins |
|-----|---|---|---|---|
| J1 | 24V DC | Barrel Jack | Power input | Pin1=/+24V_IN, Pin2=GND |
| J2 | REMOTE 3.5mm IN | KH-PJ-320EA-5P-SMT | Remote input (FreeDSP) | PinT=/REMOTE_IN, PinS=GND |
| J15 | REMOTE 3.5mm OUT | KH-PJ-320EA-5P-SMT | Remote passthrough | PinT=/REMOTE_IN, PinS=GND |
| J3 | XLR_IN_1 | XLR-F 3-pin | Input CH1 | Pin1=GND, Pin2=/CH1_HOT_RAW, Pin3=/CH1_COLD_RAW, PinG=GND |
| J4 | XLR_IN_2 | XLR-F 3-pin | Input CH2 | Pin1=GND, Pin2=/CH2_HOT_RAW, Pin3=/CH2_COLD_RAW, PinG=GND |
| J5 | XLR_IN_3 | XLR-F 3-pin | Input CH3 | Pin1=GND, Pin2=/CH3_HOT_RAW, Pin3=/CH3_COLD_RAW, PinG=GND |
| J6 | XLR_IN_4 | XLR-F 3-pin | Input CH4 | Pin1=GND, Pin2=/CH4_HOT_RAW, Pin3=/CH4_COLD_RAW, PinG=GND |
| J7 | XLR_IN_5 | XLR-F 3-pin | Input CH5 | Pin1=GND, Pin2=/CH5_HOT_RAW, Pin3=/CH5_COLD_RAW, PinG=GND |
| J8 | XLR_IN_6 | XLR-F 3-pin | Input CH6 | Pin1=GND, Pin2=/CH6_HOT_RAW, Pin3=/CH6_COLD_RAW, PinG=GND |
| J9 | XLR3_OUT | XLR-M 3-pin | Output CH1 | Pin1=GND, Pin2=/CH1_OUT_HOT, Pin3=/CH1_OUT_COLD |
| J10 | XLR3_OUT | XLR-M 3-pin | Output CH2 | Pin1=GND, Pin2=/CH2_OUT_HOT, Pin3=/CH2_OUT_COLD |
| J11 | XLR3_OUT | XLR-M 3-pin | Output CH3 | Pin1=GND, Pin2=/CH3_OUT_HOT, Pin3=/CH3_OUT_COLD |
| J12 | XLR3_OUT | XLR-M 3-pin | Output CH4 | Pin1=GND, Pin2=/CH4_OUT_HOT, Pin3=/CH4_OUT_COLD |
| J13 | XLR3_OUT | XLR-M 3-pin | Output CH5 | Pin1=GND, Pin2=/CH5_OUT_HOT, Pin3=/CH5_OUT_COLD |
| J14 | XLR3_OUT | XLR-M 3-pin | Output CH6 | Pin1=GND, Pin2=/CH6_OUT_HOT, Pin3=/CH6_OUT_COLD |

---

## Switches (SW)

| Ref | Value | Type | Function |
|-----|---|---|---|
| SW1 | ALWAYS/REMOTE | SW_SPDT | Operating mode EN_CTRL: Pin1=/+12V, Pin2=/EN_CTRL, Pin3=/REMOTE_FILT |
| SW2 | Gain CH1 | SW_DIP_x03 | Gain select CH1 (3-bit) |
| SW3 | Gain CH2 | SW_DIP_x03 | Gain select CH2 |
| SW4 | Gain CH3 | SW_DIP_x03 | Gain select CH3 |
| SW5 | Gain CH4 | SW_DIP_x03 | Gain select CH4 |
| SW6 | Gain CH5 | SW_DIP_x03 | Gain select CH5 |
| SW7 | Gain CH6 | SW_DIP_x03 | Gain select CH6 |

---

## MOSFETs (Q)

All BSS138, N-channel, SOT-23. **Pinout:** Pin 1 = Gate, Pin 2 = Source, Pin 3 = Drain

| Ref | Function | Gate | Source | Drain |
|-----|---|---|---|---|
| Q1 | Master mute MOSFET | Net-(Q1-G) via R106+C80 | GND | /MUTE |
| Q2 | Mute CH1 | Net-(Q2-G) via R108 | GND | /CH1_GAIN_OUT |
| Q3 | Mute CH2 | Net-(Q3-G) via R109 | GND | /CH2_GAIN_OUT |
| Q4 | Mute CH3 | Net-(Q4-G) via R110 | GND | /CH3_GAIN_OUT |
| Q5 | Mute CH4 | Net-(Q5-G) via R111 | GND | /CH4_GAIN_OUT |
| Q6 | Mute CH5 | Net-(Q6-G) via R112 | GND | /CH5_GAIN_OUT |
| Q7 | Mute CH6 | Net-(Q7-G) via R113 | GND | /CH6_GAIN_OUT |

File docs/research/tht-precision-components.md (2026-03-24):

# Through-Hole Precision Components — Research Report

**Project:** Aurora DSP ICEpower Booster
**Date:** 2026-03-12
**Purpose:** Sourcing research for THT precision resistors (0.1%) and capacitors for audio differential amplifier (DIY)

---

## Summary (TL;DR)

| Category | Recommendation | Price (1 pc) | Availability |
|---|---|---|---|
| **0.1% 10kΩ Resistor** | YAGEO MFP-25BRD52-10K | ~$0.60 | ✅ DigiKey 26k+ pcs |
| **0.1% 10kΩ (Alternative)** | TE YR1B10KCC (Neohm) | ~$0.79 | ✅ DigiKey 77k+ pcs |
| **0.1% 10kΩ (LCSC)** | Vishay CMF5510K000BEEB | ~$1.40 | ⚠️ LCSC 197 pcs |
| **100nF C0G THT** | ❌ Practically does not exist | — | ❌ |
| **100nF Film (substitute)** | WIMA MKS2D031001A00JSSD | ~$0.57 | ⚠️ LCSC 12 pcs |
| **10µF Electrolytic THT** | Nichicon/Panasonic standard | ~$0.10–0.30 | ✅ Mass available |
| **100µF Electrolytic THT** | Nichicon/Panasonic standard | ~$0.10–0.50 | ✅ Mass available |
| **47Ω 1% Resistor** | YAGEO MFR-25FRF52-47R | ~$0.10 | ✅ DigiKey 100k+ pcs |

**Key takeaway:** 0.1% THT resistors are well available and affordable ($0.60–$1.40). 100nF C0G in THT does not exist — use polyester film (WIMA MKS2) or SMD C0G on adapter.

---

## 1. Through-Hole 0.1% Precision Resistors (Axial)

### 1.1 Series Overview

| Series | Manufacturer | Tolerance | Tempco | Power | Size (D×L) | Price (1 pc) |
|---|---|---|---|---|---|---|
| **CMF55** | Vishay/Dale | 0.1% (B) | ±25 ppm/°C (E) | 500 mW | 2.3×6.1 mm | $0.29–$1.40 |
| **MFP-25** | YAGEO | 0.1% | ±25 ppm/°C | 250 mW | 2.4×6.3 mm | ~$0.60 |
| **RNF14** | Stackpole | 0.1% | ±25 ppm/°C | 250 mW | 2.35×6.35 mm | ~$0.62 |
| **YR (Neohm)** | TE Connectivity | 0.1% | **±15 ppm/°C** | 250 mW | 2.3×6.3 mm | ~$0.79 |
| **MRS25** | Vishay | 0.1% | ±25–50 ppm/°C | 250 mW | 2.3×6.3 mm | ~$0.50–$1.00 |

> **All form factors are standard 1/4W axial** — identical to cheap carbon film resistors. Fit standard PCBs with 2.54mm grid (pitch 7.6–10.2 mm typical).

### 1.2 Detailed Part Numbers & Availability

#### Vishay CMF55 (The Classic)

The CMF55 part number encodes all parameters:
`CMF55` `10K000` `B` `E` `EB`

- **B** = ±0.1% tolerance (C=0.25%, D=0.5%, F=1%)
- **E** = ±25 ppm/°C tempco (H=±50ppm, K=±100ppm)
- **EB** = Packaging/spec code

| Part Number | Value | Tol. | Tempco | LCSC Stock | LCSC Price | DigiKey/Mouser |
|---|---|---|---|---|---|---|
| **CMF5510K000BEEB** | 10kΩ | 0.1% | ±25ppm | **197 pcs** | **$1.40** (1+) / $0.80 (1k+) | Available |
| CMF5510K000BHEA | 10kΩ | 0.1% | ±50ppm | 0 (orderable) | $0.28 (1+) | — |
| CMF5510K000BEEA | 10kΩ | 0.1% | ±25ppm | 0 (orderable) | $0.29 (1+) | — |
| CMF5510K000BERE | 10kΩ | 0.1% | ±25ppm | 0 (orderable) | $0.40 (1+) | — |
| CMF5510K000BHBF | 10kΩ | 0.1% | ±50ppm | 0 (orderable) | $0.97 (1+) | — |

**Assessment CMF55:** Gold standard for audio precision. Problem: Very low LCSC stock for 0.1% variants. Large quantities must be ordered (MOQ often 200–1000 pcs for pre/new listings).

#### YAGEO MFP-25 (Best Availability at 0.1%)

| Part Number | Value | Tol. | Tempco | DigiKey Stock | DigiKey Price |
|---|---|---|---|---|---|
| **MFP-25BRD52-10K** | 10kΩ | 0.1% | ±25ppm | **26,676 pcs** | **$0.60** (1+) / $0.16 (5k+) |
| **MFP-25BRD52-20K** | 20kΩ | 0.1% | ±25ppm | High (available) | ~$0.60 |
| **MFP-25BRD52-4K70** | 4.7kΩ | 0.1% | ±25ppm | High (available) | ~$0.60 |
| **MFP-25BRD52-100R** | 100Ω | 0.1% | ±25ppm | **4,958 pcs** | **$0.60** (1+) |

**Assessment YAGEO MFP-25:** ⭐ **CLEAR RECOMMENDATION for DIY.** Excellent availability at DigiKey, affordable price, all relevant values available. Standard 1/4W axial form factor.

#### Stackpole RNF14 (Good Alternative)

| Part Number | Value | Tol. | Tempco | DigiKey Stock | DigiKey Price |
|---|---|---|---|---|---|
| **RNF14BTE10K0** | 10kΩ | 0.1% | ±25ppm | **20,424 pcs** | **$0.62** (1+) / $0.16 (5k+) |
| RNF14FTD10K0 | 10kΩ | 1% | ±100ppm | 144,666 pcs | $0.10 (1+) |

**Assessment Stackpole RNF14:** Solid alternative, slightly more expensive. Flame-retardant coating and safety certification — more than needed for DIY, but solid.

#### TE Connectivity YR (Neohm) — Premium

| Part Number | Value | Tol. | Tempco | DigiKey Stock | DigiKey Price |
|---|---|---|---|---|---|
| **YR1B10KCC** | 10kΩ | 0.1% | **±15ppm** | **77,291 pcs** | **$0.79** (1+) / $0.25 (1k+) |
| **YR1B20RCC** | 20Ω | 0.1% | ±15ppm | 33,065 pcs | $0.65 (1+) |
| **YR1B1K0CC** | 1kΩ | 0.1% | ±15ppm | 8,838 pcs | $0.83 (1+) |
| **YR1B1M0CC** | 1MΩ | 0.1% | ±15ppm | 11,306 pcs | $0.61 (1+) |

**Assessment TE YR Neohm:** ⭐ **Best tempco (±15 ppm/°C)** of all available series. When temperature stability is critical (e.g., gain-setting in feedback networks), this series is the best choice. Very good availability. Note: For 4.7kΩ, 20kΩ, 47Ω, availability must be checked individually — not all E96 values are stocked.

### 1.3 Price Comparison: 0.1% vs. 1% vs. 5%

| Tolerance | Example (10kΩ) | Price (1 pc) | Price (100+) |
|---|---|---|---|
| 5% Carbon Film | CF14JT10K0 | $0.10 | $0.008 |
| 1% Metal Film | MFR-25FRF52-10K (YAGEO) | $0.10 | $0.013 |
| **0.1% Metal Film** | **MFP-25BRD52-10K (YAGEO)** | **$0.60** | **$0.16** |
| 0.1% + ±15ppm Tempco | YR1B10KCC (TE Neohm) | $0.79 | $0.25 |

**Result:** 0.1% costs 6× more than 1%, but in absolute terms still very affordable ($0.60/pc). For a differential amplifier with 8–16 resistors, that's only ~$5–$13 extra cost.

### 1.4 Resistor Networks (SIP/DIP) — 0.1%

**Result: Practically unavailable.**

- Standard SIP/DIP networks (Bourns, CTS) are typically only available in 2% or 1%
- 0.1% networks exist as specialty parts (Vishay Bulk Metal Foil, e.g., NOMC series), but:
  - Extremely expensive ($10–$50+/pc)
  - Very limited value combinations
  - Long lead times

**Recommendation:** Use individual resistors. The advantage of networks (guaranteed matching) becomes largely irrelevant with 0.1% individual resistors — two 0.1% resistors from the same reel are typically matched within 0.02%.

> **Tip for best matching:** Order 10+ pieces of the same value (from tape & reel), measure with DMM, and form the best-matched pairs. With 0.1% nominal tolerance, you can typically achieve <0.01% matching.

---

## 2. Through-Hole Capacitors

### 2.1 100nF C0G/NP0 — Through-Hole

#### ❌ PRACTICALLY DOES NOT EXIST IN THT

**Why?**

- C0G/NP0 has a very low dielectric constant (~30 vs. ~3000 for X7R)
- 100nF in C0G therefore requires **large physical dimensions**
- Available as SMD only starting at **1206** (3.2×1.6 mm) — already large for SMD
- THT ceramic capacitors (disc type) with C0G only exist up to approx. **10nF** (10,000pF)
- Beyond that, THT ceramics are typically offered as X7R or Y5V

**Availability 100nF C0G at LCSC/DigiKey:**

- All 100nF C0G found are **SMD** (1206, 1210, 1812, 2220)
- TDK CGA series: 100nF C0G 50V starting at 1206, price $0.18–$0.49 (SMD)
- No single THT C0G capacitor with 100nF found

### 2.2 Alternatives for 100nF Decoupling (THT)

#### Option A: WIMA MKS2 — Polyester Film Capacitor ⭐ RECOMMENDATION

| Part Number | Value | Tol. | Voltage | Pitch | LCSC Stock | Price |
|---|---|---|---|---|---|---|
| **MKS2D031001A00JSSD** | 100nF | ±5% | 100V | 5 mm | **12 pcs** | **$0.57** |
| MKS2C031001A00KSSD | 100nF | ±10% | 63V | 5 mm | 18 pcs | $0.44 |
| MKS2G031001K00JSSD | 100nF | ±5% | 400V | 5 mm | 0 (orderable) | $0.57 |

**Properties:**

- Metallized polyester (PET) — **no microphonic effect** (unlike X7R ceramic)
- Size approx. 7.2×2.5×6.5 mm at 5mm pitch — compact enough for PCB
- Dissipation factor (tan δ) approx. 0.008–0.01 @ 1 kHz
- Not as good as C0G (tan δ < 0.001), but more than sufficient for decoupling
- **Audio standard** — used in studio equipment for decades

**Problem at LCSC:** Very low stock (12–18 pcs). Problematic for JLCPCB assembly. Better ordered from Mouser/DigiKey.

#### Option B: Epcos/TDK B32529 — Polyester Film

Similar to WIMA MKS2, often cheaper. Availability at LCSC also limited for THT variants.

#### Option C: WIMA MKP2 — Polypropylene (PP) — Premium Audio

- Polypropylene has the **lowest dissipation factor** of all film types (tan δ < 0.0005)
- Ideal for audio signal path (coupling capacitors)
- 100nF is available, but larger form factor than MKS2
- Higher price (~$1.00–$2.00)
- **Recommendation:** For decoupling, MKS2 (polyester) is sufficient. MKP2 (polypropylene) should only be used in the signal path.

#### Option D: SMD C0G on THT Adapter

If C0G is absolutely required:

- SMD C0G 100nF in 1206 on adapter PCB (1206-to-THT)
- Or: 100nF C0G 1206 soldered directly on the bottom side of the main PCB (dead-bug style)
- Pragmatic but not elegant

### 2.3 Recommended Decoupling (3 tiers, THT)

| Tier | Function | Type | Recommendation |
|---|---|---|---|
| **HF Decoupling** | Directly at IC | Ceramic or film | WIMA MKS2 100nF (5mm pitch) |
| **Local Decoupling** | Per supply island | Electrolytic or film | 10µF electrolytic (Nichicon UKL/Panasonic FC) |
| **Bulk** | At supply input | Electrolytic | 100µF+ electrolytic (Nichicon/Panasonic) |

> **Note:** For a DIY THT build, WIMA MKS2 100nF is the pragmatic solution. The dissipation factor difference to C0G (0.008 vs. 0.001) is completely irrelevant for decoupling — it's about providing charge, not signal fidelity. In the audio **signal** path (coupling capacitors), MKP (polypropylene) should be used.

### 2.4 Electrolytic Capacitors (THT) — Bulk Decoupling

| Value | Series | Price (LCSC/DigiKey) | Stock | Notes |
|---|---|---|---|---|
| 10µF 50V | Nichicon UKL, Panasonic FC | $0.05–$0.15 | ✅ Mass product | Low-ESR for audio |
| 10µF 50V | Nichicon KA (Audio) | $0.20–$0.50 | ✅ Available | Audio-grade, gold standard |
| 100µF 50V | Nichicon UKL, Panasonic FC | $0.10–$0.30 | ✅ Mass product | Standard bulk |
| 100µF 25V | Nichicon MUSE (KZ) | $0.50–$2.00 | ✅ DigiKey | Audio specialty, bipolar |
| 1000µF 50V | Nichicon/Panasonic | $0.30–$1.00 | ✅ Mass product | PSU bulk |

**Recommendation for audio:**

- **Nichicon KA** (MUSE Standard) or **Panasonic FC** for local decoupling
- For signal path (coupling): prefer **film capacitors**
- Electrolytic capacitors are **not a bottleneck** — mass available and cheap

---

## 3. 47Ω Output Series Resistors

### 3.1 Available Options

| Part Number | Series | Tol. | Tempco | Power | DigiKey Price | Stock |
|---|---|---|---|---|---|---|
| **MFR-25FRF52-47R** | YAGEO MFR | 1% | ±100ppm | 1/4W | **$0.10** | 100k+ |
| RNF14FTD47R0 | Stackpole RNF | 1% | ±100ppm | 1/4W | $0.10 | 100k+ |
| CF14JT47R0 | Stackpole CF | 5% | 0/-400ppm | 1/4W | $0.10 | 100k+ |

**Recommendation:** YAGEO MFR-25FRF52-47R (1% metal film, $0.10). For 47Ω output resistors, 0.1% is neither necessary nor sensible — the value is non-critical (serves only HF decoupling/load termination).

---

## 4. Gotchas & Practical Notes for THT Precision Components (2026)

### 4.1 Availability

- **THT is increasingly niche.** Most new designs are SMD. THT precision resistors remain well available thanks to the audio/test equipment market.
- **LCSC/JLCPCB:** Very limited selection for THT precision. JLCPCB hand assembly of THT parts costs extra (~$0.02–$0.05/solder joint). Most economical: assemble THT parts yourself.
- **DigiKey/Mouser:** Best source for THT precision. Shipping to DE/EU ~$12–$20, but worthwhile for individual projects.

### 4.2 PCB Footprint Sizes

| Component | Body (D×L) | Recommended Pitch | Footprint |
|---|---|---|---|
| 1/4W Axial Resistor | 2.4×6.3 mm | 7.62–10.16 mm | Standard THT 0207 |
| WIMA MKS2 100nF | 7.2×2.5×6.5 mm | 5.0 mm | Radial_P5.0mm |
| Electrolytic 10µF (6.3mm) | Ø5×11 mm | 2.0–2.5 mm | Radial_D5.0mm_P2.5mm |
| Electrolytic 100µF (10mm) | Ø6.3–8×11 mm | 2.5–3.5 mm | Radial_D6.3mm_P2.5mm |

### 4.3 Audio Quality Notes

1. **0.1% matching is more important than absolute accuracy** — In differential amplifiers, the resistor ratio determines CMRR. Two resistors at 10.005kΩ and 10.008kΩ are perfect, as long as they're equal.

2. **Tempco matching also critical** — TE Neohm YR (±15 ppm/°C) has the advantage that all resistors shift approximately equally with temperature changes → CMRR remains stable.

3. **No carbon film in the signal path** — Voltage coefficient causes nonlinear distortion. Use metal film only.

4. **Film vs. ceramic for 100nF:** No disadvantage of film for audio. On the contrary — film has no microphony problem (X7R ceramic can generate voltage under vibration). WIMA MKS2 has been standard in studio equipment for 40+ years.

---

## 5. Shopping List — Suggested

### For Differential Amplifier (e.g., THAT1240 replacement with LM4562)

| Qty | Component | Part Number | Source | Unit Price |
|-----|---|---|---|---|
| 8× | 10kΩ 0.1% | **MFP-25BRD52-10K** (YAGEO) | DigiKey | $0.60 |
| 4× | 20kΩ 0.1% | **MFP-25BRD52-20K** (YAGEO) | DigiKey | $0.60 |
| 4× | 4.7kΩ 0.1% (if needed) | **MFP-25BRD52-4K70** (YAGEO) | DigiKey | $0.60 |
| 4× | 47Ω 1% | **MFR-25FRF52-47R** (YAGEO) | DigiKey | $0.10 |
| 8× | 100nF Film | **WIMA MKS2D031001A00JSSD** | Mouser/DigiKey | ~$0.40 |
| 4× | 10µF 50V Electrolytic | Nichicon UKL1H100MDD | DigiKey/LCSC | ~$0.10 |
| 2× | 100µF 50V Electrolytic | Nichicon UKL1H101MED | DigiKey/LCSC | ~$0.25 |
| | | | **Total approx.:** | **~$14–$18** |

### Alternative: Premium Setup (TE Neohm, best tempco)

| Qty | Component | Part Number | Unit Price |
|-----|---|---|---|
| 8× | 10kΩ 0.1% ±15ppm | **YR1B10KCC** (TE) | $0.79 |
| 4× | 20kΩ 0.1% ±15ppm | YR1B20KCC (TE) | ~$0.79 |

Extra cost: ~$3–$5 for significantly better temperature drift.

---

## 6. Conclusion

### ✅ Resistors: No Problem

- 0.1% THT axial resistors are **well available and affordable** ($0.60–$0.80/pc)
- YAGEO MFP-25 is the pragmatic recommendation (price/availability)
- TE YR Neohm is the premium choice (best tempco)
- Vishay CMF55 is the audiophile classic, but hard to source at LCSC

### ⚠️ 100nF C0G in THT: Not Feasible

- C0G ceramic in THT only exists up to ~10nF
- **Film (WIMA MKS2) is the correct replacement** and sonically even preferred
- For decoupling, the dissipation factor difference to C0G is irrelevant

### ✅ Electrolytic Capacitors: No Bottleneck

- Mass product, trivially available

### ✅ 47Ω Output Resistors: Trivial

- Standard 1% metal film, $0.10/pc, available everywhere

### Recommended Suppliers for THT DIY

1. **DigiKey/Mouser** for precision resistors and WIMA capacitors
2. **LCSC/JLCPCB** only for standard parts (electrolytics, 1% resistors) — THT precision selection is severely limited there

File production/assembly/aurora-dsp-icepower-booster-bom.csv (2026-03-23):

Designator | Comment | Footprint | LCSC Part Number
C1-C15,C18,C19,C22,C23,C26-C49 | 100nF C0G | project:C_0805_2012Metric
C16,C17 | 100uF/25V | project:C_1210_3225Metric
C20,C21 | 100uF | project:C_1210_3225Metric
C24,C25,C74-C79 | 10uF X5R | project:C_0805_2012Metric
C50-C61 | 100pF C0G | project:C_0805_2012Metric
C62-C73 | 2.2uF C0G | project:C_1206_3216Metric
C80 | 10u | project:C_0805_2012Metric
C81 | 22nF C0G | project:C_0402_1005Metric
D1 | SMBJ15CA | project:D_SMB
D2-D25 | PESD5V0S1BL | project:D_SOD-323
FB1,FB2 | BLM18PG221 | project:L_0805_2012Metric
J1 | 24V DC | project:BarrelJack_Horizontal
J2 | REMOTE 3.5mm IN | aurora-dsp-icepower-booster:AUDIO-SMD_KH-PJ-320EA-5P-SMT | C5123132
J3 | XLR_IN_1 | project:Jack_XLR_Neutrik_NC3FBH2_Horizontal
J4 | XLR_IN_2 | project:Jack_XLR_Neutrik_NC3FBH2_Horizontal
J5 | XLR_IN_3 | project:Jack_XLR_Neutrik_NC3FBH2_Horizontal
J6 | XLR_IN_4 | project:Jack_XLR_Neutrik_NC3FBH2_Horizontal
J7 | XLR_IN_5 | project:Jack_XLR_Neutrik_NC3FBH2_Horizontal
J8 | XLR_IN_6 | project:Jack_XLR_Neutrik_NC3FBH2_Horizontal
J9-J14 | XLR3_OUT | project:Jack_XLR_Neutrik_NC3MBH_Horizontal
J15 | REMOTE 3.5mm OUT | aurora-dsp-icepower-booster:AUDIO-SMD_KH-PJ-320EA-5P-SMT | C5123132
Q1-Q7 | BSS138 | project:SOT-23
R1,R64-R75,R106,R108-R113 | 10k | project:R_0805_2012Metric
R2-R26,R30,R34,R38,R42,R46,R50-R55 | 10k 0.1% | project:R_0805_2012Metric
R27,R31,R35,R39,R43,R47 | 30k | project:R_0805_2012Metric
R28,R32,R36,R40,R44,R48 | 15k | project:R_0805_2012Metric
R29,R33,R37,R41,R45,R49 | 7.5k | project:R_0805_2012Metric
R56,R57,R107 | 100k | project:R_0805_2012Metric
R58-R63,R76-R81,R94-R105 | 47 | project:R_0805_2012Metric
R82-R93 | 10 | project:R_0805_2012Metric
SW1 | ALWAYS/REMOTE | project:SW_E-Switch_EG1224_SPDT_Angled
SW2 | Gain CH1 | project:SW_DIP_SPSTx03_Slide_Omron_A6S-310x_W8.9mm_P2.54mm
SW3 | Gain CH2 | project:SW_DIP_SPSTx03_Slide_Omron_A6S-310x_W8.9mm_P2.54mm
SW4 | Gain CH3 | project:SW_DIP_SPSTx03_Slide_Omron_A6S-310x_W8.9mm_P2.54mm
SW5 | Gain CH4 | project:SW_DIP_SPSTx03_Slide_Omron_A6S-310x_W8.9mm_P2.54mm
SW6 | Gain CH5 | project:SW_DIP_SPSTx03_Slide_Omron_A6S-310x_W8.9mm_P2.54mm
SW7 | Gain CH6 | project:SW_DIP_SPSTx03_Slide_Omron_A6S-310x_W8.9mm_P2.54mm
U1 | TEL5-2422 | project:TEL5_DUAL_TRP
U2-U13 | LM4562 | project:SOIC-8_3.9x4.9mm_P1.27mm
U14 | ADP7118ARDZ-11 | project:SOIC127P600X175-9N
U15 | ADP7182AUJZ-11 | project:SOT-23-5

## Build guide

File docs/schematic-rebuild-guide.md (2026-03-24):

# Schematic Rebuild Guide

[← Back to README](../README.md) | [Signal Chain](signal-chain.md) | [Component Reference](component-reference.md)

This guide describes the minimal connections needed to rebuild the schematic from scratch. **All 6 channels are identical** — build CH1 completely, then repeat for CH2–CH6 with the corresponding component numbers.

---

## Step 1 — Power Supply

```
1.  Place U1 (TEL5-2422, DIP-24)
    Pin 22, 23 → /+24V_IN (Barrel Jack J1 positive)
    Pin 14     → /+12V_RAW
    Pin 11     → /−12V_RAW
    Pin 2,3,9,16 → GND

2.  C14 (100nF C0G) + C16 (100µF) between /+12V_RAW and GND
    C15 (100nF C0G) + C17 (100µF) between /−12V_RAW and GND

3.  FB1 (Ferrite BLM18PG221) in series: /+12V_RAW → /+12V
    FB2 (Ferrite BLM18PG221) in series: /−12V_RAW → /−12V
    C18 (100nF C0G) between /+12V and GND
    C19 (100nF C0G) between /−12V and GND

4.  U14 (ADP7118ARDZ, SOIC-8+EP)
    Pin 7,8 (VIN) → /+12V
    Pin 1,2,3 (VOUT) → /V+
    Pin 4,9 (GND) → GND
    Pin 5 (EN) → /EN_CTRL
    Pin 6 (SS) → C81 (22nF C0G) → GND

5.  U15 (ADP7182AUJZ, SOT-23-5)
    Pin 2 (VIN) → /−12V
    Pin 5 (VOUT) → /V−
    Pin 1 (GND) → GND
    Pin 3 (EN) → /EN_CTRL
    Pin 4 (NR) → C23 (100nF C0G) → GND

6.  C22 (100nF C0G) + C24 (10µF X5R): /V+ → GND (U14 output)
    C25 (10µF X5R): /V− → GND (U15 output)
    C20 (100µF) /V+ → GND (board bulk)
    C21 (100µF) /V− → GND
```

## Step 2 — Enable & Muting

```
7.  R56 (100kΩ): /V+ → /EN_CTRL  (pullup)
    R57 (100kΩ): /EN_CTRL → GND  (pulldown)

8.  SW1 (SPDT):
    - Pin1 → /+12V (ALWAYS connection)
    - Pin2 (COM) → /EN_CTRL
    - Pin3 → /REMOTE_FILT (remote mode)
    - (ALWAYS: SW1 connects /+12V to /EN_CTRL → LDOs always active)

9.  J2 (3.5mm audio jack): PinT=/REMOTE_IN, PinS=GND
    D1 (SMBJ15CA): A=/REMOTE_IN, K=GND (bidirectional ESD)
    /REMOTE_IN → R1 (10kΩ) → /REMOTE_FILT
    /REMOTE_FILT → C1 (100nF C0G) → GND

10. Q1 (BSS138): Source=GND, Drain=/MUTE
    R106 (10kΩ): /V+ → Net-(Q1-G)
    C80 (10µF): Net-(Q1-G) → GND  → 100ms power-on delay
    R107 (100kΩ): /V+ → /MUTE  (pullup, MUTE active-low)

11. Q2–Q7 (BSS138): Source=GND, Drain=/CH#_GAIN_OUT
    R108–R113 (10kΩ each): /MUTE → Net-(Q#-G)
```

## Step 3 — Input Protection CH1 (repeat for CH2–CH6)

```
12. J3 (XLR Female, CH1):
    Pin 1 → GND
    Pin 2 → /CH1_HOT_RAW
    Pin 3 → /CH1_COLD_RAW
    PinG → GND

13. D8 (PESD5V0S1BL): A=GND, K=/CH1_HOT_RAW   ← ESD input HOT
    D10 (PESD5V0S1BL): A=GND, K=/CH1_COLD_RAW  ← ESD input COLD

14. R94 (47Ω): /CH1_HOT_RAW → /CH1_EMI_HOT         ← EMI series R HOT
    C50 (100pF C0G): /CH1_EMI_HOT → GND             ← HF low-pass (fc ≈ 33 MHz)
    C62 (2.2µF C0G): /CH1_EMI_HOT → /CH1_HOT_IN    ← DC blocking HOT

    R95 (47Ω): /CH1_COLD_RAW → /CH1_EMI_COLD        ← EMI series R COLD
    C51 (100pF C0G): /CH1_EMI_COLD → GND            ← HF low-pass
    C63 (2.2µF C0G): /CH1_EMI_COLD → /CH1_COLD_IN  ← DC blocking COLD
```

## Step 4 — Differential Receiver CH1 (U2 Unit A)

```
15. Standard differential amplifier (all 4 resistors 10kΩ 0.1%)

    Non-inverting input:
    /CH1_HOT_IN → directly → IN+_A (Pin 3 U2)
    R2 (10kΩ 0.1%): GND → IN+_A  ← Reference resistor (matching)

    Inverting input:
    R3 (10kΩ 0.1%): /CH1_COLD_IN → IN−_A (Pin 2 U2)
    R14 (10kΩ 0.1%): GND → IN−_A  ← Common-mode reference resistor
    R20 (10kΩ 0.1%): OUT_A (Pin 1) → IN−_A  ← Feedback

    U2 Pin 8 (V+) → /V+,  Pin 4 (V−) → /V−
    Decoupling: C2 (100nF C0G) Pin 8 → GND, C8 (100nF C0G) Pin 4 → GND

    OUT_A (Pin 1) = /CH1_RX_OUT
    Transfer function: V_out = (V_HOT − V_COLD) × 1
```

## Step 5 — Gain Stage CH1 (U2 Unit B)

```
16. Inverting summing amplifier (U2 Unit B)

    R26 (10kΩ 0.1%): /CH1_RX_OUT → /CH1_SUMNODE
    R50 (10kΩ 0.1%): /CH1_GAIN_OUT → /CH1_SUMNODE  ← Feedback
    /CH1_SUMNODE = IN−_B (Pin 6 U2) = inverting input
    IN+_B (Pin 5 U2) → GND

    SW2 (DIP 3-pos, CH1) — Gain resistors (connect SW output to SUMNODE):
      SW2-Pos1 (30kΩ):  R27 → /CH1_SUMNODE  → Gain ×1.33 (+2.5dB) alone
      SW2-Pos2 (15kΩ):  R28 → /CH1_SUMNODE  → Gain ×1.67 (+4.4dB) alone
      SW2-Pos3 (7.5kΩ): R29 → /CH1_SUMNODE  → Gain ×2.33 (+7.4dB) alone
    (Multiple positions can be combined, max. ×3.66 = +11.3dB with all ON)

    OUT_B (Pin 7 U2) = /CH1_GAIN_OUT
```

## Step 6 — Muting CH1

```
17. Q2 (BSS138):
    R108 (10kΩ): /MUTE → Gate (Pin 1)  ← Gate protection resistor
    Source (Pin 2) → GND
    Drain (Pin 3) → /CH1_GAIN_OUT
    (When /MUTE HIGH: Q2 conducts → /CH1_GAIN_OUT pulled to GND → silence)
```

## Step 7 — Balanced Driver CH1 (U8)

```
18. U8 Unit A (COLD buffer, non-inverting):
    IN+_A (Pin 3) ← /CH1_GAIN_OUT
    IN−_A (Pin 2) ← OUT_A (Pin 1)  ← Unity feedback (voltage follower)
    OUT_A (Pin 1) = /CH1_BUF_DRIVE

19. U8 Unit B (HOT inverter, inverting):
    IN+_B (Pin 5) = GND
    R64 (10kΩ): /CH1_GAIN_OUT → IN−_B (Pin 6) = /CH1_GAIN_FB  ← Input
    R70 (10kΩ): OUT_B (Pin 7) → IN−_B  ← Feedback (Gain = −1)
    OUT_B (Pin 7) = /CH1_OUT_DRIVE

    U8 Pin 8 (V+) → /V+, C26 (100nF) → GND
    U8 Pin 4 (V−) → /V−, C32 (100nF) → GND
```

## Step 8 — Output CH1

```
20. COLD signal path (from BUF_DRIVE → output XLR Pin 3):
    R58 (47Ω): /CH1_BUF_DRIVE → /CH1_OUT_COLD     ← Series resistor
    D9 (PESD5V0S1BL): A=GND, K=/CH1_OUT_COLD  ← ESD
    R88 (10Ω) + C44 (100nF C0G): Zobel /CH1_OUT_COLD → GND

21. HOT signal path (from OUT_DRIVE → output XLR Pin 2):
    R76 (47Ω): /CH1_OUT_DRIVE → /CH1_OUT_HOT      ← Series resistor
    D2 (PESD5V0S1BL): A=GND, K=/CH1_OUT_HOT   ← ESD
    R82 (10Ω) + C38 (100nF C0G): Zobel /CH1_OUT_HOT → GND

22. J9 (XLR Male, CH1):
    Pin 1 → GND
    Pin 2 → /CH1_OUT_HOT   (same net as D2 K and R82 Pin1)
    Pin 3 → /CH1_OUT_COLD  (same net as D9 K and R88 Pin1)
    Note: R82+C38 and R88+C44 are Zobel snubbers (parallel to GND)
          /CH1_OUT_PROT_HOT = net between R82 and C38 (internal only)
```

---

## Component Mapping — All 6 Channels

| Components | CH1 | CH2 | CH3 | CH4 | CH5 | CH6 |
|---|-----|-----|-----|-----|-----|-----|
| **XLR IN (J-Female)** | J3 | J4 | J5 | J6 | J7 | J8 |
| **XLR OUT (J-Male)** | J9 | J10 | J11 | J12 | J13 | J14 |
| **ESD Input HOT** | D8 | D11 | D14 | D17 | D20 | D23 |
| **ESD Input COLD** | D10 | D13 | D16 | D19 | D22 | D25 |
| **ESD Output HOT** | D2 | D3 | D4 | D5 | D6 | D7 |
| **ESD Output COLD** | D9 | D12 | D15 | D18 | D21 | D24 |
| **EMI R Input HOT** | R94 | R96 | R98 | R100 | R102 | R104 |
| **EMI R Input COLD** | R95 | R97 | R99 | R101 | R103 | R105 |
| **EMI C Input HOT** | C50 | C52 | C54 | C56 | C58 | C60 |
| **EMI C Input COLD** | C51 | C53 | C55 | C57 | C59 | C61 |
| **DC Block HOT** | C62 | C64 | C66 | C68 | C70 | C72 |
| **DC Block COLD** | C63 | C65 | C67 | C69 | C71 | C73 |
| **Diff/Gain IC** | U2 | U3 | U4 | U5 | U6 | U7 |
| **Driver IC** | U8 | U9 | U10 | U11 | U12 | U13 |
| **Muting MOSFET** | Q2 | Q3 | Q4 | Q5 | Q6 | Q7 |
| **Muting Gate R** | R108 | R109 | R110 | R111 | R112 | R113 |
| **DIP Switch** | SW2 | SW3 | SW4 | SW5 | SW6 | SW7 |
| **Rin+ (GND→IN+_A)** | R2 | R4 | R6 | R8 | R10 | R12 |
| **Rg- (COLD→IN-_A)** | R3 | R5 | R7 | R9 | R11 | R13 |
| **Rref- (GND→IN-_A)** | R14 | R15 | R16 | R17 | R18 | R19 |
| **Rf (OUT_A→IN-_A)** | R20 | R21 | R22 | R23 | R24 | R25 |
| **Rin_gain (RX→SUM)** | R26 | R30 | R34 | R38 | R42 | R46 |
| **Rf_gain (OUT→SUM)** | R50 | R51 | R52 | R53 | R54 | R55 |
| **R_30k (DIP SW pos1)** | R27 | R31 | R35 | R39 | R43 | R47 |
| **R_15k (DIP SW pos2)** | R28 | R32 | R36 | R40 | R44 | R48 |
| **R_7.5k (DIP SW pos3)** | R29 | R33 | R37 | R41 | R45 | R49 |
| **Rin_inv (Driver)** | R64 | R65 | R66 | R67 | R68 | R69 |
| **Rf_inv (Driver)** | R70 | R71 | R72 | R73 | R74 | R75 |
| **R_47Ω COLD (BUF→OUT)** | R58 | R59 | R60 | R61 | R62 | R63 |
| **R_47Ω HOT (DRV→OUT)** | R76 | R77 | R78 | R79 | R80 | R81 |
| **R_10Ω Zobel HOT** | R82 | R83 | R84 | R85 | R86 | R87 |
| **R_10Ω Zobel COLD** | R88 | R89 | R90 | R91 | R92 | R93 |
| **C_Zobel HOT (100nF)** | C38 | C39 | C40 | C41 | C42 | C43 |
| **C_Zobel COLD (100nF)** | C44 | C45 | C46 | C47 | C48 | C49 |
| **V+ Decoupling** | C2 | C3 | C4 | C5 | C6 | C7 |
| **V− Decoupling** | C8 | C9 | C10 | C11 | C12 | C13 |
| **V+ Driver Decoupling** | C26 | C27 | C28 | C29 | C30 | C31 |
| **V− Driver Decoupling** | C32 | C33 | C34 | C35 | C36 | C37 |

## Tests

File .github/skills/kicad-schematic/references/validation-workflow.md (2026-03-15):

# Validation Workflow Reference

## Dreistufige Validierung (nach JEDER Änderung)

### Stufe 1: Datei-Integrität
```python
# Klammer-Balance
depth = 0
for ch in content:
    if ch == '(': depth += 1
    elif ch == ')': depth -= 1
assert depth == 0

# Dateigröße plausibel (280-350KB für dieses Projekt)
import os
size = os.path.getsize(sch_file)
assert 280000 < size < 350000
```

### Stufe 2: kicad-cli Parser-Test
```bash
/opt/homebrew/bin/kicad-cli sch export netlist --output /tmp/test.net aurora-dsp-icepower-booster.kicad_sch
# Exit code 0 = Parser OK
# "Failed to load schematic" = lib_symbols Cache defekt
```

### Stufe 3: ERC Regression
```bash
/opt/homebrew/bin/kicad-cli sch erc --output /tmp/erc.rpt --severity-all aurora-dsp-icepower-booster.kicad_sch
# Parse: "ERC messages: TOTAL Errors ERRORS Warnings WARNINGS"
# Baseline: 115 Errors — DARF NICHT STEIGEN
```

## Netlist-Verbindungen prüfen

### Balanced-Paren Netlist-Parser
```python
def extract_nets(netlist_text):
    """Parst Netze aus KiCad-Netlist (multi-line Format)."""
    nets = {}
    i = 0
    while True:
        idx = netlist_text.find("(net (code", i)
        if idx == -1:
            break
        depth = 0
        start = idx
        for j in range(idx, len(netlist_text)):
            if netlist_text[j] == '(':
                depth += 1
            elif netlist_text[j] == ')':
                depth -= 1
                if depth == 0:
                    block = netlist_text[start:j+1]
                    name_m = re.search(r'\(name "?([^")\s]+)"?\)', block)
                    if name_m:
                        net_name = name_m.group(1)
                        nodes = re.findall(
                            r'\(node \(ref "?(\w+)"?\)\s*\(pin "?([^")\s]+)"?\)',
                            block
                        )
                        nets[net_name] = nodes
                    i = j + 1
                    break
        else:
            break
    return nets
```

### Erwartete Netz-Verbindungen (PSU/REMOTE)

```python
EXPECTED_NETS = {
    "/REMOTE_IN":   [("J14", "T"), ("D25", "1"), ("R105", "1")],
    "/REMOTE_FILT": [("C79", "1"), ("R105", "2"), ("SW7", "3")],
    "/EN_CTRL":     [("R79", "1"), ("R80", "1"), ("SW7", "2"), ("U14", "4"), ("U15", "3")],
    "/SS_U14":      [("C81", "1"), ("U14", "5")],
    "/NR_U15":      [("C82", "1"), ("U15", "4")],
    "/+24V_IN":     [("J13", "1"), ("U13", "1")],
    "/+12V":        [("U13", "24"), ("U14", "6"), ("SW7", "1")],
    "/-12V":        [("U13", "14"), ("U15", "2")],
    "/GND":         [("J14", "S"), ("D25", "2"), ("C79", "2"), ("J13", "2")],
}
```

## Signal-Vertauschungs-Check

Immer prüfen, dass Signale nicht versehentlich vertauscht sind:
```python
# J14.T (Tip/Signal) darf NICHT auf GND sein
assert ("J14", "T") not in gnd_nodes
# J14.S (Sleeve/GND) darf NICHT auf REMOTE_IN sein
assert ("J14", "S") not in remote_in_nodes
```

## Quality Gate Kategorien

| ID | Kategorie | Prüft |
|----|---|---|
| INT-1..3 | Integrität | Balance, kicad-cli Parse, Dateigröße |
| SYM-1..3 | Symbole | lib_id, Footprint, Value korrekt |
| NET-1..6 | Netze | Verbindungen, keine Vertauschung |
| ERC-1 | ERC | Baseline nicht überschritten |
| FP-1..2 | Footprints | Existenz, Pad-Namen |
| CACHE-1..2 | Cache | Sub-Symbol-Naming, Pin-Vollständigkeit |

## Automatisierung

Für wiederkehrende Validierung das quality_gate-Skript verwenden:
```bash
python3 quality_gate_psu_remote.py
# Ergebnis: N PASS, M FAIL, K WARN
```

Oder das generische Validierungsskript:
```bash
python3 .github/skills/kicad-schematic/scripts/validate_schematic.py
```

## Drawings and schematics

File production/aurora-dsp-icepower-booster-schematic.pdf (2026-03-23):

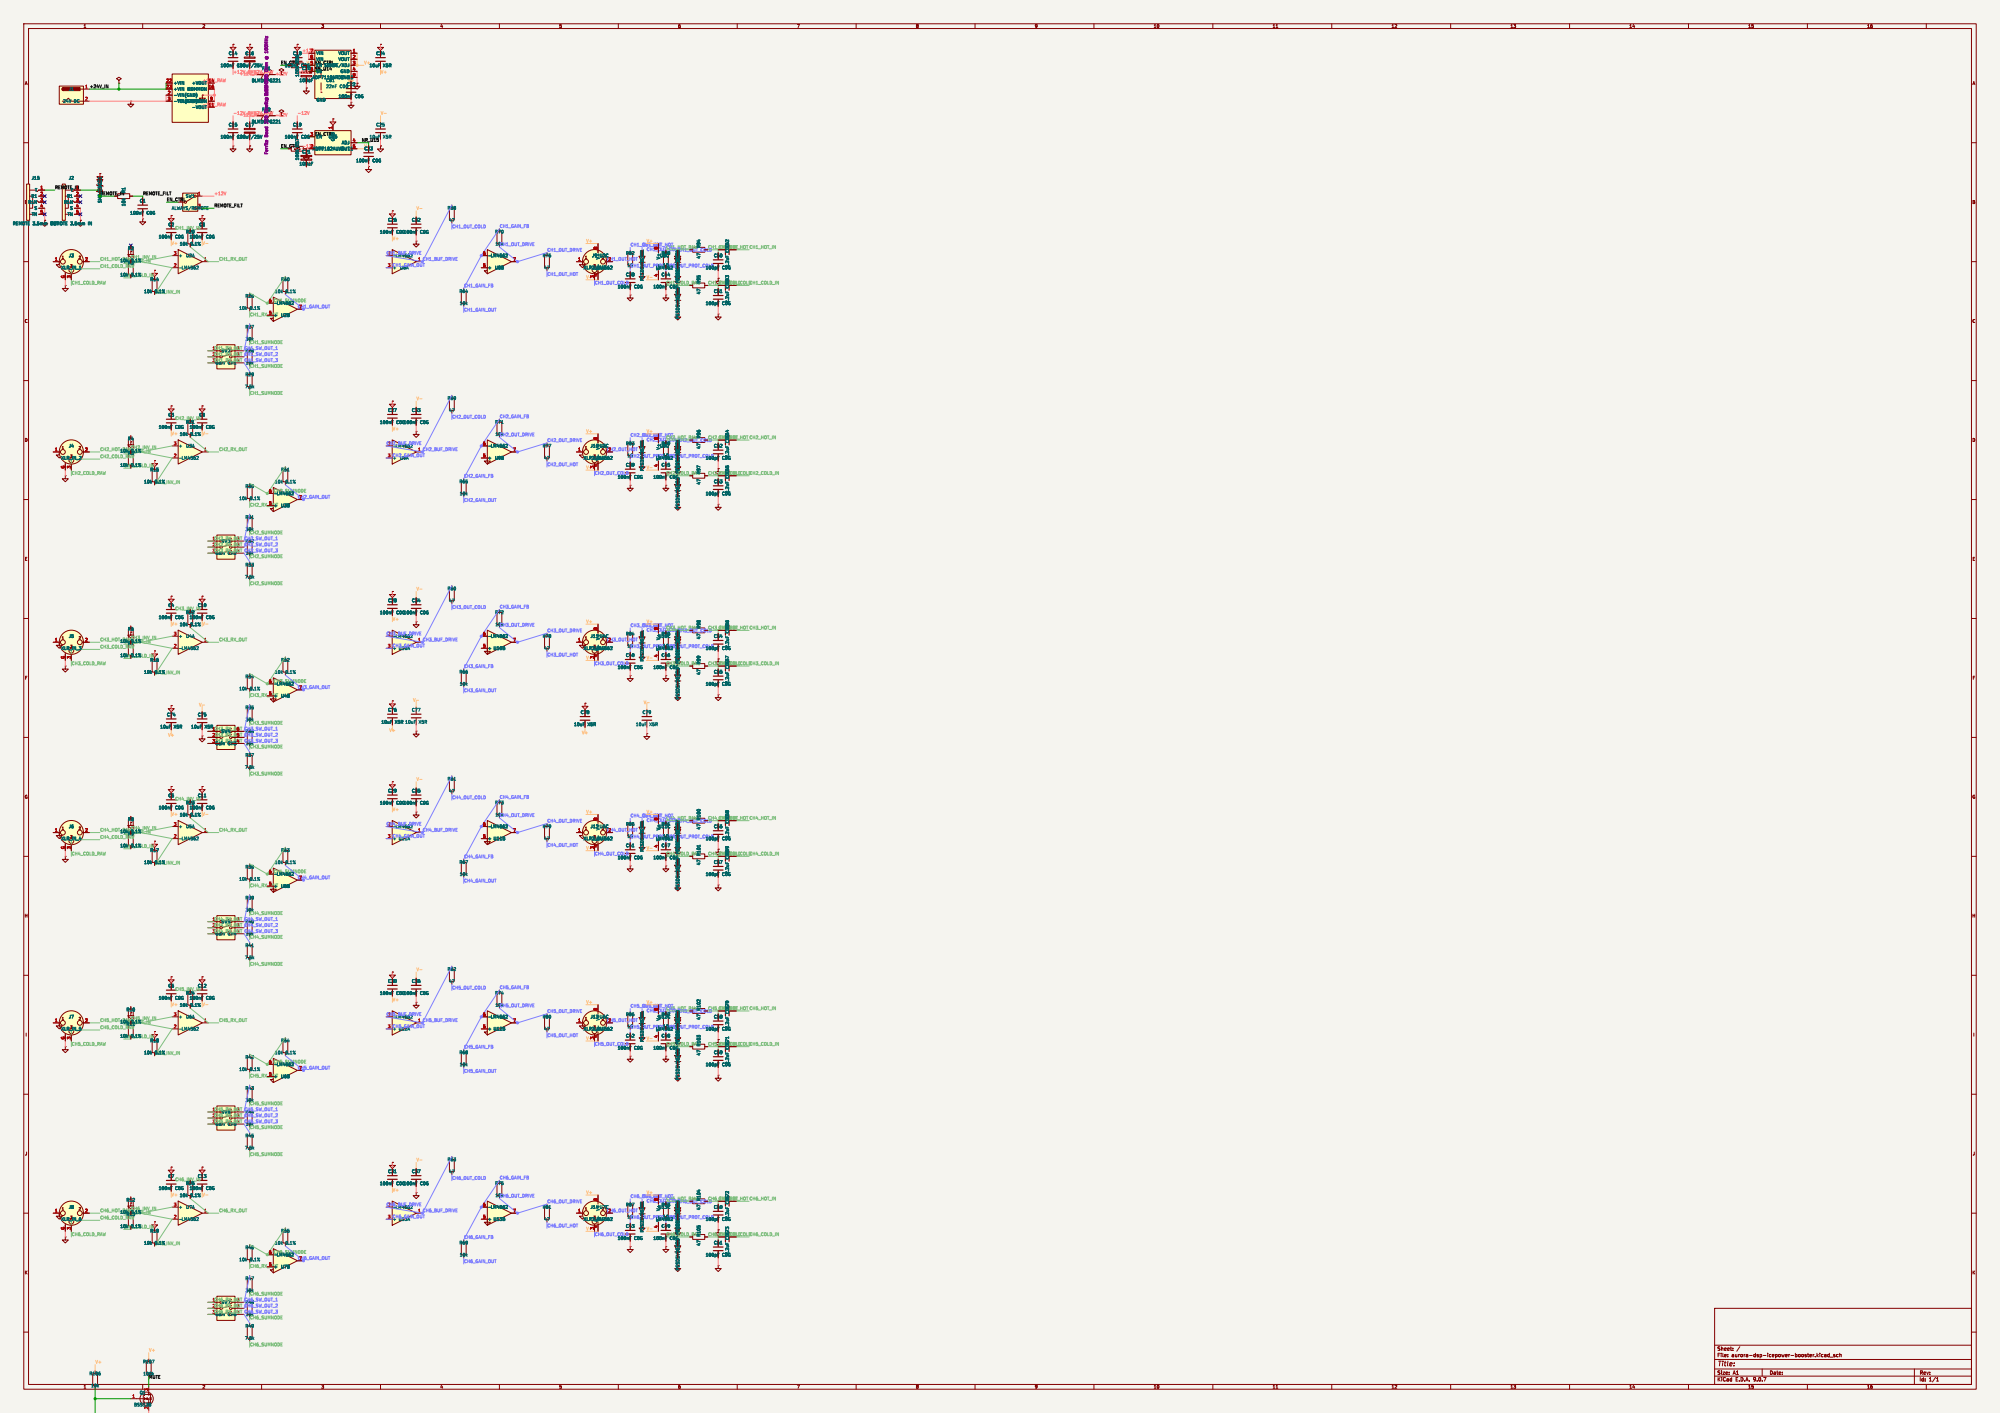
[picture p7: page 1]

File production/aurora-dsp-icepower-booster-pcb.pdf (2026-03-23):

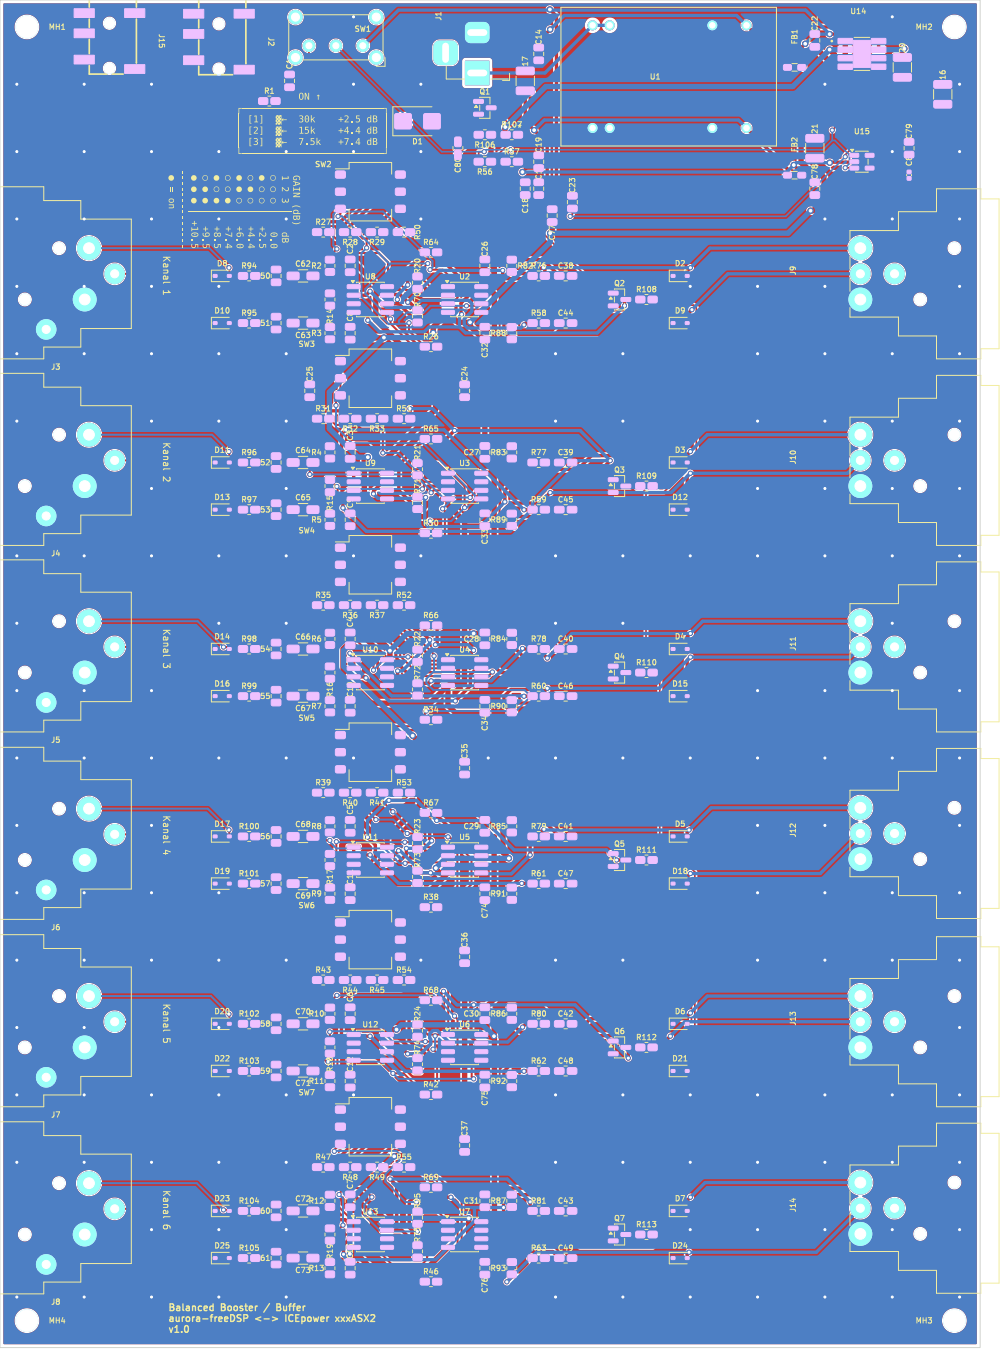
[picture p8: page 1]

Kanal 6 Balanced Booster / Buffer aurora-freeDSP <-> ICEpower xxxASX2

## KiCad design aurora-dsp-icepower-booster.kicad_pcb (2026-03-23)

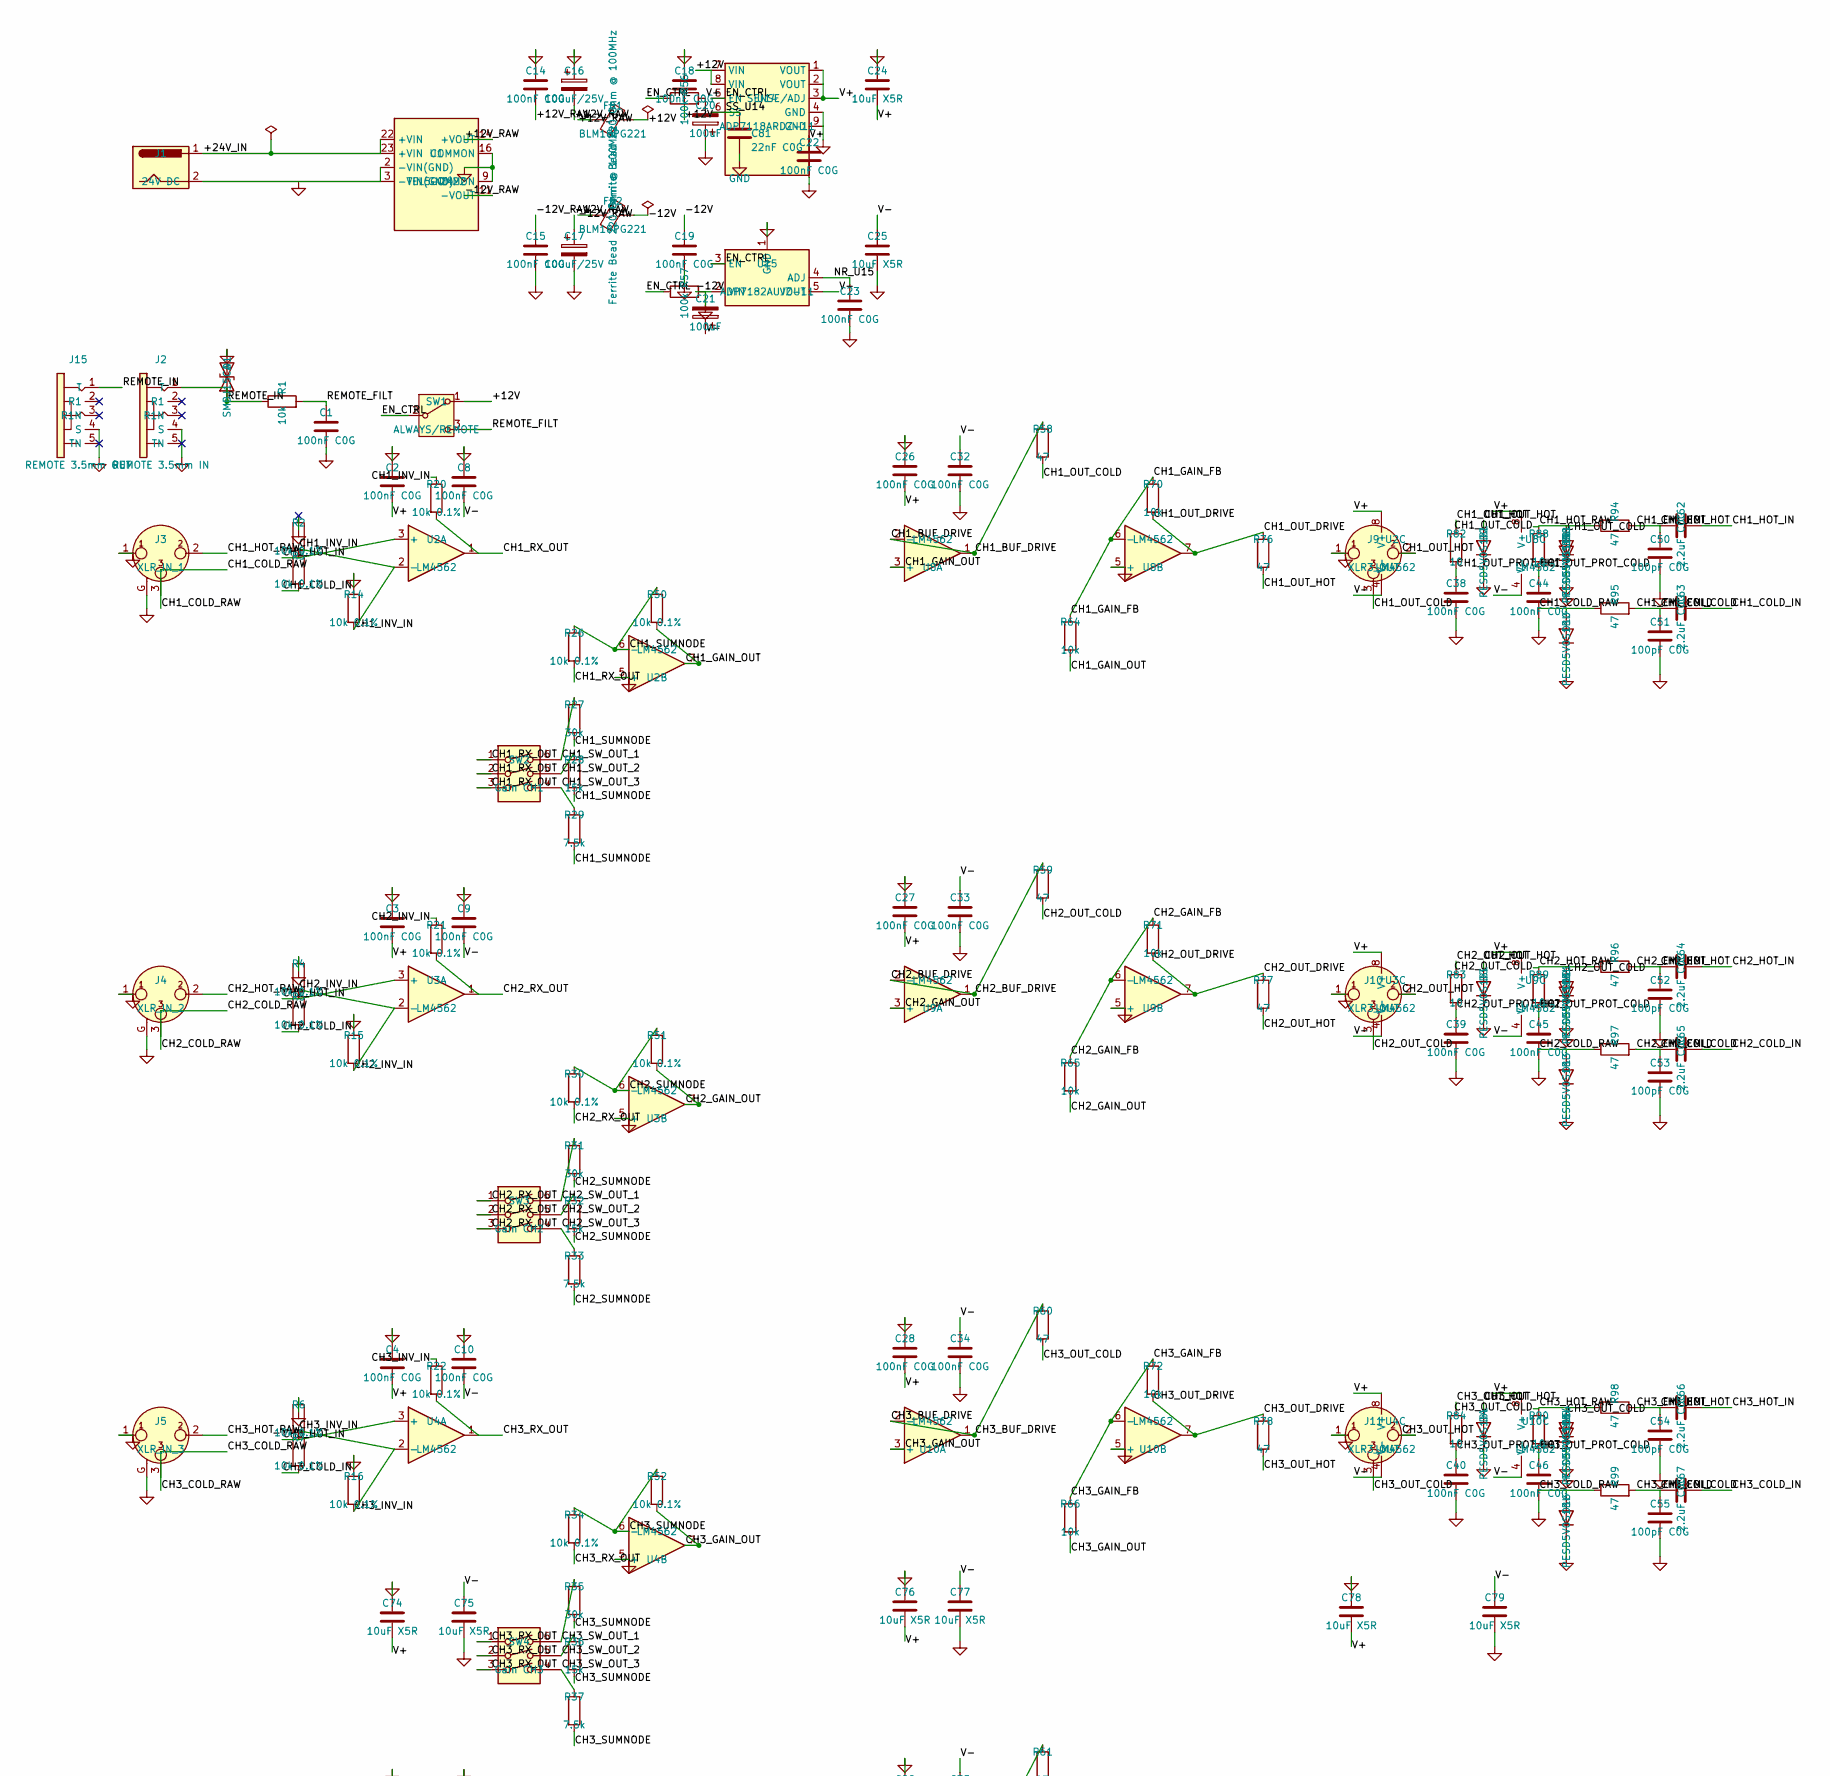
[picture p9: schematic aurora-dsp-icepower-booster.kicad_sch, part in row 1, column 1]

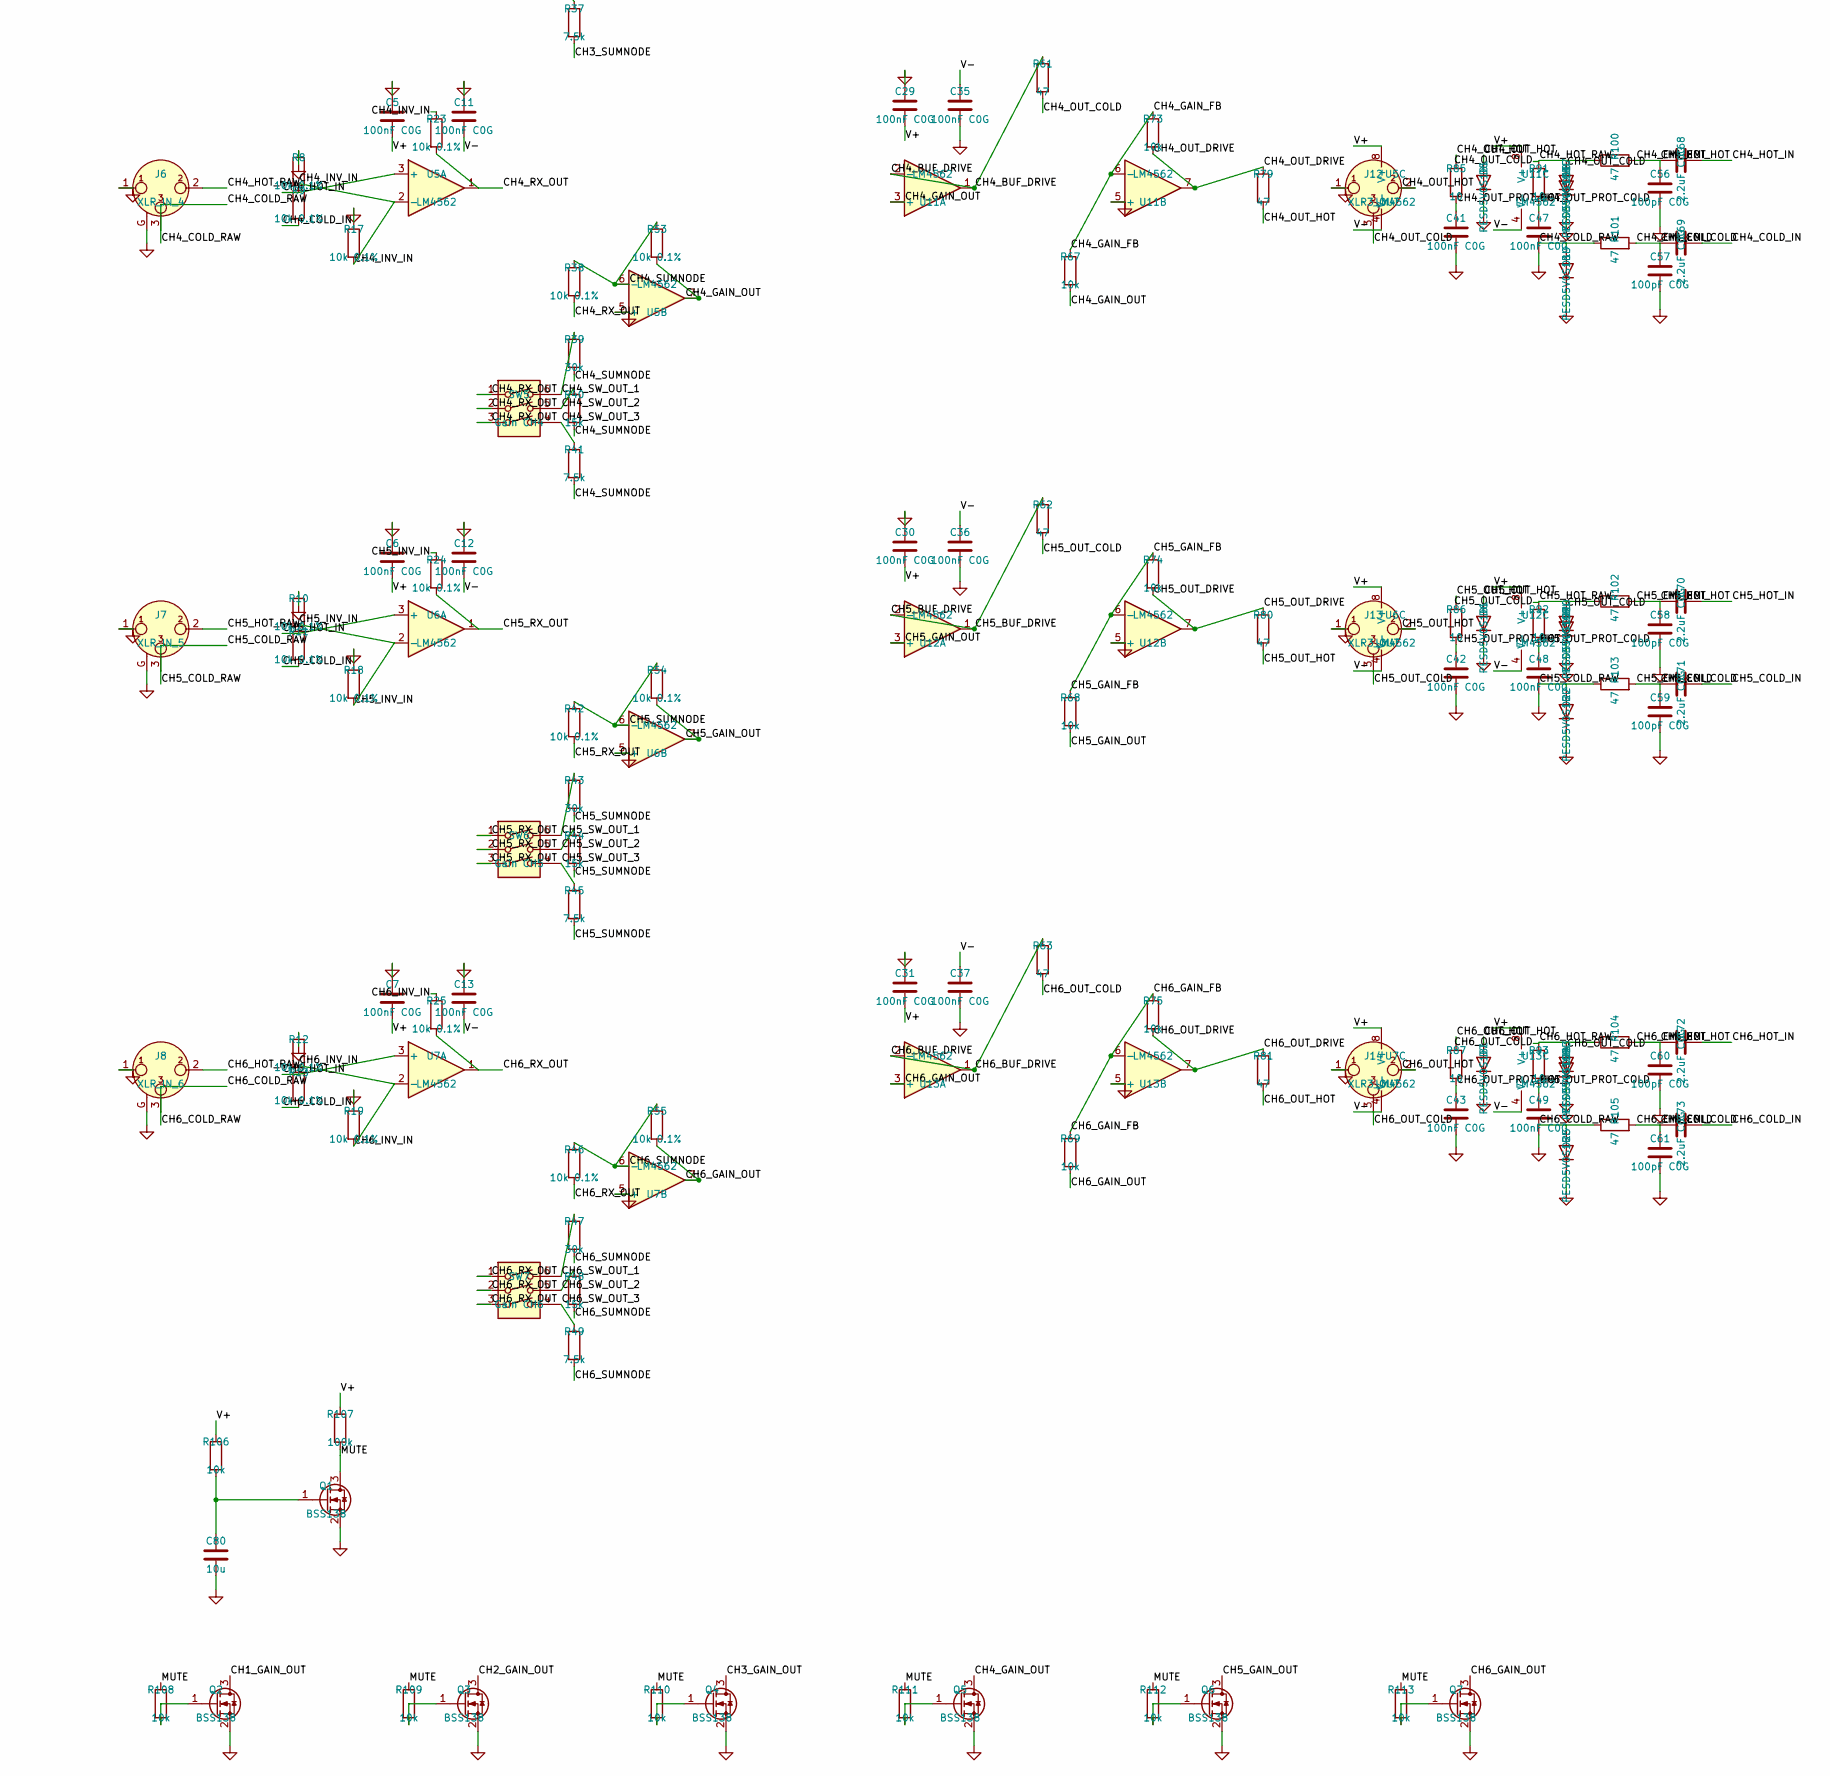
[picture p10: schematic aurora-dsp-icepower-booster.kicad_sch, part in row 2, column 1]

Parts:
C1, C2, C3, C4, C5, C6, C7, C8, C9, C10, C11, C12, C13, C14, C15, C18, C19, C22, C23, C26, C27, C28, C29, C30, C31, C32, C33, C34, C35, C36, C37, C38, C39, C40, C41, C42, C43, C44, C45, C46, C47, C48, C49: 100nF C0G; C_0805_2012Metric
C16, C17: 100uF/25V; C_1210_3225Metric
C20, C21: 100uF; C_1210_3225Metric
C24, C25, C74, C75, C76, C77, C78, C79: 10uF X5R; C_0805_2012Metric
C50, C51, C52, C53, C54, C55, C56, C57, C58, C59, C60, C61: 100pF C0G; C_0805_2012Metric
C62, C63, C64, C65, C66, C67, C68, C69, C70, C71, C72, C73: 2.2uF C0G; C_1206_3216Metric
C80: 10u; C_0805_2012Metric
C81: 22nF C0G; C_0402_1005Metric
D1: SMBJ15CA; D_SMB
D2, D3, D4, D5, D6, D7, D8, D9, D10, D11, D12, D13, D14, D15, D16, D17, D18, D19, D20, D21, D22, D23, D24, D25: PESD5V0S1BL; D_SOD-323
FB1, FB2: BLM18PG221; L_0805_2012Metric
J1: 24V DC; BarrelJack_Horizontal
J2: REMOTE 3.5mm IN; AUDIO-SMD_KH-PJ-320EA-5P-SMT; LCSC C5123132
J3: XLR_IN_1; Jack_XLR_Neutrik_NC3FBH2_Horizontal
J4: XLR_IN_2; Jack_XLR_Neutrik_NC3FBH2_Horizontal
J5: XLR_IN_3; Jack_XLR_Neutrik_NC3FBH2_Horizontal
J6: XLR_IN_4; Jack_XLR_Neutrik_NC3FBH2_Horizontal
J7: XLR_IN_5; Jack_XLR_Neutrik_NC3FBH2_Horizontal
J8: XLR_IN_6; Jack_XLR_Neutrik_NC3FBH2_Horizontal
J9, J10, J11, J12, J13, J14: XLR3_OUT; Jack_XLR_Neutrik_NC3MBH_Horizontal
J15: REMOTE 3.5mm OUT; AUDIO-SMD_KH-PJ-320EA-5P-SMT; LCSC C5123132
Q1, Q2, Q3, Q4, Q5, Q6, Q7: BSS138; SOT-23
R1, R64, R65, R66, R67, R68, R69, R70, R71, R72, R73, R74, R75, R106, R108, R109, R110, R111, R112, R113: 10k; R_0805_2012Metric
R2, R3, R4, R5, R6, R7, R8, R9, R10, R11, R12, R13, R14, R15, R16, R17, R18, R19, R20, R21, R22, R23, R24, R25, R26, R30, R34, R38, R42, R46, R50, R51, R52, R53, R54, R55: 10k 0.1%; R_0805_2012Metric
R27, R31, R35, R39, R43, R47: 30k; R_0805_2012Metric
R28, R32, R36, R40, R44, R48: 15k; R_0805_2012Metric
R29, R33, R37, R41, R45, R49: 7.5k; R_0805_2012Metric
R56, R57, R107: 100k; R_0805_2012Metric
R58, R59, R60, R61, R62, R63, R76, R77, R78, R79, R80, R81, R94, R95, R96, R97, R98, R99, R100, R101, R102, R103, R104, R105: 47; R_0805_2012Metric
R82, R83, R84, R85, R86, R87, R88, R89, R90, R91, R92, R93: 10; R_0805_2012Metric
SW1: ALWAYS/REMOTE; SW_E-Switch_EG1224_SPDT_Angled
SW2: Gain CH1; SW_DIP_SPSTx03_Slide_Omron_A6S-310x_W8.9mm_P2.54mm
SW3: Gain CH2; SW_DIP_SPSTx03_Slide_Omron_A6S-310x_W8.9mm_P2.54mm
SW4: Gain CH3; SW_DIP_SPSTx03_Slide_Omron_A6S-310x_W8.9mm_P2.54mm
SW5: Gain CH4; SW_DIP_SPSTx03_Slide_Omron_A6S-310x_W8.9mm_P2.54mm
SW6: Gain CH5; SW_DIP_SPSTx03_Slide_Omron_A6S-310x_W8.9mm_P2.54mm
SW7: Gain CH6; SW_DIP_SPSTx03_Slide_Omron_A6S-310x_W8.9mm_P2.54mm
U1: TEL5-2422; TEL5_DUAL_TRP
U2, U3, U4, U5, U6, U7, U8, U9, U10, U11, U12, U13: LM4562; SOIC-8_3.9x4.9mm_P1.27mm
U14: ADP7118ARDZ-11; SOIC127P600X175-9N
U15: ADP7182AUJZ-11; SOT-23-5

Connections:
/+12V: C18.2, FB1.2, SW1.1 (A), U14.7 (VIN), U14.8 (VIN)
/+12V_RAW: C14.2, C16.2, FB1.1, U1.14 (+VOUT)
/+24V_IN: J1.1, U1.22 (+VIN), U1.23 (+VIN)
/-12V: C19.1, FB2.2, U15.2 (VIN)
/-12V_RAW: C15.1, C17.1, FB2.1, U1.11 (-VOUT)
/CH1_BUF_DRIVE: R58.1, U8.1, U8.2 (-)
/CH1_COLD_IN: C63.2, R3.2
/CH1_COLD_RAW: D10.2 (A), J3.3, R95.1
/CH1_EMI_COLD: C51.1, C63.1, R95.2
/CH1_EMI_HOT: C50.1, C62.1, R94.2
/CH1_GAIN_FB: R64.1, R70.1, U8.6 (-)
/CH1_GAIN_OUT: Q2.3 (D), R50.2, R64.2, U2.7, U8.3 (+)
/CH1_HOT_IN: C62.2, R2.2, U2.3 (+)
/CH1_HOT_RAW: D8.2 (A), J3.2, R94.1
/CH1_INV_IN: R3.1, R14.2, R20.1, U2.2 (-)
/CH1_OUT_COLD: D9.2 (A), J9.3, R58.2, R88.1
/CH1_OUT_DRIVE: R70.2, R76.1, U8.7
/CH1_OUT_HOT: D2.2 (A), J9.2, R76.2, R82.1
/CH1_OUT_PROT_COLD: C44.1, R88.2
/CH1_OUT_PROT_HOT: C38.1, R82.2
/CH1_RX_OUT: R20.2, R26.2, SW2.1, SW2.2, SW2.3, U2.1
/CH1_SUMNODE: R26.1, R27.2, R28.2, R29.2, R50.1, U2.6 (-)
/CH1_SW_OUT_1: R27.1, SW2.6
/CH1_SW_OUT_2: R28.1, SW2.5
/CH1_SW_OUT_3: R29.1, SW2.4
/CH2_BUF_DRIVE: R59.1, U9.1, U9.2 (-)
/CH2_COLD_IN: C65.2, R5.2
/CH2_COLD_RAW: D13.2 (A), J4.3, R97.1
/CH2_EMI_COLD: C53.1, C65.1, R97.2
/CH2_EMI_HOT: C52.1, C64.1, R96.2
/CH2_GAIN_FB: R65.1, R71.1, U9.6 (-)
/CH2_GAIN_OUT: Q3.3 (D), R51.2, R65.2, U3.7, U9.3 (+)
/CH2_HOT_IN: C64.2, R4.2, U3.3 (+)
/CH2_HOT_RAW: D11.2 (A), J4.2, R96.1
/CH2_INV_IN: R5.1, R15.2, R21.1, U3.2 (-)
/CH2_OUT_COLD: D12.2 (A), J10.3, R59.2, R89.1
/CH2_OUT_DRIVE: R71.2, R77.1, U9.7
/CH2_OUT_HOT: D3.2 (A), J10.2, R77.2, R83.1
/CH2_OUT_PROT_COLD: C45.1, R89.2
/CH2_OUT_PROT_HOT: C39.1, R83.2
/CH2_RX_OUT: R21.2, R30.2, SW3.1, SW3.2, SW3.3, U3.1
/CH2_SUMNODE: R30.1, R31.2, R32.2, R33.2, R51.1, U3.6 (-)
/CH2_SW_OUT_1: R31.1, SW3.6
/CH2_SW_OUT_2: R32.1, SW3.5
/CH2_SW_OUT_3: R33.1, SW3.4
/CH3_BUF_DRIVE: R60.1, U10.1, U10.2 (-)
/CH3_COLD_IN: C67.2, R7.2
/CH3_COLD_RAW: D16.2 (A), J5.3, R99.1
/CH3_EMI_COLD: C55.1, C67.1, R99.2
/CH3_EMI_HOT: C54.1, C66.1, R98.2
/CH3_GAIN_FB: R66.1, R72.1, U10.6 (-)
/CH3_GAIN_OUT: Q4.3 (D), R52.2, R66.2, U4.7, U10.3 (+)
/CH3_HOT_IN: C66.2, R6.2, U4.3 (+)
/CH3_HOT_RAW: D14.2 (A), J5.2, R98.1
/CH3_INV_IN: R7.1, R16.2, R22.1, U4.2 (-)
/CH3_OUT_COLD: D15.2 (A), J11.3, R60.2, R90.1
/CH3_OUT_DRIVE: R72.2, R78.1, U10.7
/CH3_OUT_HOT: D4.2 (A), J11.2, R78.2, R84.1
/CH3_OUT_PROT_COLD: C46.1, R90.2
/CH3_OUT_PROT_HOT: C40.1, R84.2
/CH3_RX_OUT: R22.2, R34.2, SW4.1, SW4.2, SW4.3, U4.1
/CH3_SUMNODE: R34.1, R35.2, R36.2, R37.2, R52.1, U4.6 (-)
/CH3_SW_OUT_1: R35.1, SW4.6
/CH3_SW_OUT_2: R36.1, SW4.5
/CH3_SW_OUT_3: R37.1, SW4.4
/CH4_BUF_DRIVE: R61.1, U11.1, U11.2 (-)
/CH4_COLD_IN: C69.2, R9.2
/CH4_COLD_RAW: D19.2 (A), J6.3, R101.1
/CH4_EMI_COLD: C57.1, C69.1, R101.2
/CH4_EMI_HOT: C56.1, C68.1, R100.2
/CH4_GAIN_FB: R67.1, R73.1, U11.6 (-)
/CH4_GAIN_OUT: Q5.3 (D), R53.2, R67.2, U5.7, U11.3 (+)
/CH4_HOT_IN: C68.2, R8.2, U5.3 (+)
/CH4_HOT_RAW: D17.2 (A), J6.2, R100.1
/CH4_INV_IN: R9.1, R17.2, R23.1, U5.2 (-)
/CH4_OUT_COLD: D18.2 (A), J12.3, R61.2, R91.1
/CH4_OUT_DRIVE: R73.2, R79.1, U11.7
/CH4_OUT_HOT: D5.2 (A), J12.2, R79.2, R85.1
/CH4_OUT_PROT_COLD: C47.1, R91.2
/CH4_OUT_PROT_HOT: C41.1, R85.2
/CH4_RX_OUT: R23.2, R38.2, SW5.1, SW5.2, SW5.3, U5.1
/CH4_SUMNODE: R38.1, R39.2, R40.2, R41.2, R53.1, U5.6 (-)
/CH4_SW_OUT_1: R39.1, SW5.6
/CH4_SW_OUT_2: R40.1, SW5.5
/CH4_SW_OUT_3: R41.1, SW5.4
/CH5_BUF_DRIVE: R62.1, U12.1, U12.2 (-)
/CH5_COLD_IN: C71.2, R11.2
/CH5_COLD_RAW: D22.2 (A), J7.3, R103.1
/CH5_EMI_COLD: C59.1, C71.1, R103.2
/CH5_EMI_HOT: C58.1, C70.1, R102.2
/CH5_GAIN_FB: R68.1, R74.1, U12.6 (-)
/CH5_GAIN_OUT: Q6.3 (D), R54.2, R68.2, U6.7, U12.3 (+)
/CH5_HOT_IN: C70.2, R10.2, U6.3 (+)
/CH5_HOT_RAW: D20.2 (A), J7.2, R102.1
/CH5_INV_IN: R11.1, R18.2, R24.1, U6.2 (-)
/CH5_OUT_COLD: D21.2 (A), J13.3, R62.2, R92.1
/CH5_OUT_DRIVE: R74.2, R80.1, U12.7
/CH5_OUT_HOT: D6.2 (A), J13.2, R80.2, R86.1
/CH5_OUT_PROT_COLD: C48.1, R92.2
/CH5_OUT_PROT_HOT: C42.1, R86.2
/CH5_RX_OUT: R24.2, R42.2, SW6.1, SW6.2, SW6.3, U6.1
/CH5_SUMNODE: R42.1, R43.2, R44.2, R45.2, R54.1, U6.6 (-)
/CH5_SW_OUT_1: R43.1, SW6.6
/CH5_SW_OUT_2: R44.1, SW6.5
/CH5_SW_OUT_3: R45.1, SW6.4
/CH6_BUF_DRIVE: R63.1, U13.1, U13.2 (-)
/CH6_COLD_IN: C73.2, R13.2
/CH6_COLD_RAW: D25.2 (A), J8.3, R105.1
/CH6_EMI_COLD: C61.1, C73.1, R105.2
/CH6_EMI_HOT: C60.1, C72.1, R104.2
/CH6_GAIN_FB: R69.1, R75.1, U13.6 (-)
/CH6_GAIN_OUT: Q7.3 (D), R55.2, R69.2, U7.7, U13.3 (+)
/CH6_HOT_IN: C72.2, R12.2, U7.3 (+)
/CH6_HOT_RAW: D23.2 (A), J8.2, R104.1
/CH6_INV_IN: R13.1, R19.2, R25.1, U7.2 (-)
/CH6_OUT_COLD: D24.2 (A), J14.3, R63.2, R93.1
/CH6_OUT_DRIVE: R75.2, R81.1, U13.7
/CH6_OUT_HOT: D7.2 (A), J14.2, R81.2, R87.1
/CH6_OUT_PROT_COLD: C49.1, R93.2
/CH6_OUT_PROT_HOT: C43.1, R87.2
/CH6_RX_OUT: R25.2, R46.2, SW7.1, SW7.2, SW7.3, U7.1
/CH6_SUMNODE: R46.1, R47.2, R48.2, R49.2, R55.1, U7.6 (-)
/CH6_SW_OUT_1: R47.1, SW7.6
/CH6_SW_OUT_2: R48.1, SW7.5
/CH6_SW_OUT_3: R49.1, SW7.4
/EN_CTRL: R56.1, R57.1, SW1.2 (B), U14.5 (EN), U15.3 (EN)
/MUTE: Q1.3 (D), R107.2, R108.1, R109.1, R110.1, R111.1, R112.1, R113.1
/NR_U15: C23.1, U15.4 (ADJ)
/REMOTE_FILT: C1.1, R1.2, SW1.3 (C)
/REMOTE_IN: D1.1 (A1), J2.1 (T), J15.1 (T), R1.1
/SS_U14: C81.1, U14.6 (SS)
/V+: C2.2, C3.2, C4.2, C5.2, C6.2, C7.2, C20.2, C22.1, C24.2, C26.2, C27.2, C28.2, C29.2, C30.2, C31.2, C74.2, C76.2, C78.2, R56.2, R106.1, R107.1, U2.8 (V+), U3.8 (V+), U4.8 (V+), U5.8 (V+), U6.8 (V+), U7.8 (V+), U8.8 (V+), U9.8 (V+), U10.8 (V+), U11.8 (V+), U12.8 (V+), U13.8 (V+), U14.1 (VOUT), U14.2 (VOUT), U14.3 (SENSE/ADJ)
/V-: C8.2, C9.2, C10.2, C11.2, C12.2, C13.2, C21.1, C25.1, C32.1, C33.1, C34.1, C35.1, C36.1, C37.1, C75.1, C77.1, C79.1, U2.4 (V-), U3.4 (V-), U4.4 (V-), U5.4 (V-), U6.4 (V-), U7.4 (V-), U8.4 (V-), U9.4 (V-), U10.4 (V-), U11.4 (V-), U12.4 (V-), U13.4 (V-), U15.5 (VOUT)
GND: C1.2, C2.1, C3.1, C4.1, C5.1, C6.1, C7.1, C8.1, C9.1, C10.1, C11.1, C12.1, C13.1, C14.1, C15.2, C16.1, C17.2, C18.1, C19.2, C20.1, C21.2, C22.2, C23.2, C24.1, C25.2, C26.1, C27.1, C28.1, C29.1, C30.1, C31.1, C32.2, C33.2, C34.2, C35.2, C36.2, C37.2, C38.2, C39.2, C40.2, C41.2, C42.2, C43.2, C44.2, C45.2, C46.2, C47.2, C48.2, C49.2, C50.2, C51.2, C52.2, C53.2, C54.2, C55.2, C56.2, C57.2, C58.2, C59.2, C60.2, C61.2, C74.1, C75.2, C76.1, C77.2, C78.1, C79.2, C80.2, C81.2, D1.2 (A2), D2.1 (K), D3.1 (K), D4.1 (K), D5.1 (K), D6.1 (K), D7.1 (K), D8.1 (K), D9.1 (K), D10.1 (K), D11.1 (K), D12.1 (K), D13.1 (K), D14.1 (K), D15.1 (K), D16.1 (K), D17.1 (K), D18.1 (K), D19.1 (K), D20.1 (K), D21.1 (K), D22.1 (K), D23.1 (K), D24.1 (K), D25.1 (K), J1.2, J2.4 (S), J3.1, J3.G, J4.1, J4.G, J5.1, J5.G, J6.1, J6.G, J7.1, J7.G, J8.1, J8.G, J9.1, J10.1, J11.1, J12.1, J13.1, J14.1, J15.4 (S), Q1.2 (S), Q2.2 (S), Q3.2 (S), Q4.2 (S), Q5.2 (S), Q6.2 (S), Q7.2 (S), R2.1, R4.1, R6.1, R8.1, R10.1, R12.1, R14.1, R15.1, R16.1, R17.1, R18.1, R19.1, R57.2, U1.2 (-VIN(GND)), U1.3 (-VIN(GND)), U1.9 (COMMON), U1.16 (COMMON), U2.5 (+), U3.5 (+), U4.5 (+), U5.5 (+), U6.5 (+), U7.5 (+), U8.5 (+), U9.5 (+), U10.5 (+), U11.5 (+), U12.5 (+), U13.5 (+), U14.4 (GND), U14.9 (GND), U15.1 (GND)
unnamed: C80.1, Q1.1 (G), R106.2
unnamed: Q2.1 (G), R108.2
unnamed: Q3.1 (G), R109.2
unnamed: Q4.1 (G), R110.2
unnamed: Q5.1 (G), R111.2
unnamed: Q6.1 (G), R112.2
unnamed: Q7.1 (G), R113.2

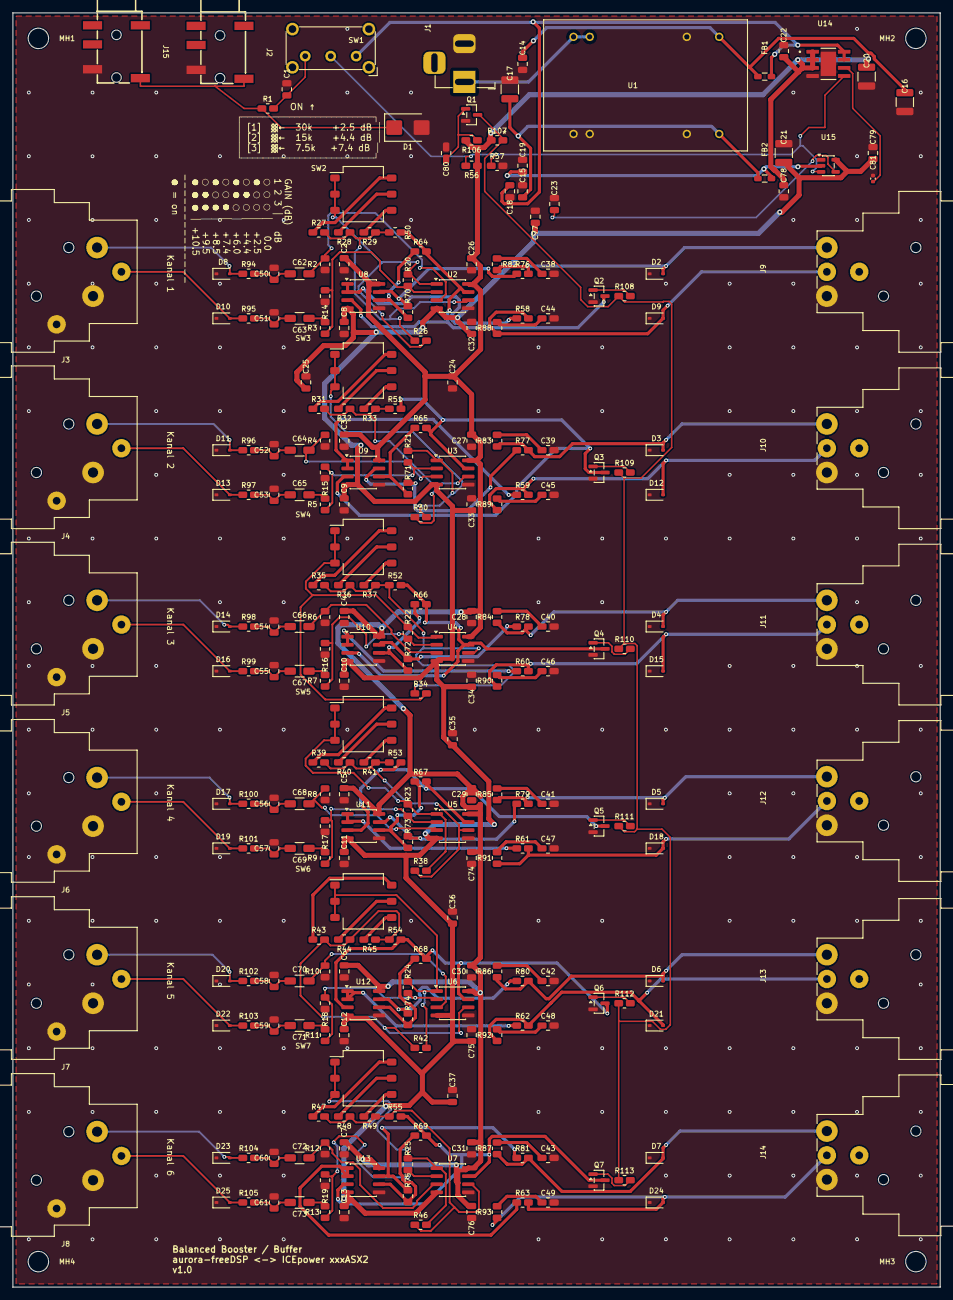
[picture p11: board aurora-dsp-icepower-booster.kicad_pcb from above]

Board: 2 copper layers, 145.6 x 200.0 mm, 269 parts (0 on the bottom side), 141 nets.

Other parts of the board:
MH1, MH2, MH3, MH4: MountingHole; MountingHole_3.2mm_M3

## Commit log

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2026-03-15 feat: PCB layout v8 — routing 67%, cleanup & documentation
    Schematic: 264 symbols, 0 ERC errors, all annotated
    PCB: 243 footprints, 200x200mm 2-layer, v8 routing (271/400, 67%)
    - Phase 0-3 complete (sync, board setup, placement)
    - Phase 4 routing v8: A* pathfinding, 144 GND vias, GND zone B.Cu
    - DRC: 269 violations (18 shorts, WIP), 399 unconnected (WIP)
    Added:
    - .gitignore for KiCad project
    - FINDINGS.md: quality gate & circuit analysis
    - datasheets/: ICEpower module datasheets, research docs
    - scripts/pcb/: placement, netclass, mounting hole scripts
    - scripts/reformat_sch.py, replicate_channels.py
    - .github/skills/kicad-schematic/: references & validation scripts
    Cleanup:
    - Removed 13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
    [aurora-dsp-icepower-booster.kicad_pcb, aurora-dsp-icepower-booster.kicad_sch]
2026-03-15 feat(pcb): reposition connectors for enclosure mounting
    19 components moved (15 primary + 4 secondary collision fixes).
    XLR IN (J1-J6): 180 deg, protrude 3.9mm left.
    XLR OUT (J7-J12): 90 deg CCW, protrude 7.8mm right.
    J13 (Power): barrel up, 6mm top protrusion.
    J14 (Remote): moved to top edge, 2.5mm protrusion.
    U13: moved down (Y=20), fully inside board.
    Secondary: SW7, C77, C78, C79 relocated to resolve collisions.
    All pads verified within board (0.3mm clearance).
    [aurora-dsp-icepower-booster.kicad_pcb]
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2026-03-15 PCB: Board auf 200x200mm, J13/SW7/J14 zentriert, U13+Caps verschoben
    - Board-Outline von 220x220mm zurück auf 200x200mm (R=2mm)
    - J13 (Barrel Jack) bei x=80, SW7 (Kippschalter) bei x=100, J14 bei x=120
    alle auf Oberkante zentriert mit Überstand für Gehäuse
    - U13 (TEL5-2422) von (70,20) nach (35,18) verschoben (frei von J13/SW7)
    - C25 nach (26,6), C77 nach (26,12) links neben U13
    - C35 nach (130.5,3), C81 nach (130.5,11) zwischen J14 und U14
    - C26 nach (107,11) unterhalb SW7
    - 61 verwaiste Tracks/Vias im PSU-Bereich entfernt
    - Keine Bauteil-Kollisionen, Shorts von 22 auf 18 reduziert
    [aurora-dsp-icepower-booster.kicad_pcb]
2026-03-15 PCB: Alle Tracks/Vias gelöscht + Speaker-Netzklasse hinzugefügt
    - 1043 Tracks + 194 Vias entfernt (clean slate für Routing-Neubeginn)
    - Speaker-Netzklasse: 1.5mm Track, 0.8mm Via, 0.3mm Clearance
    - CHx_EMI_HOT/COLD von Audio_Input auf Speaker umgestellt
    - DRC: 0 Shorts, 0 Dangles, 479 Unconnected (erwartungsgemäß)
    [aurora-dsp-icepower-booster.kicad_pcb]
2026-03-15 PCB: V+/V- Power Bus Routing (B.Cu Trunks x=67/69/117/119, F.Cu Stubs, 104 Tracks + 39 Vias, 0 Shorts)
    [aurora-dsp-icepower-booster.kicad_pcb]
2026-03-15 PCB: +12V/-12V/+24V_IN Routing (39 Tracks + 6 Vias, B.Cu Bridges, 0 Shorts)
    [aurora-dsp-icepower-booster.kicad_pcb]
2026-03-15 Signal routing v13c: 247 safe stubs, 70 shorts, 32 crossings, 165 signal gaps remaining
    - v6 base: pad-avoidance shifting + B.Cu jumpers at crossings
    - Two-pass: route all nets first, then fix gaps with safe F.Cu stubs
    - Safe stubs: only placed if no pad collision AND no track crossing
    - 429 gaps detected, 247 safely fixed, 182 skipped (need manual routing)
    - GND unconnected (132) will be fixed by copper pour
    - Remaining 165 signal gaps for manual completion in KiCad
    [aurora-dsp-icepower-booster.kicad_pcb]
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2026-03-15 Phase 2: 0 shorts, 0 crossings (54 tracks + 13 vias entfernt)
    [aurora-dsp-icepower-booster.kicad_pcb]
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2026-03-15 Phase 5b: GND copper pour + 112 GND vias, 0 errors, 129 unconnected
    [aurora-dsp-icepower-booster.kicad_pcb]
2026-03-15 Phase 5c: Signal routing iterativ, 0 errors, 118 unconnected (2 GND + 116 Signal)
    [aurora-dsp-icepower-booster.kicad_pcb]
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2026-03-16 Phase 6c: 100 GND Guard-Traces beidseitig um Audio-Input-Traces, 0 DRC errors
    - 48 parallele GND-Traces auf F.Cu neben Audio-Eingangssignalen
    - 52 Via-to-Via-Segmente verbinden Stitching-Vias entlang Guards
    - Strikte Kollisionsprüfung gegen alle Nicht-GND-Geometrie
    - GND tracks auf F.Cu: 112 → 212
    - F.Cu total: 912 → 1012 Tracks
    [aurora-dsp-icepower-booster.kicad_pcb]
2026-03-16 Phase 6d: Guard-Trace-Enden mit GND-Vias verbunden, DRC Cleanup
    - 73 dangling Guard-Trace-Enden mit nahen GND-Vias verbunden
    - track_dangling: 83 → 49, via_dangling: 97 → 80
    - Unconnected: 150 → 132
    - F.Cu tracks: 1012 → 1085
    - 0 DRC errors, 199 warnings (nur kosmetisch)
    [aurora-dsp-icepower-booster.kicad_pcb]
2026-03-16 Phase 7b: Track widths corrected to netclass targets
    - 242 Audio_Input tracks: 0.25mm → 0.30mm
    - 250 Audio_Output tracks: 0.25mm → 0.50mm
    - 285 Power/GND tracks: 0.25mm → 0.50mm
    - Verification: 0 tracks below target
    [aurora-dsp-icepower-booster.kicad_pcb]
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2026-03-16 Phase 7f: 90° corners chamfered to 45°, silkscreen verified
    - 414 of 458+114 90° corners replaced with 45° chamfers
    - 87 remaining corners too short to chamfer (< 2× track width)
    - Silkscreen text sizes already met JLCPCB minimums
    - Board: 1908 tracks, 659 vias
    [aurora-dsp-icepower-booster.kicad_pcb]
2026-03-16 Fix 6 SUMNODE label_multiple_wires ERC warnings
    - Move 12 SUMNODE labels above next resistor pin1 (avoid wire pass-through)
    - Shorten 12 vertical wires to match new label positions
    - Remove 6 unnecessary junctions
    - ERC: 805 → 799 violations (0 errors, 799 off-grid warnings)
    - Netlist: identical (125 nets, 603 nodes, all SUMNODE nets verified)
    [aurora-dsp-icepower-booster.kicad_sch]
2026-03-16 feat(api): ✨ add new endpoint for user authentication
    * Added input validation and error handling for improved security.
    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
    [aurora-dsp-icepower-booster.kicad_sch]
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2026-03-16 fix(sch): connect 6 ESD diode pairs — split all mid-wire pins into segments
    Each diode pair (D8/D9, D11/D12, D14/D15, D17/D18, D20/D21, D23/D24)
    had three mid-wire pin issues per pair:
    1. Internal wire spanning all 4 pins → split into 3 segments
    2. Top label wire (CHn_OUT_COLD → D_lower.A) passing through D_upper.A
    → split into 2 segments at D_upper.A
    3. Bottom GND wire (D_upper.K → GND) passing through D_lower.K
    → split into 2 segments at D_lower.K
    KiCad eeschema only connects pins at wire ENDPOINTS, not mid-wire.
    Total: 6 original wires → 18 segments, 12 label wires → 24 segments.
    Verified: kicad-cli ERC = 0 errors.
    [aurora-dsp-icepower-booster.kicad_sch]
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2026-03-17 FB1/FB2: Symbol von Device:L auf Device:FerriteBead geändert
    - lib_symbols Cache: Exakte Kopie aus KiCad System-Library
    - lib_id beider Instanzen aktualisiert
    - Footprint und Value bleiben: L_0805_2012Metric / BLM18PG221
    - ERC: lib_symbol_mismatch für FB1/FB2 behoben (913→911 Warnungen)
    [aurora-dsp-icepower-booster.kicad_sch]
2026-03-17 PCB: 26 Footprints + 10 Netze + Netzklassen + GND-Via-Stitching
    Phase 1: Schematic-to-PCB Sync (Text-Manipulation)
    - 26 fehlende Footprints hinzugefügt: C27-C34, C80, FB1, FB2, Q1-Q7, R106-R113
    - 10 neue Netze: +12V_RAW, -12V_RAW, MUTE, Net-(Q1-G) bis Net-(Q7-G)
    - Net-ID-Remapping: pcbnew-generierte Blöcke auf originale PCB-IDs korrigiert
    - Bibliotheks-Präfix: Vollständige Lib:Footprint-Namen (KiCad 9 Format)
    Phase 2: Bauteil-Platzierung
    - Alle 26 Bauteile auf 1.27mm-Raster platziert
    - FB1/FB2 bei U14/U15 (Versorgungsfilter)
    - Q2-Q7 pro Kanal verteilt (Muting-Schaltung)
    - R108-R113 neben zugehörigen MOSFETs
    Phase 3: Netzklassen-Konfiguration
    - 3 neue Patterns: +12V_RAW, -12V_RAW, +24V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
    [aurora-dsp-icepower-booster.kicad_pcb]
2026-03-17 PCB: MCP-Routing entfernt + Platzierung korrigiert (sauberes Board)
    Routing-Cleanup:
    - 1908 Trace-Segmente entfernt (fehlerhaftes MCP-Routing)
    - 291 Nicht-GND-Vias entfernt
    - 875 Teardrop-Zonen entfernt (orphaned)
    - 500 GND-Vias + 5 regulaere Zonen behalten
    Platzierungskorrektur:
    - C27-C34 verschoben nach (142, 33-43mm) nah an U14/U15
    - R106/R107 nach (149.86, 17-21mm) weg von U15
    - Q1/C80 nach (153.67, 17-20mm) weg von C53/C38
    - Alle neuen Bauteile auf 1.27mm-Raster
    DRC Baseline: 330 violations (199 via_dangling, 40 holes_co_located,
    27 silk_edge), 2 vorbestehende Shorts, 0 Courtyard-Overlaps der
    neuen Bauteile, 430 unconnected (alle noch zu routen)
    [aurora-dsp-icepower-booster.kicad_pcb]
2026-03-17 PCB: GND-Via cleanup, F.Cu zone, courtyard fixes
    - 30 problematische GND-Vias entfernt (holes_co_located, hole_clearance, hole_to_hole)
    - F.Cu GND-Zone hinzugefuegt (Board-weite Massflaeche)
    - B.Cu GND-Zone mit Fill-Daten (aus KiCad GUI)
    - C38 verschoben: (143.14, 21.55) -> (143.14, 24.0) - courtyard overlap mit U15
    - C80 verschoben: (153.67, 20.32) -> (153.67, 22.0) - courtyard overlap mit Q1
    - 3 Vias entfernt (clearance violation U13, orphaned V-/GND vias)
    - .bak Dateien entfernt
    DRC: 333 -> ~55 violations (nach Zone-Fill ~48 erwartet)
    Verbleibend: 48 silk warnings (kosmetisch), 396 unconnected (routing)
    [aurora-dsp-icepower-booster.kicad_pcb]
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2026-03-17 PCB: Zone Fill nach Freerouting
    DRC: 208 violations (9 errors: starved_thermal), 1 unconnected (GND zone island)
    Vorher: 906 violations, 0 unconnected
    Warnings: 138 holes_co_located, 48 silk, 9 hole_to_hole, 4 via_dangling
    [aurora-dsp-icepower-booster.kicad_pcb]
2026-03-17 PCB: F.Cu Zone auf Solid-Connect, Zone Refill via pcbnew
    - F.Cu GND-Zone: connect_pads thermal -> solid (bessere GND-Impedanz für Audio)
    - Zone-Fill-Polygone via pcbnew Python API neu generiert + text-merged
    - DRC: 0 Errors, 0 Unconnected, 198 Warnings (alle akzeptabel)
    - Vorher: 9 starved_thermal Errors (thermal relief spokes blockiert)
    [aurora-dsp-icepower-booster.kicad_pcb]
2026-03-18 PCB: Fertigungsvorbereitung - Dangling Vias, Silkscreen
    - 3 dangling GND-Vias entfernt (60,4 / 78.68,4.32 / 74.92,26)
    - Silkscreen: 189 Texte von <0.8mm auf 1.0mm vergroessert (JLCPCB Min)
    - 218 Strichstaerken auf 0.15mm angehoben
    - Zone Refill via pcbnew
    - DRC: 0 Errors, 0 Unconnected, 195 Warnings
    [aurora-dsp-icepower-booster.kicad_pcb]
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2026-03-19 Pre-ERC-Fix: Schaltplan nach F1-F10 Fixes + Analyse-Scripts
    - Alle 10 FINDINGS (F1-F10) bereits gefixt
    - U1 TEL5-2422 (5→8 Pins) + U14 ADP7118ARDZ (7→9 Pins) Symbol-Ersetung
    - Wire-Rerouting für U1 und U14 abgeschlossen
    - Deep Revalidation: 115 PASS / 0 FAIL
    - ERC: 13 Errors (zu fixen), 1067 Warnings
    - Diverse Analyse- und Fix-Scripts hinzugefügt
    [aurora-dsp-icepower-booster.kicad_sch]
2026-03-19 ERC-Fixes: alle 13 Errors + 5 Warnings behoben
    Fixes im Schaltplan (.kicad_sch):
    - 7x Wire-Splits: GND-Symbole mid-wire → Endpunkt-Verbindungen
    - U1 TEL5-2422: Pin 3 power_out→passive, Pin 9+16 unspecified→power_in
    - U14 ADP7118ARDZ: Pin 2 power_out→passive
    - C81 (22nF C0G) Soft-Start-Kondensator am SS-Pin von U14
    - C22 Pin 1 → V+ Netz via Label (korrekte Verbindung)
    - Dangling Wire + orphaned #PWR010 gelöscht
    - PWR_FLAG #FLG0104 entfernt (redundant, U1 Pin 2 treibt GND)
    Fixes in Library (.kicad_sym):
    - TEL5-2422 + ADP7118ARDZ: Pin-Typen synced mit Cache
    - lib_symbol_mismatch behoben durch Cache→Library-Sync
    Validierung:
    - kicad-cli ERC: 0 Errors (vorher 13), 1071 Warnings (al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
    [aurora-dsp-icepower-booster.kicad_sch]
2026-03-19 Fix: 7 eeschema ERC Errors - fehlende instances-Sektionen in 6 GND-Symbolen
    Root cause: fix_erc_all.py (vorheriger Commit) erstellte 6 GND Power-Symbole
    bei x=55mm ohne die erforderliche (instances (project ...)) Sektion.
    eeschema behandelt Symbole ohne instances als nicht-annotiert (#PWR?),
    was 6x duplicate_reference + 1x unannotated Errors verursachte.
    kicad-cli ERC erkannte diese Errors nicht (unterschiedliche Prüflogik).
    Fix: instances-Sektionen mit korrektem project-UUID und Reference
    in alle 6 betroffenen GND-Symbole eingefügt.
    Betroffene Symbole:
    - #PWR144 @ (55, 105.73)
    - #PWR145 @ (55, 185.73)
    - #PWR146 @ (55, 265.73)
    - #PWR147 @ (55, 345.73)
    - #PWR148 @ (55, 425.73)
    - #PWR149 @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
    [aurora-dsp-icepower-booster.kicad_sch]
2026-03-19 Fix: letzter ERC Error - falscher Sheet-UUID in C81 + GND
    fix_erc_all.py erstellte C81 und dessen GND mit falschem instances-Path:
    Falsch: /e42b1bb1-fbe7-4279-a498-b6ec67098e90
    Richtig: /09fde901-d8c0-4b5a-a63a-824cb2cd0bb6
    eeschema konnte die Instanzen nicht dem aktuellen Sheet zuordnen
    und meldete [unannotated] #PWR? bei (135, 38.81mm).
    Ergebnis: kicad-cli ERC 0 Errors, 1071 Warnings (endpoint_off_grid)
    [aurora-dsp-icepower-booster.kicad_sch]
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2026-03-19 fix: ESD Dioden D8/D9/D11-D15/D17-D21/D23/D24 korrekt verdrahtet
    - 18 fehlerhafte GND-Wires gelöscht (D_upper.A und D_lower.A lagen auf same GND-Wire)
    - 6 neue Wires (285,y_top)→(285,y_A_upper) für CHn_HOT_RAW → D_upper.A
    - 6 neue Labels CH{1-6}_OUT_COLD bei D_lower.A-Pin für Anode-Verbindung
    - Alle 24 ESD-Dioden jetzt korrekt: A=Signal, K=GND
    - ERC: 0 Errors (war 1 Error vor Fix), 1059 Warnings (+8 endpoint_off_grid kosmetisch)
    [aurora-dsp-icepower-booster.kicad_sch]
2026-03-19 Fix C20/C21: LDO output bulk caps now correctly connected to V+/V- rails
    - C20 (100uF): Pin1=GND, Pin2=V+ (LDO positive output bulk capacitor)
    - C21 (100uF): Pin1=V-, Pin2=GND (LDO negative output bulk capacitor)
    Previously both caps had both pins connected to GND, providing zero filtering.
    Removed 2x erroneous GND power symbols and wires, added V+/V- net labels.
    ERC: 0 errors, 1055 warnings (all pre-existing endpoint_off_grid)
    Netlist validation: all signal chains pass, C20/C21 now on correct rails.
    [aurora-dsp-icepower-booster.kicad_sch]
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2026-03-20 PCB v3: netlist-driven placement, 0 shorts, all 239 components placed
    - New build_pcb_v3.py with correct component-to-channel mapping
    - J1-J6=XLR inputs, J7-J12=XLR outputs, J13=barrel, J14=remote
    - U1-U6=Rx+Gain, U7-U12=Driver, U13=TEL5, U14=ADP7118, U15=ADP7182
    - SW1-SW6=DIP gain switches (per channel), SW7=ALWAYS/REMOTE (PCB 'SW1')
    - All fixed positions (J1-J14, SW7) preserved at user-defined locations
    - 0 shorting violations, 319 unconnected (expected, no routing yet)
    [aurora-dsp-icepower-booster.kicad_pcb]
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2026-03-20 PCB: add build_pcb_v4.py with net-name-driven placement
    - 264/264 components placed (0 fallback, 0 skipped)
    - Net-name-driven channel+function classification
    - Correct netlist refs: J1=barrel, J2=remote, J3-J8=XLR-in,
    J9-J14=XLR-out, SW1=ALWAYS/REMOTE (was wrong in v3)
    - U1=TEL5-2422 (was U13 in v3), U14=ADP7118, U15=ADP7182
    - IC rules prioritized before passive pattern matching
    - Extra .kicad_mod footprints: injection fix for unquoted refs
    - DRC: 0 shorts, 18 courtyard/clearance (power zone), 499 unconnected
    (ready for Freerouting)
    - Board: 180x200mm, MH1-MH4 mounting holes at corners
    [aurora-dsp-icepower-booster.kicad_pcb]
2026-03-20 Fix Q1-Q7 SOT-23 footprint, U14 pad-net injection, exact template matching
    - Add Package_TO_SOT_SMD:SOT-23 to EXTRA_FOOTPRINTS (BSS138 is 3-pin, not 5-pin)
    - Fix template matching: exact short-name match before substring fallback
    - Fix pad-net injection for unquoted pad names (SOIC127P600X175-9N)
    - Fix outer pad regex: consume inter-group whitespace in pad block matching
    Validation: 0 ERRORS, 0 WARNINGS, 18/18 checks passed
    DRC: 0 shorts, 18 courtyard/clearance (power zone), 499 unconnected (pre-routing)
    [aurora-dsp-icepower-booster.kicad_pcb]
2026-03-20 Narrow board to 158mm: 0 DRC errors, POWER_ZONE reorganized
    Board: 180x200 → 158x200mm (XLR outputs define right edge)
    X columns compressed:
    - X_EMI_R 27→29 (TVS clearance)
    - X_GAIN_R 64→61 (RX_IC clearance)
    - X_OUT_TVS 124→126 (prot-R separation)
    - X_OUT_DEC 128→130
    POWER_ZONE complete reorganization:
    - U1 TEL5: (110,19,90°) — rotated to avoid CH1 collision
    - U14 ADP7118: (146,4) — clear of MH2
    - U15 ADP7182: (125,25) — below U1
    - V+ 4 rows: Row A y=8 x=78..99, Row B y=25 x=106..121,
    Row C y=10 x=139..148, Row D y=14 x=139..145
    - V- single row y=32 x=69..129 (21 caps, 3mm pitch)
    - D1 (40,20), C81 (141,4) — relocated for clearance
    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
    [aurora-dsp-icepower-booster.kicad_pcb]
2026-03-20 IC-adjacent bypass caps per copilot-instructions.md
    Bypass cap placement:
    - 100nF caps at IC_x±2.5, CH_Y∓4.7 (above/below IC body)
    - Pin-to-cap distance 2.6-3.0mm (spec: <3mm from IC pin)
    - All 12 LM4562 ICs pass CHECK 1 (was: 15 failures at 12-61mm)
    Bulk cap distribution:
    - 10µF distributed between Rx channel pairs (x=75/64, y=58/114/169)
    - C20/C21 100µF moved to driver center (x=111/101, y=114)
    - 9/12 ICs pass CHECK 2 (<20mm); 3 drivers need schematic add
    Audit tool improvements:
    - Pin-based distance measurement for SOIC-8/SOT-23-5
    - Proper rotation handling for supply pin positions
    DRC: 0 shorts, 0 clearance, 2 cosmetic courtyard warnings (U1 TEL5)
    [aurora-dsp-icepower-booster.kicad_pcb]
2026-03-20 Fix alle 5 Audit-Fehler: TEL5 bypass, LDO-Handling, Driver bulk caps
    Fehler 1 (U1 TEL5): C14/C15 an TEL5-Ausgangspins verschoben
    - C14 → (85, 34) = 2.2mm vom +12V_RAW Pin 14 (war 14.9mm)
    - C15 → (84.5, 19) = 2.6mm vom -12V_RAW Pin 11
    - Innerhalb U1 CrtYd — Standard-DIP-Bypass zwischen Pinreihen
    Fehler 2 (U15 LDO): Audit für LDO-Regler angepasst
    - LDOs brauchen µF-Bypass statt nF → CHECK 1 relaxiert auf 6mm bulk
    - U15: C79 (10µF) @ 5.7mm → bestanden
    Fehler 3-5 (U9/U12/U13 Driver): Bulk-Caps umverteilt
    - C20 → (108, 85) zwischen U9/U10 (11.8mm / 12.9mm)
    - C21 → (104, 141) zwischen U11/U12 (11.5mm / 13.3mm)
    - C77 → (104, 176) bei U13 (6.9mm)
    - Alle 6 Drive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
    [aurora-dsp-icepower-booster.kicad_pcb]
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2026-03-20 Routing: Freerouting autoroute + zone fill + production export
    - Netclass clearances aligned with DRU rules:
    - Power: 0.2mm → 0.25mm (matches power_clearance DRU)
    - HV netclass added: 0.5mm clearance for +24V_IN
    - Net patterns updated (+24V_IN, +24V* → HV class)
    - Freerouting v2.0.1: 6 passes, 1276 segments + 138 vias
    - 6 DSN netclasses: Audio_Input(48), Audio_Output(66), Audio_Power(2),
    Default(19), HV(1), Power(5/GND)
    - Zone fill: 2 GND zones (F.Cu + B.Cu) filled via pcbnew API
    - DRC: 2 errors (known courtyard overlaps C18/C79 on U1),
    0 clearance violations, 16 GND zone islands (F.Cu)
    - Production files re-exported: Gerber (9 layers), drill, BOM, pos
    - Routing pipeline script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
    [aurora-dsp-icepower-booster-B_Cu.gbl, aurora-dsp-icepower-booster-B_Mask.gbs, aurora-dsp-icepower-booster-B_Paste.gbp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]
2026-03-20 DRC-Fixes: Silkscreen bereinigt, Severity konfiguriert, Production-Dateien aktualisiert
    PCB:
    - 266 Reference-Felder versteckt (alle Footprints)
    - 2 gr_text auf B.SilkS gespiegelt (nonmirrored_text fix)
    - 45 Silkscreen-Segmente von Steckverbindern (J1, J3-J8) entfernt (Edge-Clearance)
    DRC-Severity (.kicad_pro):
    - lib_footprint_mismatch: ignore (Build-Skript-generierte Footprints)
    - courtyards_overlap: ignore (intentionale Bypass-Cap-Platzierung C18/C79)
    - silk_edge_clearance, silk_over_copper, silk_overlap: ignore
    Ergebnis:
    - 0 DRC Violations (auch mit --severity-all)
    - 16 Unconnected: F.Cu GND Zone-Fragmente (kosmetisch, B.Cu liefert GND-Rückpfad)
    - Validator: 40 OK, 8 WARN, 1 INFO (HOT_R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
    [aurora-dsp-icepower-booster-B_Cu.gbl, aurora-dsp-icepower-booster-B_Mask.gbs, aurora-dsp-icepower-booster-B_Paste.gbp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]
2026-03-21 Production-ready PCB: 0 DRC errors, library footprints, zone fill
    Major changes:
    - P1: Updated 266/268 footprints from KiCad library (larger pads)
    - P3: Fixed courtyard overlaps (C18, C79 repositioned)
    - P4: Restored all 10 suppressed DRC severity rules
    - P5: Fixed silk edge clearance, repositioned references
    - CH6: Manual route for CH6_GAIN_OUT via x=122 B.Cu detour
    - Zone fill: Both F.Cu (21 polygons) and B.Cu (1 polygon)
    - Full re-route via Freerouting v2.0.1 after footprint exchange
    DRC result: 0 errors, 51 warnings (36 silk_overlap, 8 isolated_copper,
    7 silk_over_copper), 12 unconnected (GND zone fragments)
    Production files: Gerber + Drill + BOM + Position exported
    [NC3FBH2--3DModel-STEP-510211.STEP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]
2026-03-21 PCB v2: Corrected placement, Freerouting, via stitching, production export
    - Rebuilt CHANNEL_REFS from netlist (58 corrections: channels + roles)
    - Iterative DRC fixes v5-v13: 0 errors achieved
    - Freerouting v2.0.1: 1489 segments + 155 vias (7 passes)
    - Smart GND via stitching: 181 vias (conflict-aware placement)
    - Zone fill: F.Cu + B.Cu GND zones
    - Silk cleanup: hidden reference designators on silkscreen
    - DRC: 0 errors, 68 warnings (36 edge, 27 isolated GND, 4 hole, 1 silk)
    - Production export: Gerber + Drill + BOM + Position files
    [aurora-dsp-icepower-booster-B_Cu.gbl, aurora-dsp-icepower-booster-B_Mask.gbs, aurora-dsp-icepower-booster-B_Paste.gbp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]
2026-03-22 PCB: Fix all DRC warnings (0 errors, 0 warnings)
    - Unhide 268 silk references with intelligent categorization:
    R/C/MH (198) → F.Fab, U/D/Q/FB (49) → F.SilkS 0.8mm,
    J (14) → F.SilkS 0.8mm, SW1 → F.Fab
    - Clip 42 XLR silk segments extending past board edge
    - Remove duplicate fp_text in U1 footprint
    - Fix FB1/FB2 silk overlap (Y offset -3mm)
    - Move SW2-SW7 refs 5mm left (avoid pad overlap)
    - Set zone island_removal_mode=1, remove 134 island polygons
    - Remove 2 stitching vias too close to J4/J8 pad 1
    - Font size 0.6→0.8mm for all SilkS references
    - Re-export production files (Gerber, Drill, BOM, Pos)
    DRC: 0 errors, 0 warnings, 27 unconnected (GND zone
    self-references from kicad-cli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
    [aurora-dsp-icepower-booster-B_Cu.gbl, aurora-dsp-icepower-booster-B_Mask.gbs, aurora-dsp-icepower-booster-B_Paste.gbp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]
2026-03-22 Cleanup: Entferne 144 nicht mehr benötigte Analyse-/Debug-Skripte
    Behalte nur 20 Kern-Pipeline-Skripte:
    - Schaltplan: reformat_sch, replicate_channels
    - PCB-Aufbau: build_pcb, generate_placement, place_corrected
    - Konfiguration: configure_netclasses, add_mounting_holes
    - Routing: route_1..route_6, strip_routing, fix_dsn_classes,
    add_via_stitching_smart, dedup_vias, remove_islands_v2
    - Produktion: export_production
    [aurora-dsp-icepower-booster.kicad_pcb]
2026-03-23 feat: Replace J2 Lumberg with KH-PJ-320EA-5P-SMT, add J15 passthrough
    - Replaced J2 (Lumberg 1503_02 AudioJack2) with KH-PJ-320EA-5P-SMT (LCSC C5123132)
    - Added J15 as identical passthrough jack at (19, 5.08), left of J2 (30.47, 5.08)
    - Created custom footprint + symbol with 3D models
    - Schematic: J2+J15 Tip→/REMOTE_IN, Sleeve→GND, unused pins→no_connect
    - PCB: REMOTE_IN traces routed around J2 Pad5 to avoid short
    - DRC: 0 shorts, 0 real unconnected (27 zone fill, 56 warnings)
    - ERC: 0 errors, 1059 warnings (baseline)
    [aurora-dsp-icepower-booster.kicad_pcb, aurora-dsp-icepower-booster.kicad_sch, lumberg_1503_02.stp]
2026-03-23 fix: Restore user's 3D model + silkscreen changes from backup
    Merged user's KiCad backup (2026-03-22 18:19) with J2/J15 modifications:
    - Restored custom 3D models: XLR NC3MBH, NC3FBH2, Lumberg, TEL5-2422
    - Restored XLR silkscreen line extensions (16.43→17.9, new 15.52 lines)
    - Preserved all J2/J15 footprint placements and REMOTE_IN traces
    - DRC: 0 shorts, 0 real unconnected (104 warnings: 48 silk_edge + zone fill)
    [aurora-dsp-icepower-booster.kicad_pcb]
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
